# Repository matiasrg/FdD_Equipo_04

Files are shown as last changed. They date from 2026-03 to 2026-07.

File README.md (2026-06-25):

# FdD_Equipo_04

<strong> Carrera de Ingenieria Ambiental/ Informática / Industrial </strong>
<br>
Universidad Peruana Cayetano Heredia 

# Introducción
<br>
Actualmente, se observa una creciente preocupación en la población respecto a la desinformación o al escaso conocimiento sobre las condiciones climáticas, lo cual puede generar consecuencias en la salud, especialmente en la aparición o agravamiento de enfermedades. En ciudades como Lima, esta problemática se acentúa debido a los cambios climáticos repentinos e impredecibles, que dificultan que las personas sepan cómo prepararse adecuadamente antes de salir de casa.
<br>
<br>
Frente a esta situación, se propone el desarrollo de un dispositivo equipado con sensores de humedad, temperatura y radiación, capaz de recopilar datos ambientales en tiempo real. Esta información será transmitida mediante un módulo ESP32 a una aplicación móvil, la cual brindará recomendaciones personalizadas al usuario, como por ejemplo: “Recuerda aplicar bloqueador”, contribuyendo así a una mejor prevención y cuidado de la salud.

# Situación problemática
En la actualidad, se evidencia una creciente problemática relacionada con la falta de acceso a información ambiental confiable y en tiempo real. Muchas personas no cuentan con datos precisos sobre variables como la temperatura, la humedad o la radiación solar, lo que dificulta la toma de decisiones informadas para el cuidado de su salud.

Esta situación se agrava en ciudades como Lima, donde los cambios climáticos suelen ser repentinos e impredecibles, generando confusión en la población sobre cómo prepararse antes de salir de casa. Como consecuencia, se incrementa la exposición a riesgos como la radiación solar, cambios bruscos de temperatura o condiciones ambientales inadecuadas que pueden afectar el bienestar físico.

Además, la falta de información adecuada favorece la desinformación y limita la capacidad de las personas para tomar decisiones basadas en evidencia, ya que la información errónea o poco clara puede generar confusión, desconfianza y conductas inadecuadas frente al cuidado de la salud y el ambiente.[1]  ￼

En este contexto, se identifica una brecha importante entre la disponibilidad de datos ambientales y su acceso comprensible y útil para la población, lo cual impacta directamente en la salud (ODS 3), el consumo responsable (ODS 12) y la acción frente al cambio climático (ODS 13).
<br> 
# Problema integrador
<br>
A pesar de la disponibilidad de tecnologías capaces de medir variables ambientales como la temperatura, humedad y radiación solar, actualmente no existen soluciones accesibles e integradas que permitan recopilar, procesar y comunicar esta información en tiempo real de manera clara y útil para los usuarios.

Esta limitación impide que las personas tomen decisiones informadas sobre su cuidado diario, exponiéndolas a riesgos prevenibles y dificultando su adaptación a las condiciones climáticas cambiantes.

Por ello, surge la necesidad de desarrollar un sistema tecnológico que integre sensores ambientales con una plataforma digital capaz de transformar los datos obtenidos en recomendaciones prácticas, contribuyendo así a mejorar la calidad de vida y fomentar una mayor conciencia ambiental.

# Presentación de la solución 

La idea del proyecto es un aparato que tenga sensores de temperatura, humedad y radiación. Estos se comunican mediante el ESP32 a una aplicación móvil que da recomendaciones al usuario de tipo "recuerda aplicar bloqueador" o "no olvides tu abrigo".
<br>
<br>
<strong> Listas de exigencias que debemos cumplir: <strong>
<br>
1. Asumir el problema en forma crítica.
Estudiantes universitarios el Perú caminan mucho entre clases y paraderos bajo radiación UV extrema (índice 11+), humedad del 80% y temperaturas de 28-33°C, lo que causa quemaduras, deshidratación o golpes de calor; el problema es crítico porque no usan protección por falta de alertas inmediatas, agravado por el cambio climático que intensifica estos riesgos en la costa peruana.
2. Averiguar el estado de la tecnología.
El ESP32 ya integra WiFi/Bluetooth para apps móviles (como Blynk o MIT App Inventor), sensores como DHT22 (temperatura/humedad), SI1145 (UV/radiación); apps dan notificaciones push en tiempo real, con ejemplos como wearables UV (UVI Monitor) o estaciones meteorológicas portátiles, pero faltan soluciones integrales solares y locales para Perú.
3. Analizar la situación del problema.
En el Perú, la radiación alta por nubosidad engañosa (sensación térmica bochornosa), humedad costera y calor urbano afectan a 70% de jóvenes sin hábitos preventivos; ODS 13 aplica por adaptación climática, ODS 7 por recarga solar (reduce baterías desechables), ODS 12 por diseño modular.
4. Comprobar las posibilidades de realización.
Con respecto a los costos, esto es viable con ESP32 (costo $45), sensores ($20 c/u) y app gratuita; prototipo en 2 semanas con Arduino IDE; pruebas en Lima confirman precisión (DHT22 ±2%, SI1145 UVI ±10%); 
<br>

# 🌎 Descripción del grupo
Somos el equipo 04 del curso <strong> Fundamentos de diseño 2026-01 </strong>, ingenieria Informatica/Ambiental/Industrial. 
<br>
Nuestro objetivo es aplicar la metodología de diseño para generar soluciones innovadoras con impacto social, tecnológico y ambiental.
Nos interesa trabajar en los siguientes Objetivos de Desarrollo Sostenible (ODS):

ODS 3: Salud y bienestar
<br>
Al convertir datos ambientales en alertas personalizadas, ayudamos a los usuarios a protegerse antes de que el daño ocurra, contribuyendo así a la meta del ODS 3 de reducir enfermedades no transmisibles mediante la prevención y la promoción del bienestar.[2]

ODS 7: Energia asequible y no contaminante.
<br>
Para que nuestra propuesta sea coherente, promueve el uso eficiente de la energía. Al medir temperatura, humedad y radiación, permite que los usuarios tomen decisiones como reducir el uso de aire acondicionado, calefacción o iluminación artificial, disminuyendo así el consumo energético.[2]

<br>
ODS 12: Producción y consumo responsable.
<br>
<br>
Nuestra prioridad es prolongar la vida útil del equipo. En lugar de crear un producto desechable, nos inclinamos por un diseño reparable y reacondicionable. Esto significa que el aparato estará pensado para que sus piezas puedan ser revisadas o cambiadas fácilmente si se desgastan. Al evitar que el dispositivo se convierta en basura tecnológica prematura, fomentamos un consumo responsable donde la durabilidad es la característica principal, asegurando que la inversión de la comunidad rinda por mucho más tiempo.[2]

<br>
<br>
ODS 13: Acción por el clima
<br>
<br>
Queremos enfocarnos en combatir los efectos del cambio climático que afectan la salud física. Estamos expuestos constantemente a niveles de humedad y radiación que han dejado de ser normales. Nuestra intención es ofrecer una herramienta de protección que ayude a las personas a adaptarse a estos riesgos. Al transformar los datos del clima en alertas directas, permitimos que la gente tome acciones inmediatas para evitar daños por la exposición prolongada, enfrentando así las consecuencias reales del calentamiento global en nuestro entorno local.
<br>[2]

#  📸 Fotografia del equipo 
<p align="center">
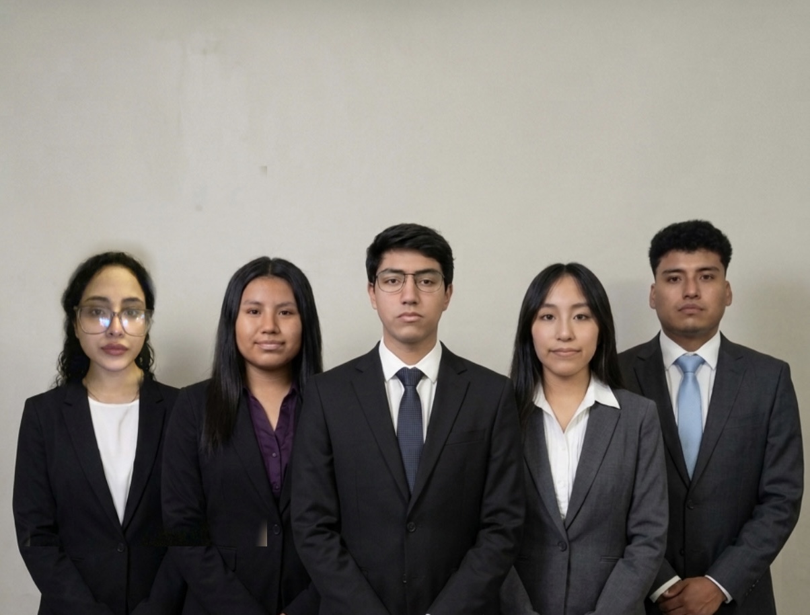
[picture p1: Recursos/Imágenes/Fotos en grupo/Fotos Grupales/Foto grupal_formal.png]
grupal

  <em>
  Figura 1. Fotografia del Equipo 4
</p>

#  👥  Integrantes del equipo 

| Foto | Nombre | Rol | Intereses | 
| ---- | --- | --- | --- |
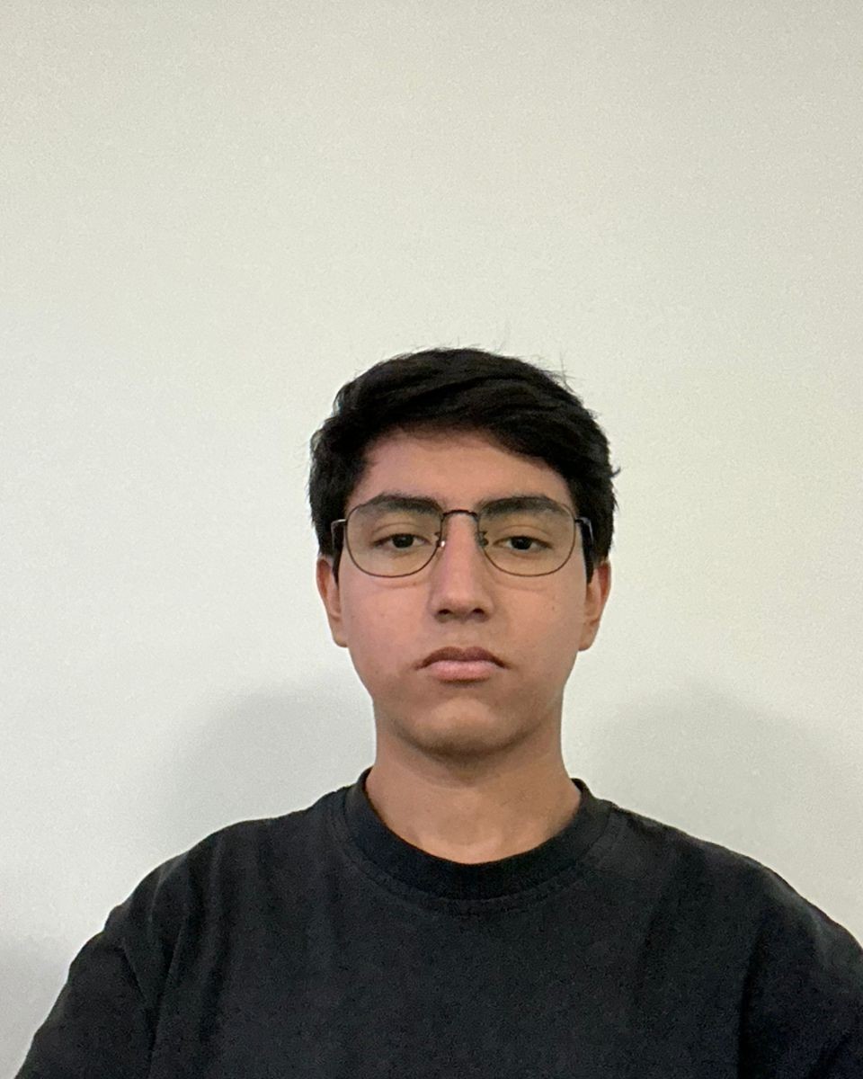
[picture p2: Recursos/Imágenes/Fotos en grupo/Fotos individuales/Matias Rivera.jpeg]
|  | Matías Rivera | Lider del grupo | Innovación social, sostenibilidad |
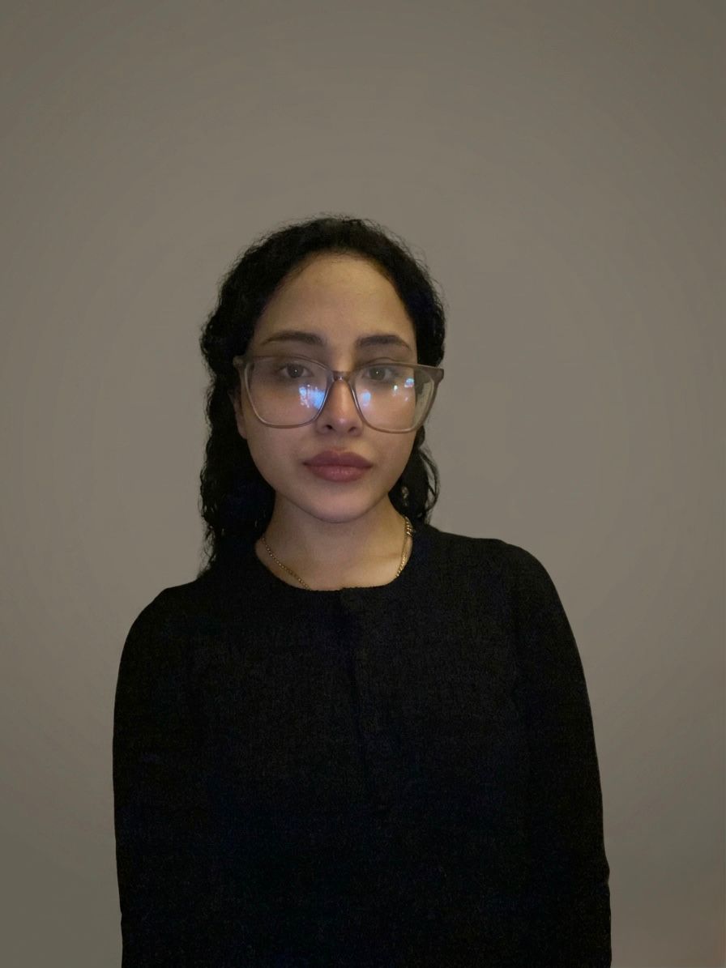
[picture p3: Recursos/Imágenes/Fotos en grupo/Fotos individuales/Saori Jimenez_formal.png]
|  | Saori Jiménez| Programador | Programación, análisis de datos, prototipado | 
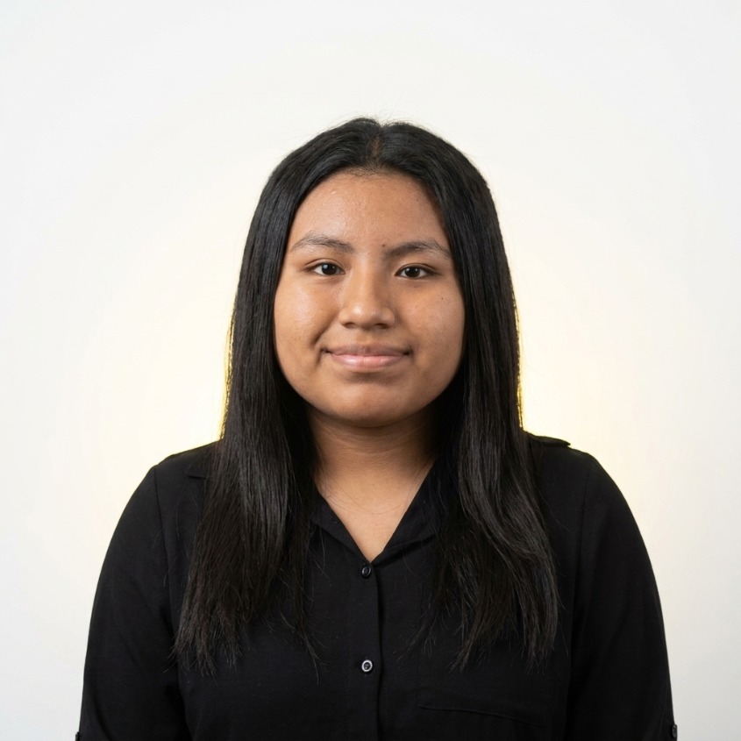
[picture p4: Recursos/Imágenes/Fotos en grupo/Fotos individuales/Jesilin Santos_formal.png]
| | Jesilin Santos| Responsable de investigación | Analisis de problemáticas, Enfoque de soluciones responsables | 
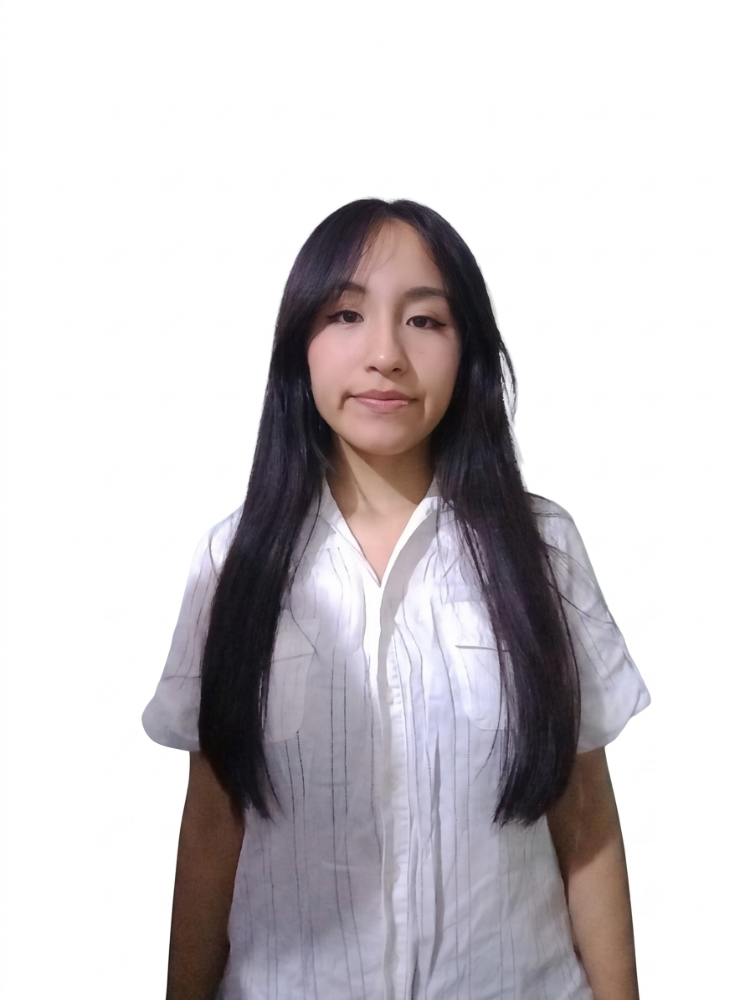
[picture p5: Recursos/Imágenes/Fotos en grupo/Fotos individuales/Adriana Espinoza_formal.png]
|  | Adriana Espinoza| Diseñadora | Prototipo y maquetas | Creatividad estetica |
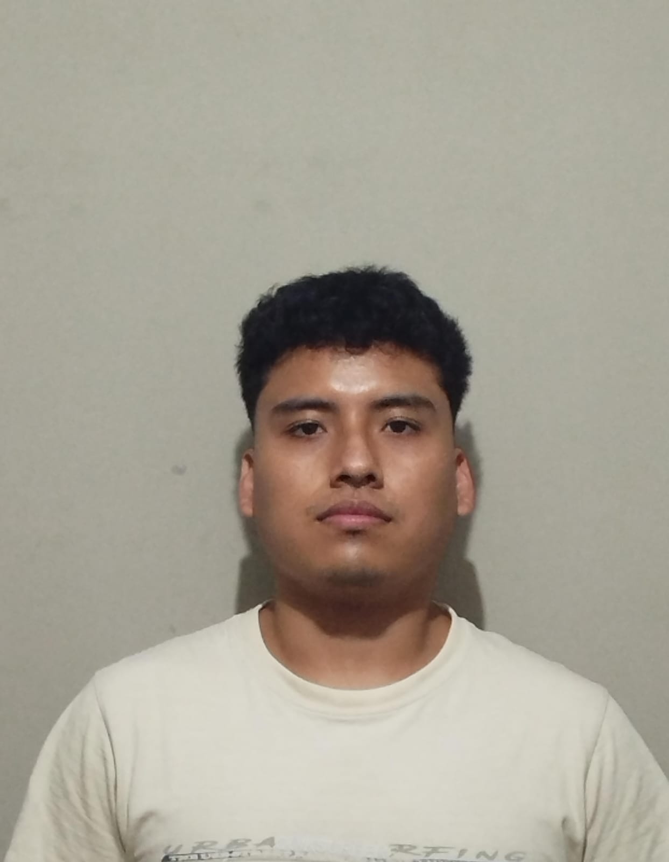
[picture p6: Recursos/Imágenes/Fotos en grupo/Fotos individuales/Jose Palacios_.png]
|  | Jose Palacios| Encargado/a de documentación | documentación científica, redacción técnica | 

# Referencias 
1. García-Delgado Giménez B, Revilla Guijarro A. Educación climática en la universidad: aplicación del Test CRAAP contra la desinformación. Rev Iberoam Educ. 2026;100(1):141-159.
https://rieoei.org/RIE/article/view/7135
2. Programa de las Naciones Unidas para el Desarrollo (PNUD). Objetivo 3: Salud y Bienestar. En: Objetivos de Desarrollo Sostenible [Internet]. Nueva York: PNUD; 2015 [citado 20 abr 2026]. Disponible en: https://www.undp.org/es/sustainable-development-goals

# 📌Resumen final 
Este README resume quiénes somos, qué nos motiva y en qué ODS queremos enfocar nuestro trabajo durante el curso

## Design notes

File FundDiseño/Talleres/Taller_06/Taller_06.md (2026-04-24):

# Matriz de desk research
| N° | Fuente | Autor/Institución | Año | Referencia | Estado de Tecnología encontrada | Exigencia o requisito identificado | Restricción o limitación | Función principal | Aplicación al proyecto |
|:--:|:---|:---|:--:|:---|:---|:---|:---|:---|:---|
| 1 | Guía internacional | OMS / OMM / PNUMA / ICNIRP | 2002/2003 | *Global Solar UV Index: A Practical Guide*:<br> https://www.who.int/publications/i/item/9241590076| Estándar internacional para medir y comunicar riesgo UV. Escala IUV 1–11+ con 5 categorías (bajo, moderado, alto, muy alto, extremo). Adoptado globalmente por servicios meteorológicos y autoridades sanitarias. | Usar la escala IUV como referencia oficial para alertas de salud pública; recomendar medidas de protección desde IUV ≥ 3; estandarizar colores y pictogramas de comunicación. | El sensor UV de bajo costo integrado al ESP32 puede no replicar con exactitud la escala IUV definida por la OMS; se requiere calibración y validación del sensor frente a mediciones de referencia. | Estandarización del índice UV para comunicación de riesgo al público y a autoridades sanitarias a escala mundial. | Define la escala que el sensor UV del dispositivo ESP32 debe usar para clasificar lecturas y generar recomendaciones personalizadas en la app. |
| 2 | Reglamento peruano | Estado Peruano – Diario Oficial El Peruano | 2024 | Decreto publicado en El Peruano (NL/2266130-1):<br> https://busquedas.elperuano.pe/dispositivo/NL/2266130-1 | Existen lineamientos para asegurar la calidad regulatoria, claridad y eficiencia en la implementación de soluciones tecnológicas en el ámbito público | - El sistema debe diseñarse de manera clara, eficiente y aplicable para su implementación en instituciones como universidades o municipalidades<br><br> - Identificar y alertar sobre el rango horario crítico (10:00–16:00 según la normativa) en el que se debe evitar la exposición. | Requiere validación institucional y adaptación a normativas locales. | Garantizar viabilidad y aplicación en el sector público | El proyecto se orienta a ser implementado como servicio en espacios públicos bajo regulación peruana |

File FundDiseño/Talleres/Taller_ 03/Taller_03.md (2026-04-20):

# Introducción

# Situación Problemática

En la actualidad, la exposición a condiciones ambientales adversas como la radiación ultravioleta, la alta humedad y las elevadas temperaturas representa un riesgo significativo para la salud, especialmente en zonas urbanas como Lima. La radiación UV, en particular, está asociada a efectos nocivos como quemaduras solares y un mayor riesgo de cáncer de piel, lo que hace fundamental la adopción de medidas preventivas oportunas [2,5]. Esta problemática se enmarca directamente en el ODS 3 (Salud y Bienestar), cuya meta 3.4 busca reducir la mortalidad prematura por enfermedades no transmisibles mediante la prevención y la promoción de la salud [9].

Sin embargo, muchas personas no cuentan con acceso a información ambiental clara, confiable y en tiempo real, lo que dificulta la toma de decisiones adecuadas para su protección. Esta situación se ve agravada por la desinformación y la falta de educación climática, limitando la capacidad de la población para actuar de manera preventiva frente a estos riesgos [1].

A pesar de que existen tecnologías capaces de medir variables como temperatura, humedad y radiación UV mediante sensores y sistemas IoT, estas soluciones no suelen estar integradas en herramientas accesibles y prácticas para el uso cotidiano [3,4,6]. Diversos estudios han demostrado que el monitoreo en tiempo real y el uso de alertas pueden mejorar significativamente la prevención, especialmente en jóvenes expuestos constantemente a estas condiciones [7,8].

Frente a esta problemática, el presente proyecto propone el desarrollo de un dispositivo portátil equipado con sensores ambientales y un módulo ESP32, capaz de recopilar datos en tiempo real y transmitirlos a una aplicación móvil. Esta aplicación procesará la información y brindará recomendaciones personalizadas al usuario, como el uso de bloqueador solar o abrigo, contribuyendo así a la prevención de riesgos, la mejora de la calidad de vida y la promoción de la conciencia ambiental. Con ello, el proyecto se alinea con el ODS 3, el ODS 12 (Producción y Consumo Responsable) y el ODS 13 (Acción por el Clima), siendo la prevención en salud su eje central. 

# Propuesta de solución
En respuesta a esta problemática, se plantea la necesidad de implementar un sistema tecnológico, cuyo enfoque está basado en la utilización de Internet de las Cosas (IoT), para realizar el monitoreo del ambiente en tiempo real y proporcionar recomendaciones personales acerca de cómo evitar riesgos a la salud. Para lograr este fin, se considerará la utilización de un pequeño dispositivo portátil, dotado con sensores de temperatura, humedad y radiación ultravioleta, conectado a un microcontrolador ESP32 capaz de transmitir los datos de estas mediciones.

Esta propuesta tecnológica se sustenta en los estudios existentes relacionados con soluciones IoT en el monitoreo ambiental que han resultado exitosos debido a su capacidad para recolectar información sobre variables climáticas en tiempo real y facilitar la toma de decisiones frente a situaciones adversas [4]. Por tanto, la implementación de un microcontrolador ESP32, por ejemplo, permitiría la transferencia inalámbrica de estos datos al usuario a través de una aplicación móvil.

En segundo lugar, la aplicación móvil que se asocia con el sistema deberá cumplir con la función primordial de analizar los datos recolectados e informar acerca de las recomendaciones personalizadas para el usuario, tales como aplicarse protector solar, hidratarse o protegerse frente a posibles variaciones de temperatura. Numerosos estudios han demostrado que la utilización de un sensor de radiación UV junto a una aplicación móvil puede aumentar de manera significativa las acciones de protección frente al sol, siendo particularmente efectiva para jóvenes gracias a sus alertas en tiempo real que evitan posibles quemaduras [8].

También teniendo en cuenta el entorno peruano, en el que la radiación solar es bastante alta durante todo el año, esta solución adquiere una relevancia especial. En Perú ha sido demostrada la importancia de la prevención y diagnóstico tempranos del melanoma cutáneo, con el uso de métodos preventivos basados en la educación para protegerse de los rayos solares [5]. Garantizar el acceso a herramientas de prevención accesibles para la población constituye, además, una contribución concreta al ODS 3, al reducir la exposición a riesgos ambientales que derivan en enfermedades prevenibles [9].

En general, esta propuesta intenta combinar la incorporación de tecnología fácil de usar, un sistema de monitoreo en tiempo real y medidas de prevención para la salud, no solo ayudando a minimizar los riesgos derivados de entornos adversos, sino que también promoviendo una mejor sensibilización ambiental y prácticas saludables.

# Objetivos
## Objetivo general
Diseñar e implementar un prototipo capaz de registrar y monitorear mediciones ambientales locales mediante sensores de temperatura, humedad y radiación UV integrados a un microcontrolador ESP32, y vinculado a una aplicación móvil que procese estos datos en tiempo real para brindar recomendaciones personalizadas de protección y prevención a los usuarios, promoviendo el cuidado de la salud en línea con el ODS 3, y la toma de decisiones informadas frente a condiciones ambientales adversas.
## Objetivos especificos
1. Averiguar el estado del arte en sistemas de monitoreo ambiental basados en IoT, sensores de temperatura, humedad y radiación; así como el uso del ESP32 en este ámbito.
2. Evaluar la viabilidad técnica y económica del desarrollo del prototipo que incluye ESP32, sensores, conectividad y plataforma de desarrollo.
3. Diseñar la arquitectura del sistema, definiendo la integración entre el hardware y la aplicación web/móvil.
4. Construir e implementar el prototipo físico.
5. Desarrollar la aplicación web/móvil que procese los datos recibidos y genere alertas y recomendaciones automáticas (ej. uso de bloqueador o abrigo)
6. Realizar pruebas experimentales en condiciones reales para verificar la transmisión de datos, estabilidad del sistema y respuesta de la aplicación.
7. Evaluar el desempeño del sistema analizando la precisión de los sensores, la eficiencia de la comunicación y la utilidad de las recomendaciones en la prevención de riesgos.

# Bibliografía

1. García-Delgado Giménez B, Revilla Guiijarro A. Educación climática en la universidad: aplicación del Test CRAAP contra la desinformación. RIEOEI [Internet]. 30 de enero de 2026 [citado 8 de abril de 2026];100(1):141-59. 
Disponible en: https://rieoei.org/RIE/article/view/7135

2. Organización Mundial de la Salud. Radiación ultravioleta: protección solar y prevención del cáncer de piel [Internet]. Ginebra: OMS; 2022 [citado 7 abr 2026]. Disponible en: https://www.who.int/news-room/fact-sheets/detail/ultraviolet-radiation

3. Alquinga Arequipa FC, Triviño D. Desarrollo e implementación de un dispositivo “Wearable” para el análisis de temperatura, humedad, incidencia de rayos ultravioletas (UV) y presión atmosférica para personas que realizan montañismo. Quito: Escuela Politécnica del Ejército (ESPE); 2017. Disponible en: https://redi.cedia.edu.ec/document/116763.

4. Desarrollo de una estación IoT para monitoreo de microclimas y condiciones del suelo. Rev Ing UPT. 2021. Disponible en: https://revistas.upt.edu.pe/ojs/index.php/ingenieria/article/download/1167/1058.

5. Sordo C, Gutiérrez C. Cáncer de piel y radiación solar: experiencia peruana en la prevención y detección temprana del cáncer de piel y melanoma. Rev Peru Med Exp Salud Publica [Internet]. 2013;30(1):106-12. Disponible en: http://www.scielo.org.pe/scielo.php?script=sci_arttext&pid=S1726-46342013000100021&lng=es.

6. Huallpa Huayhua JE, Ayerbe Huarcaya CI. Sistema basado en IOT para monitoreo de parámetros ambientales en crianza de pollos en el IESTP Jorge Basadre Grohman, 2024 [tesis en Internet]. Puerto Maldonado (Madre de Dios, Perú): Universidad Nacional Amazónica de Madre de Dios (UNAMAD); 2024. Disponible en: http://hdl.handle.net/20.500.14070/1460

7. Bhosale P, Kalgaonkar S, Jain D, Bhagwat A. IoT-Based Environmental Monitoring: Tracking Climate Change and Promoting Sustainable Development. En: Internet of Things for Smart Cities and Urban Development [Internet]. Chapman and Hall/CRC; 2025. Disponible en: https://www.taylorfrancis.com/books/9781003539629/chapters/10.1201/9781003539629-3

8. Robinson JK, et al. Real-time UV measurement with a sun protection system for warning young adults about sunburn: prospective cohort study. JMIR mHealth and uHealth. 2016;4(3). Disponible en: https://mhealth.jmir.org/2021/5/e25895

9. Programa de las Naciones Unidas para el Desarrollo (PNUD). Objetivo 3: Salud y Bienestar. En: Objetivos de Desarrollo Sostenible [Internet]. Nueva York: PNUD; 2015 [citado 20 abr 2026]. Disponible en: https://www.undp.org/es/sustainable-development-goals

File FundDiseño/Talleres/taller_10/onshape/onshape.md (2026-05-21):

https://cad.onshape.com/documents/f9a615fb81c0a29481f81119/w/910e831ae7aa793d391d0c5f/e/6db22efc34afd249ac153ec0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

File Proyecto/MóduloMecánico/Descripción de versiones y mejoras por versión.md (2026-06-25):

# Módulo Mecánico - EcoAlerta

## Evolución del Diseño Mecánico y Consolidación de Versiones

El desarrollo del chasis y los componentes de sujeción del dispositivo **EcoAlerta** se estructuró en dos etapas de diseño (v1 y v2), evolucionando desde una distribución analítica de componentes separados hasta un ensamblaje final integrado y acotado para manufactura.

### Versión 1 (v1): Configuración Base y Distribución Espacial
En esta primera etapa se validaron los volúmenes, la distribución interna y las aberturas necesarias para la interacción de los componentes con el entorno:
* **Estructura por Bloques Separados:** Configuración del contenedor principal dividiendo el espacio para alojar de forma independiente los sistemas de energía, control y sensado.
* **Circulación de Aire:** Inclusión de rejillas lineales directamente en el chasis exterior para permitir la ventilación pasiva y la renovación del aire interno.
* **Cavidades de Control e Interfaz:** Apertura de agujeros iniciales destinados a la instalación de un botón de encendido/apagado, fijaciones para tornillos de cierre y perforaciones para el paso de cables mediante prensaestopas.
* **Ventana de Monitoreo UV:** Maquetado de los primeros agujeros en la sección superior de la tapa de los sensores para permitir la exposición del sensor de radiación ultravioleta.

### Versión 2 (vfinal) - Versión Final: Ajustes de Chasis e Integración de Componentes
La v2 constituye el diseño final consolidado. En esta fase se aplicaron las correcciones de tolerancia milimétrica y se incorporaron físicamente todos los elementos comerciales y de hardware dentro del entorno 3D:
* **Estandarización de Perforaciones de Salida:** Ajuste y calibración exacta de los agujeros del contenedor para albergar de forma hermética prensaestopas comerciales de tipo PG7.
* **Ajuste para conector de chasis y switch:** Modificación de las aberturas del panel frontal para asegurar el calce perfecto de un conector de alimentación USB Tipo-C de empotrar y un interruptor general (switch) basculante.
* **Rediseño del Acoplamiento UV:** Modificaciones geométricas en la tapa de los sensores mediante un rebaje circular escalonado para lograr un acoplamiento estanco y seguro del sensor UV, garantizando que quede alineado y protegido frente al exterior.
* **Consolidación del Ensamblaje Electromecánico:** Inclusión real de la arquitectura interna completa dentro del modelo final. Esto abarca el posicionamiento exacto de los prensaestopas, el conector de chasis, el switch, la placa de soporte perforada, el sensor UV y el sensor de temperatura/humedad DHT11.
* **División Estructural de Tapas:** Configuración definitiva de la cubierta superior dividida en dos piezas independientes (Tapa del ESP32 y Tapa de los sensores), optimizando el acceso por separado a la electrónica de procesamiento o al módulo de sensores durante tareas de mantenimiento.

Enlace de Onshape: 
[https://cad.onshape.com/documents/be05ffe52afa9a955caa7767/w/59e88b758aaaabc94f50e5dc/e/23231b023377f0eafd262c30](https://cad.onshape.com/documents/be05ffe52afa9a955caa7767/w/59e88b758aaaabc94f50e5dc/e/23231b023377f0eafd262c30)

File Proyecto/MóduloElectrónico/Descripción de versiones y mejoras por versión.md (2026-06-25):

# Descripción de versiones y mejoras por versión

> Historial de evolución del esquemático electrónico del proyecto EcoAlerta, sistema portátil de monitoreo UV y ambiental basado en ESP32.

---

## Tabla comparativa

| Versión | Microcontrolador | Cambio principal | Bloques presentes |
|---|---|---|---|
| V1.0 | ESP32-DEVKITC-VE | Esquema inicial funcional, con conectores redundantes | Alimentación, Sensor UV, Sensor Temp/Hum, Microcontrolador, Conector Principal, Conector Temp/Hum |
| V2.0 | ESP32-DEVKITC-VE | Limpieza del esquema: se eliminan conectores duplicados | Alimentación, Sensor UV, Sensor Temp/Hum, Microcontrolador |
| V3.0 | ESP32-DEVKITC-VE | Se incorpora el indicador LED | Alimentación, Sensor UV, Sensor Temp/Hum, Microcontrolador, Led |
| V4.0 | ESP32S (U1) | Cambio de microcontrolador y se agrega el interruptor general | Alimentación, Sensor UV, Sensor Temp/Hum, Microcontrolador, Led, Bornera del interruptor, Interruptor |
| V_FINAL | ESP32S (U1) | Se retira el LED indicador, queda la versión definitiva | Alimentación, Sensor UV, Sensor Temp/Hum, Microcontrolador, Bornera del interruptor, Interruptor |

## Versión 1.0

### Descripción

Es la primera versión funcional completa del esquemático de EcoAlerta. Integra el ESP32-DEVKITC-VE (U15) como unidad de control, conectado al sensor de temperatura y humedad (U2) y al sensor UV (U3), además del bloque de alimentación (P1, "FUENTE"). A diferencia de las versiones posteriores, esta versión documenta las mismas señales dos veces: además del bloque "Microcontrolador" y "Sensor de Temperatura y Humedad", existen dos bloques adicionales — "Conector Principal" (U11/J2) y "Conector Temp/Hum" (U16/J1) — que repiten las líneas 3.3V, DATA-TEMP-HUM y GND ya presentes en otros bloques, sin aportar una función eléctrica nueva.

### Elementos característicos de esta versión

- Microcontrolador ESP32-DEVKITC-VE (U15) con su pinout completo de 38 pines.
- Bloques redundantes "Conector Principal" (U11) y "Conector Temp/Hum" (U16), que duplican señales ya presentes en el bloque del sensor de temperatura/humedad.
- No existe bloque de LED indicador.
- No existe interruptor general ni bornera dedicada para él.

---

## Versión 2.0

### Descripción

Se simplifica el esquemático eliminando la duplicación de conectores presente en V1.0. Se mantiene exactamente la misma arquitectura funcional (ESP32-DEVKITC-VE, sensor UV, sensor de temperatura y humedad, alimentación), pero ahora cada señal aparece documentada una sola vez, en su bloque correspondiente.

### Mejoras respecto a la Versión 1.0

- Se eliminan los bloques "Conector Principal" (U11) y "Conector Temp/Hum" (U16), que eran redundantes.
- El esquema queda reducido a cuatro bloques funcionales: Alimentación, Sensor UV, Sensor de Temperatura y Humedad, y Microcontrolador.
- No hay cambios en el microcontrolador ni en los sensores utilizados.

---

## Versión 3.0

### Descripción

Se mantiene la base de V2.0 y se incorpora por primera vez un indicador visual: el bloque "Led" (LED1) con su resistencia limitadora R1 de 10K, conectado directamente a +3.3V. En esta versión el LED todavía no recibe una señal de control independiente desde el ESP32; su encendido depende únicamente de la alimentación de 3.3V.

### Mejoras respecto a la Versión 2.0

- Se añade el bloque "Led" (LED1 + R1 de 10K) como indicador visual del sistema.
- El LED se alimenta desde +3.3V, sin una línea de control dedicada desde el microcontrolador todavía.
- Se mantiene sin cambios el resto de la arquitectura (ESP32-DEVKITC-VE, Sensor UV, Sensor de Temperatura y Humedad, Alimentación).

---

## Versión 4.0

### Descripción

Esta versión introduce dos cambios importantes. Primero, se reemplaza el microcontrolador ESP32-DEVKITC-VE por un módulo ESP32S (U1), con un pinout distinto (D-prefijo en lugar de IO-prefijo). Segundo, se agregan los elementos de interacción manual del sistema: un interruptor general con su propia bornera ("Bornera del interruptor" y "Interruptor"), que permite energizar o desenergizar el circuito entre la línea de +5V del ESP32 y la línea de +5V general. Además, el bloque LED ya no se alimenta de forma fija a 3.3V: ahora recibe una señal de control propia ("LED") directamente desde un pin del ESP32S, lo que permite encenderlo o apagarlo por software.

### Mejoras respecto a la Versión 3.0

- Se reemplaza el microcontrolador ESP32-DEVKITC-VE por el módulo ESP32S (U1).
- Se agregan los bloques "Bornera del interruptor" e "Interruptor", que permiten energizar/desenergizar el circuito manualmente.
- El LED indicador pasa de estar alimentado fijo a 3.3V (V3.0) a recibir una señal de control dedicada desde un pin del ESP32S.
- Se mantienen sin cambios los bloques de Alimentación, Sensor UV y Sensor de Temperatura y Humedad.

---

## Versión Final

### Descripción

Es la versión consolidada para la entrega del proyecto. Mantiene la arquitectura de V4.0 (ESP32S, interruptor general con bornera dedicada, sensores UV y de temperatura/humedad), pero retira por completo el bloque "Led": ya no están presentes ni LED1, ni la resistencia R1, ni la señal de control "LED" en el microcontrolador. El sistema queda definido sin indicador visual a nivel de hardware.

### Mejoras respecto a la Versión 4.0

- Se elimina el bloque "Led" (LED1 y R1 de 10K) y su señal de control dedicada en el ESP32S.
- Se mantienen sin cambios el microcontrolador ESP32S, el interruptor general con su bornera, y los bloques de Sensor UV, Sensor de Temperatura y Humedad, y Alimentación.
- El esquemático queda con seis bloques funcionales: Alimentación, Sensor UV, Sensor de Temperatura y Humedad, Microcontrolador, Bornera del interruptor e Interruptor.

---

## Conclusiones

La evolución del esquemático de EcoAlerta refleja un proceso de diseño iterativo que pasó primero por una etapa de depuración (eliminar conectores redundantes en V2.0), luego por una etapa de incorporación de funciones (LED indicador en V3.0, interruptor general y cambio de microcontrolador en V4.0), y finalmente por una etapa de simplificación del hardware final, donde se decidió retirar el LED indicador para quedarse con un diseño más acotado a las funciones esenciales del sistema: medición UV, medición de temperatura y humedad, alimentación y control manual de encendido mediante el interruptor general.

El cambio más relevante a nivel de plataforma es la migración del ESP32-DEVKITC-VE (V1.0–V3.0) al módulo ESP32S (V4.0–V_FINAL), que coincide con la incorporación del interruptor general como mecanismo de control manual del sistema.

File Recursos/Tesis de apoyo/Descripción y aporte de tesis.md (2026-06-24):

# Descripción y aporte de tesis

> Revisión de tesis de repositorios académicos peruanos relacionadas con monitoreo UV y sistemas IoT ambientales, como respaldo de la viabilidad técnica y contextual de EcoAlerta.

---

## Tabla comparativa

| Tesis | Autor / Año | Institución | Enfoque | Tecnología clave |
|---|---|---|---|---|
| Sistema de sensores inalámbricos para el monitoreo del índice de radiación solar ultravioleta de la ciudad de Huancavelica | Carlos Gonzáles Saenz, 2022 | Universidad Nacional del Centro del Perú | Red de sensores UV en zona altoandina | Nodos inalámbricos UV (ML8511 / LTR390) |
| Sistema basado en IoT para monitoreo de parámetros ambientales en crianza de pollos en el IESTP Jorge Basadre Grohmann | Huallpa Huayhua, 2024 | IESTP Jorge Basadre Grohmann | Monitoreo ambiental en crianza avícola | ESP32 + DHT22 + MQ-135 + MQTT |

## 1. Sistema de sensores inalámbricos para el monitoreo del índice de radiación solar ultravioleta de la ciudad de Huancavelica

**Autor:** Carlos Gonzáles Saenz | **Año:** 2022 | **Institución:** Universidad Nacional del Centro del Perú

### Descripción

Estudio de campo sobre el uso de sensores UV inalámbricos para medir el índice de radiación UV local en la ciudad de Huancavelica. Busca compensar la falta de datos puntuales en zonas altoandinas, donde la radiación alcanza niveles extremos. Se despliegan varios nodos de sensor UV en puntos representativos de la ciudad, cada uno registrando mediciones cada 5 minutos en tiempo real. La validación de los datos se hace mediante métodos estadísticos: correlación de Spearman para precisión y prueba de Kruskal-Wallis para repetitividad temporal.

### Aporte para EcoAlerta

Esta tesis es clave porque corrobora en contexto peruano que los sensores UV portátiles pueden ofrecer mediciones de alta precisión, lo cual es transferible a la calibración de los sensores ML8511/LTR390 que el equipo considera para el prototipo. Además, su enfoque local en una zona de microclima extremo demuestra que la variabilidad climática es un problema real y vigente en el Perú, dando relevancia geográfica a la propuesta de EcoAlerta. También aporta una metodología de validación estadística replicable (Spearman y Kruskal-Wallis) que el equipo puede usar como referencia al validar la precisión de su propio prototipo.

**Aportes concretos:**
- Validación de sensores ML8511/LTR390 en condiciones peruanas reales.
- Protocolo estadístico de validación de precisión y repetitividad.
- Evidencia de que la variabilidad de microclima en Perú es un problema medible y relevante.

## 2. Sistema basado en IoT para monitoreo de parámetros ambientales en crianza de pollos en el IESTP Jorge Basadre Grohmann

**Autor:** Huallpa Huayhua | **Año:** 2024 | **Institución:** Instituto de Educación Superior Tecnológico Público Jorge Basadre Grohmann

### Descripción

Propone el diseño e implementación de un sistema IoT para el monitoreo continuo de temperatura, humedad y calidad del aire en un ambiente de crianza avícola. El sistema integra sensores conectados a un microcontrolador ESP32, que transmite datos en tiempo real vía Wi-Fi a un servidor MQTT y los visualiza en un dashboard. Se realizaron pruebas de calibración comparando las lecturas de los sensores con instrumentos de referencia certificados.

### Aporte para EcoAlerta

Esta tesis valida directamente la arquitectura técnica que el equipo propone: ESP32, sensores de temperatura y humedad, transmisión MQTT y visualización en tiempo real. Demuestra que este tipo de sistemas son replicables con bajo costo y sin infraestructura compleja, lo que refuerza la viabilidad del prototipo en un contexto universitario peruano con recursos limitados. Su experiencia con el sensor DHT22 también es transferible a EcoAlerta, ya que el equipo considera sensores de la misma familia para su propio diseño.

**Aportes concretos:**
- Validación práctica de la arquitectura ESP32 + MQTT en un caso real peruano.
- Confirmación de bajo costo y baja complejidad de infraestructura para implementación.
- Experiencia transferible con el sensor DHT22, usado también en EcoAlerta.

## Síntesis general

| Aporte | Gonzáles Saenz (2022) | Huallpa Huayhua (2024) |
|---|---|---|
| Validación de sensores UV en contexto peruano | Sí | No aplica |
| Validación de arquitectura ESP32 + MQTT | No aplica | Sí |
| Metodología estadística de precisión replicable | Sí (Spearman / Kruskal-Wallis) | Sí (comparación con instrumentos certificados) |
| Transferencia directa de sensores al proyecto | ML8511 / LTR390 | DHT22 |
| Evidencia de bajo costo y viabilidad local | Sí | Sí |

Ambas tesis, aunque pertenecen a dominios de aplicación distintos (radiación solar urbana frente a crianza avícola), convergen en validar los mismos componentes técnicos que sustentan EcoAlerta: sensores de bajo costo, arquitectura ESP32/IoT y métodos de validación estadística rigurosos, todo dentro de un contexto peruano real y replicable.

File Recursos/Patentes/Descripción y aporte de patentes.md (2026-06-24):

# Descripción y aporte de patentes

> Revisión de patentes relacionadas con monitoreo de radiación UV, sistemas IoT ambientales y dispositivos portátiles de exposición lumínica. Esta sección documenta las patentes identificadas como antecedentes tecnológicos relevantes para el desarrollo de EcoAlerta, un sistema portátil basado en ESP32 orientado a estudiantes universitarios en entornos urbanos.

---

## Tabla resumen

| Patente | Código / Año | Enfoque principal | Relación con EcoAlerta |
|---|---|---|---|
| UV light monitoring system for a UV decontamination apparatus | US12409241B2 / 2025 | Medición de dosis UV en entornos de desinfección controlados | Baja, ya que es un contexto industrial y no urbano |
| Monitoring and Early Warning Device for Climate Comfort of Urban Green Space Water Bodies | CN223827091U / 2024 | Monitoreo climático multiparamétrico en espacios urbanos | Media, comparte sensores ambientales pero con distinto enfoque |
| Sistema, dispositivo y métodos para el seguimiento de la exposición a la luz | US11579015B2 / 2023 | Wearable de exposición lumínica con conectividad inalámbrica | Alta, el objetivo es casi idéntico pero sin recomendaciones en tiempo real |

## 1. UV light monitoring system for a UV decontamination apparatus

**Código:** US12409241B2 | **Año:** 2025

### Descripción

Sistema diseñado para monitorear luz ultravioleta en entornos de desinfección. Su objetivo es estimar con precisión la irradiancia UV que recibe una superficie, incluso en ángulos arbitrarios respecto a la fuente de emisión. Para lograrlo, combina un sensor UV con dos celdas solares ubicadas en distintas caras del monitor, lo que permite determinar la orientación del dispositivo y calcular la dosis real de radiación recibida por el objetivo.

### Aporte para EcoAlerta

Refuerza el principio de medir radiación UV de forma remota para evaluar exposición sobre una superficie o área de interés, y la necesidad de procesar esos datos para apoyar decisiones informadas. Estos son dos pilares centrales del proyecto. Sin embargo, es una solución muy especializada para entornos controlados donde la orientación del sensor es crítica para garantizar una dosis mínima de desinfección, mientras que EcoAlerta está pensado para un usuario en movimiento en espacios urbanos abiertos. Esta diferencia de contexto operativo confirma que no existe una solución directa equivalente en el mercado de patentes para el caso de uso propuesto.

| Aspecto | Detalle |
|---|---|
| Similitudes | Medición remota de radiación UV y procesamiento de datos para decisiones |
| Diferencias | Entorno controlado de desinfección frente a usuario móvil en entorno urbano |
| Brecha que confirma | Falta de soluciones orientadas a movilidad y vida cotidiana |

## 2. Monitoring and Early Warning Device for Climate Comfort of Urban Green Space Water Bodies

**Código:** CN223827091U | **Año:** 2024

### Descripción

Dispositivo de monitoreo y alerta temprana para evaluar condiciones de confort climático en espacios urbanos y cuerpos de agua. Integra sensores de intensidad lumínica, temperatura, humedad, velocidad del viento y precipitación, recopilando información ambiental en tiempo real a través de componentes electrónicos conectados a un sistema de adquisición de datos. Incluye además módulos de comunicación, mecanismos de protección eléctrica y estructuras adaptables para operar en exteriores.

### Aporte para EcoAlerta

Esta patente valida el uso de sensores ambientales combinados (luz, temperatura, humedad) y de sistemas electrónicos de adquisición y transmisión de datos orientados a la prevención de riesgos en espacios urbanos, que es exactamente el tipo de arquitectura que plantea EcoAlerta. La diferencia clave es el alcance: esta patente añade sensores de viento y precipitación y se enfoca en cuerpos de agua urbanos, mientras que EcoAlerta se concentra específicamente en radiación UV con recomendaciones preventivas para estudiantes universitarios, usando una arquitectura IoT compacta basada en ESP32 y aplicación móvil para alertas personalizadas, un nivel de personalización que esta patente no contempla.

| Aspecto | Detalle |
|---|---|
| Similitudes | Sensores ambientales múltiples, monitoreo urbano en tiempo real, prevención de riesgos |
| Diferencias | Incluye viento, precipitación y cuerpos de agua, sin enfoque en UV ni en usuario individual |
| Brecha que confirma | Ausencia de personalización por usuario y de enfoque específico en radiación UV |

## 3. Sistema, dispositivo y métodos para el seguimiento de la exposición a la luz

**Código:** US11579015B2 | **Año:** 2023

### Descripción

Dispositivo portátil equipado con múltiples sensores de exposición lumínica. Incorpora conectividad inalámbrica (Bluetooth/Wi-Fi) y un sistema controlador que permite almacenar y procesar datos de irradiancia UV recibida por el usuario, con el objetivo de generar un registro continuo de exposición acumulada.

### Aporte para EcoAlerta

Es la patente más cercana al objetivo del proyecto, ya que comparte el mismo propósito central (monitorear la exposición UV del usuario en tiempo real) y el mismo mecanismo de transmisión (conectividad inalámbrica), validando así la dirección técnica tomada por el equipo con el ESP32. Su limitación principal, y a la vez la oportunidad de innovación que aprovecha EcoAlerta, es que no genera recomendaciones personalizadas en tiempo real para el usuario final, pues está orientada al seguimiento clínico acumulado y no contempla contextos urbanos dinámicos ni la integración de variables adicionales como temperatura y humedad.

| Aspecto | Detalle |
|---|---|
| Similitudes | Objetivo idéntico de monitoreo UV y conectividad inalámbrica para transmisión |
| Diferencias | Sin recomendaciones personalizadas en tiempo real, enfoque clínico y no urbano dinámico |
| Brecha que confirma | Falta de inteligencia y recomendación en tiempo real, además de variables ambientales adicionales |

## Síntesis general

Las tres patentes revisadas confirman que existen antecedentes técnicos sólidos para medir radiación UV y transmitir datos ambientales de forma inalámbrica, pero ninguna combina estos tres elementos a la vez:

- Monitoreo específico de radiación UV.
- Integración con variables de temperatura y humedad.
- Generación de recomendaciones personalizadas en tiempo real para un usuario en movimiento en un entorno urbano.

Esta combinación inexistente en el panorama de patentes es precisamente la brecha que EcoAlerta busca cubrir.

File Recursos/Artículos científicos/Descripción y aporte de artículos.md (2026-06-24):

# Descripción y aporte de artículos

> Revisión de literatura científica sobre arquitecturas IoT ambientales y dispositivos wearables, como respaldo técnico y académico de la propuesta EcoAlerta
---

## Tabla comparativa

| Artículo | Autores / Año | Revista | Enfoque | Hallazgo clave |
|---|---|---|---|---|
| IoT-based indoor environmental monitoring system using multi-parameter sensing and ESP32-WROOM integration | Bakare & Abubaker, 2026 | Discover Electronics | Sistema IoT multiparamétrico con ESP32 | Error menor a 2%, correlación mayor a 0.98, latencia de 215 a 310 ms vía MQTT |
| Wearable Devices for Environmental Monitoring in the Built Environment: A Systematic Review | Salamone, Masullo & Sibilio, 2021 | Sensors (MDPI) | Revisión sistemática de wearables ambientales | Validación consolidada del uso de sensores junto con comunicación inalámbrica para salud preventiva |

## 1. IoT-based indoor environmental monitoring system using multi-parameter sensing and ESP32-WROOM integration

**Autores:** Mutiu Shola Bakare y Kazibwe Abubaker | **Año:** 2026 | **Revista:** Discover Electronics

### Descripción

Desarrolla un sistema IoT basado en ESP32 capaz de medir simultáneamente temperatura, humedad, iluminación y calidad del aire. El sistema utiliza el protocolo MQTT para transmitir datos en tiempo real a la nube, logrando baja latencia (aproximadamente 215 a 310 ms). Implementa una arquitectura escalable con procesamiento tanto en la nube como en el propio dispositivo (edge computing), y reporta errores de medición menores al 2% con coeficientes de correlación superiores a 0.98.

### Aporte para EcoAlerta

Este artículo es uno de los respaldos técnicos más sólidos del proyecto, ya que valida directamente el uso del ESP32 como núcleo de sistemas IoT ambientales, que es exactamente la arquitectura que el equipo propone. Demuestra además que es viable integrar múltiples sensores y transmitir datos en tiempo real hacia plataformas digitales con alta precisión y baja latencia, reforzando la idea de convertir datos ambientales en información útil y procesable para el usuario, que es el objetivo central de EcoAlerta al generar recomendaciones personalizadas. También evidencia que estos sistemas pueden ser económicos, energéticamente eficientes y escalables, lo cual respalda la factibilidad técnica y financiera del prototipo.

**Hallazgos aplicables al proyecto:**
- ESP32 validado como núcleo de sistemas IoT ambientales multiparamétricos.
- MQTT como protocolo eficiente para transmisión en tiempo real con baja latencia.
- Arquitectura edge y cloud computing aplicable al diseño del prototipo.
- Alta precisión de medición (error menor a 2%) alcanzable con sensores de bajo costo.

## 2. Wearable Devices for Environmental Monitoring in the Built Environment: A Systematic Review

**Autores:** Salamone, F., Masullo, M., & Sibilio, S. | **Año:** 2021 | **Revista:** Sensors (MDPI)

### Descripción

Revisión sistemática que analiza cómo los dispositivos IoT y wearables modernos integran sensores de intensidad lumínica, temperatura, humedad y calidad del aire para permitir monitoreo continuo en tiempo real. El estudio concluye que la combinación de microcontroladores, sensores y comunicación inalámbrica mejora significativamente la capacidad de supervisar condiciones ambientales y generar alertas preventivas, y que estos sistemas pueden operar con bajo consumo energético en dispositivos portátiles.

### Aporte para EcoAlerta

Brinda sustento científico consolidado, al tratarse de una revisión sistemática y no de un solo estudio, para la integración de sensores ambientales dentro de un sistema IoT portátil como EcoAlerta. Respalda específicamente el uso de sensores de temperatura, humedad e intensidad lumínica como herramientas efectivas para evaluar condiciones relacionadas con exposición solar y confort climático, y valida el uso de tecnologías inalámbricas para transmitir esa información hacia aplicaciones móviles. Su aporte más relevante para la justificación del proyecto es de salud preventiva, ya que confirma que transformar datos ambientales en alertas tempranas contribuye efectivamente a proteger a las personas en espacios urbanos y académicos, que es exactamente el objetivo declarado de EcoAlerta para estudiantes universitarios.

**Hallazgos aplicables al proyecto:**
- Evidencia consolidada (revisión sistemática) sobre eficacia de wearables ambientales.
- Validación del uso combinado de sensores y comunicación inalámbrica para alertas preventivas.
- Confirmación de bajo consumo energético en dispositivos portátiles IoT.
- Sustento directo para el enfoque de salud preventiva del proyecto.

## Síntesis general

| Aporte | Bakare & Abubaker (2026) | Salamone et al. (2021) |
|---|---|---|
| Validación técnica de ESP32 | Directa | General (microcontroladores) |
| Validación de protocolo de transmisión (MQTT) | Sí | No específico |
| Precisión cuantificada de sensores | Sí (error menor a 2%) | No cuantificado |
| Respaldo en salud preventiva | Implícito | Explícito |
| Tipo de evidencia | Estudio experimental individual | Revisión sistemática (mayor robustez) |

Juntos, ambos artículos cubren los dos pilares científicos de EcoAlerta. Por un lado está la viabilidad técnica concreta de una arquitectura ESP32 con sensores y transmisión en tiempo real con métricas de precisión cuantificadas, y por otro está el respaldo consolidado a nivel de literatura sobre la efectividad de wearables ambientales para salud preventiva. En conjunto, confirman que la base tecnológica de EcoAlerta está alineada con la evidencia científica disponible y que la brecha que el proyecto busca cubrir, un monitoreo UV personalizado con recomendaciones en tiempo real, es consistente con las tendencias de investigación actuales.

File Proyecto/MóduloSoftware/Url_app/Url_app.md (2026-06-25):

# Carpeta comprmida de proyecto de Flutter: https://drive.google.com/file/d/1fx_svgnmCogcxOKCSN9IGW5vEMioEafN/view?usp=sharing

# Link a dashboard de Pocketbase: https://usingpocketbasev1-production.up.railway.app/_

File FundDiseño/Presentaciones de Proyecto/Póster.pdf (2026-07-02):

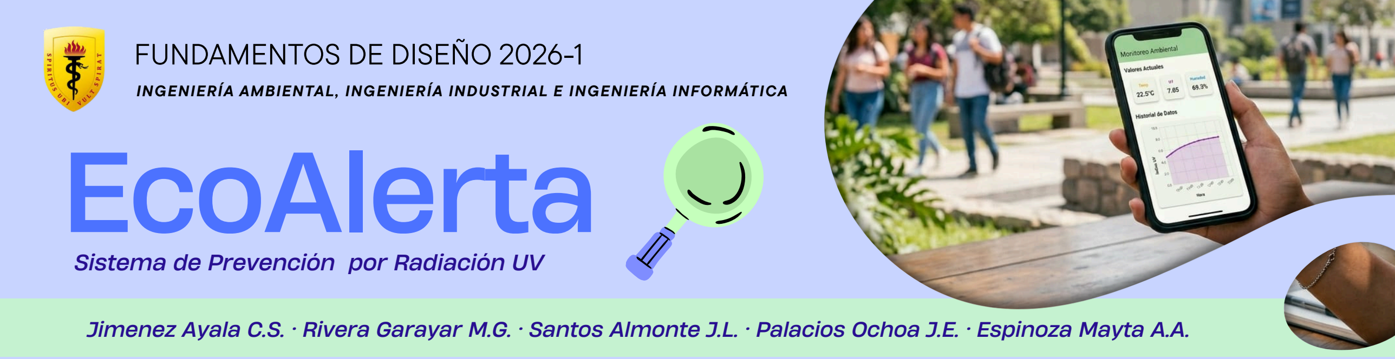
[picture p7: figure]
EcoAlerta; Sistema de Prevención por Radiación UV; FUNDAMENTOS DE DISEÑO 2026-1; Jimenez Ayala C.S.; · Rivera Garayar M.G.; · Santos Almonte J.L.; · Palacios Ochoa J.E.; · Espinoza Mayta A.A.

INGENIERÍA AMBIENTAL, INGENIERÍA INDUSTRIAL E INGENIERÍA INFORMÁTICA

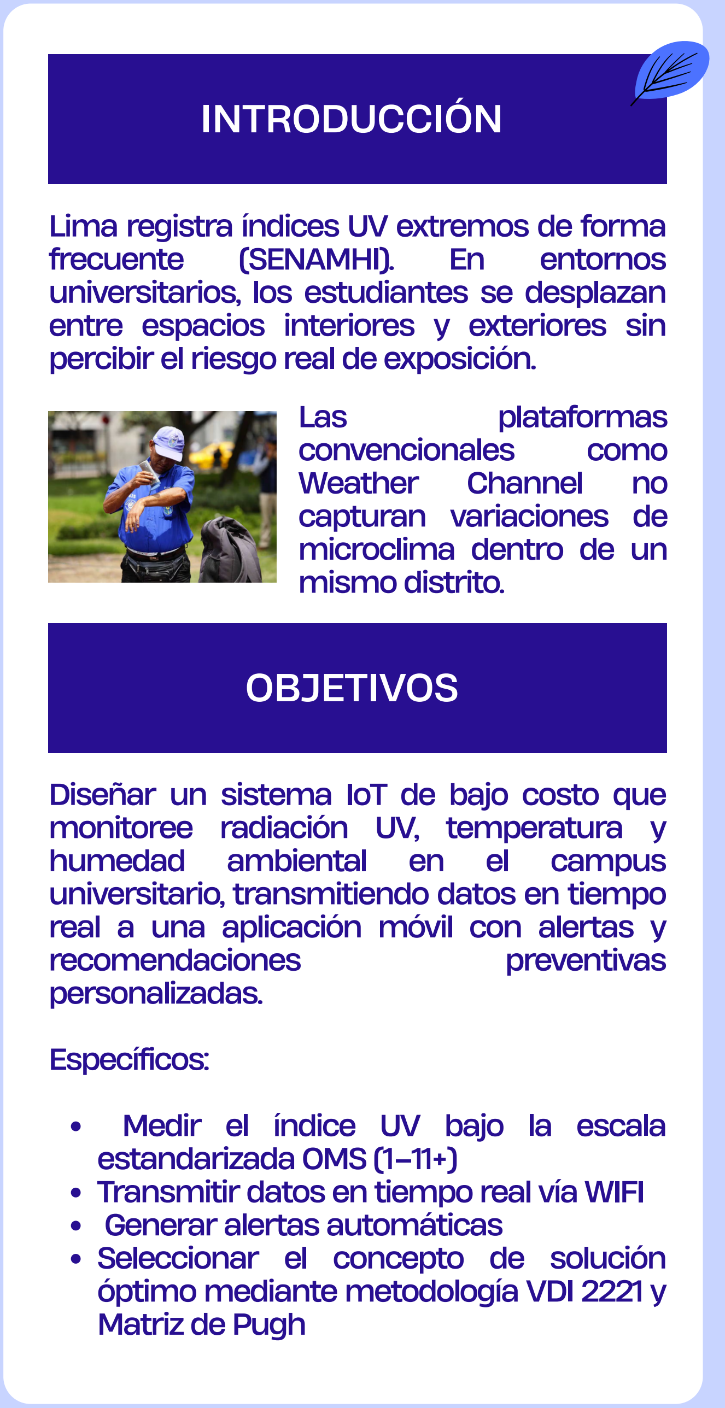
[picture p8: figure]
monitoree radiación UV, temperatura y humedad ambiental en el campus universitario, transmitiendo datos en tiempo; recomendaciones; preventivas; personalizadas.; Específicos:; Medir el índice UV bajo la escala estandarizada OMS (1–11+); Generar alertas automáticas Seleccionar el concepto de solución óptimo mediante metodología VDI 2221 y Matriz de Pugh; Las; plataformas; convencionales; como; Weather; Channel; capturan variaciones de microclima dentro de un mismo distrito.; INTRODUCCIÓN; frecuente; (SENAMHI).; entornos; universitarios, los estudiantes se desplazan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

Diseñar un sistema IoT de bajo costo que

real a una aplicación móvil con alertas y

Transmitir datos en tiempo real vía WIFI

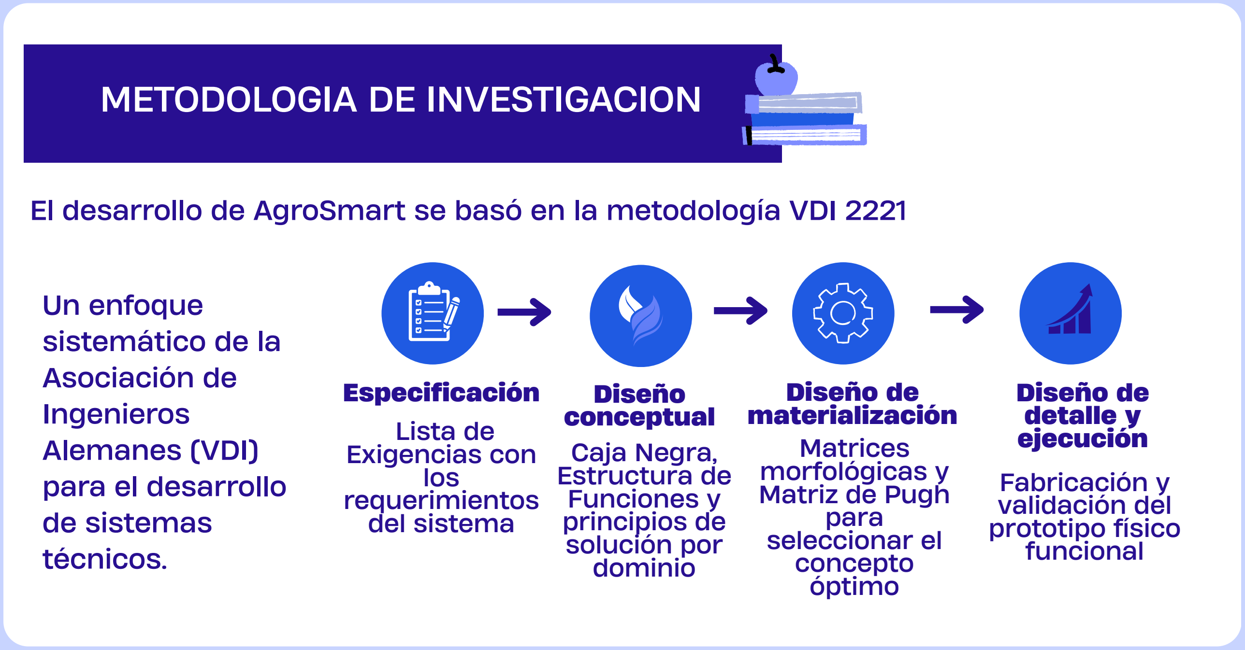
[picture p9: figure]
METODOLOGIA DE INVESTIGACION; Especificación; Diseño; conceptual; Diseño de materialización; Diseño de detalle y; Lista de; ejecución; Exigencias con los requerimientos del sistema; Caja Negra, Estructura de Funciones y principios de solución por dominio; Matrices morfológicas y Matriz de Pugh para seleccionar el concepto óptimo; Fabricación y validación del prototipo físico funcional; Un enfoque sistemático de la Asociación de Ingenieros Alemanes (VDI) para el desarrollo de sistemas técnicos.

Lima registra índices UV extremos de forma

entre espacios interiores y exteriores sin

1.SunFriend Corp. SunFriend Personal UV Monitor [dispositivo portátil en Internet]. Florida: SunFriend Corp.; 2014.
2.Habqi Inc. QSun - Wearable UV Tracker [Internet]. Toronto: Kickstarter; 2017
3.Si R, Guo Y, inventores; Henan Climate Center, Henan Climate Transfer Monitoring and Evaluation Center, solicitantes. Monitoring and Early Warning Device for Climate Comfort of Urban Green Space Water Bodies [Internet]. China: Oficina Nacional de Propiedad Intelectual de China; Patente CN223827091U. 2026 ene 23.
4.Matthys BM, inventor; Eclipse RX LLC, solicitante. Light exposure tracking system, device, and methods [Sistema, dispositivo y métodos para el seguimiento de la exposición a la luz] [Internet]. Estados Unidos: Oficina de Patentes y Marcas de EE. UU.; Patente US 11579015B2. 2023 feb 14 5.Bakare MS, Abubaker K. IoT-based indoor environmental monitoring system using multi-parameter sensing and ESP32-WROOM integration. Discov Electron [Internet]. 2026 ene 22
6.Salamone F, Masullo M, Sibilio S. Wearable Devices for Environmental Monitoring in the Built Environment: A Systematic Review. Sensors [Internet]. 2021 jul 10 7.Gonzales Saenz W. Sistema de sensores inalámbricos para el monitoreo del índice de radiación solar ultravioleta de la ciudad de Huancavelica [tesis en Internet]. Huancayo (Perú): Universidad Nacional del Centro del Perú; 2022. 8.Huallpa Huayhua JE, Ayerbe Huarcaya CI. Sistema basado en IOT para monitoreo de parámetros ambientales en crianza de pollos en el IESTP Jorge Basadre Grohman, 2024 [tesis en Internet]. Puerto Maldonado (Madre de Dios, Perú): Universidad Nacional Amazónica de Madre de Dios (UNAMAD); 2024

### REFERENCIAS

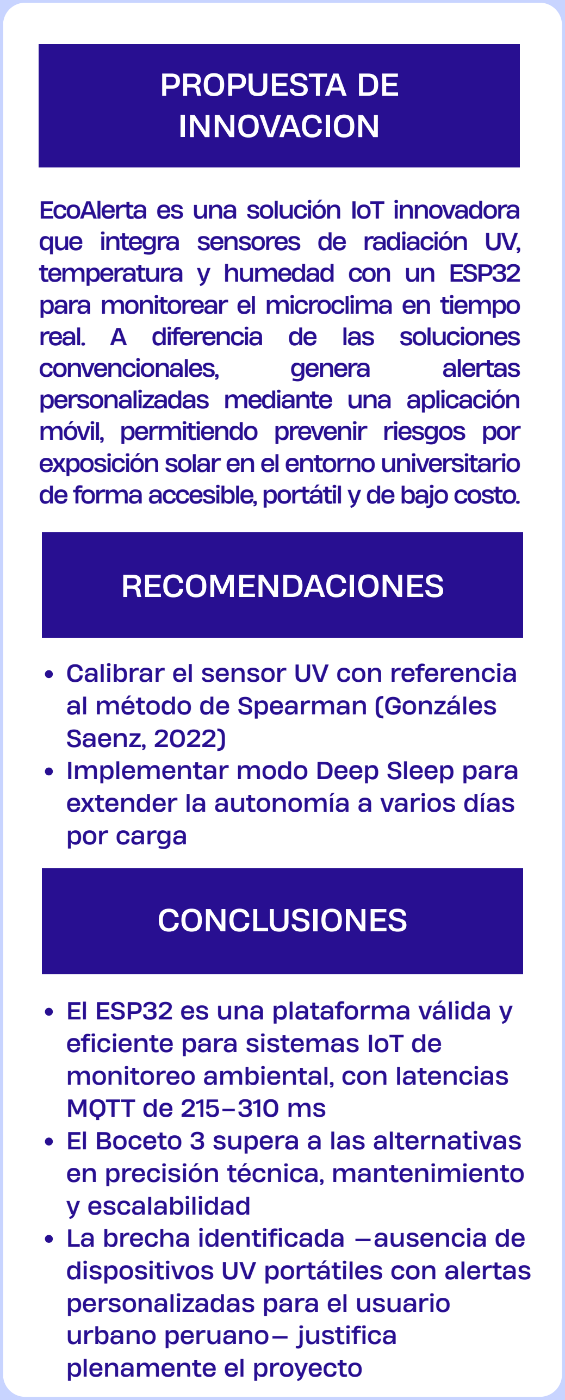
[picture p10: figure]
Calibrar el sensor UV con referencia al método de Spearman (Gonzáles Saenz, 2022) Implementar modo Deep Sleep para extender la autonomía a varios días por carga; RECOMENDACIONES; CONCLUSIONES; El ESP32 es una plataforma válida y eficiente para sistemas IoT de monitoreo ambiental, con latencias MQTT de 215–310 ms El Boceto 3 supera a las alternativas en precisión técnica, mantenimiento y escalabilidad La brecha identificada —ausencia de dispositivos UV portátiles con alertas personalizadas para el usuario urbano peruano— justifica plenamente el proyecto; PROPUESTA DE INNOVACION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

EcoAlerta es una solución IoT innovadora

exposición solar en el entorno universitario de forma accesible, portátil y de bajo costo.

El desarrollo de AgroSmart se basó en la metodología VDI 2221

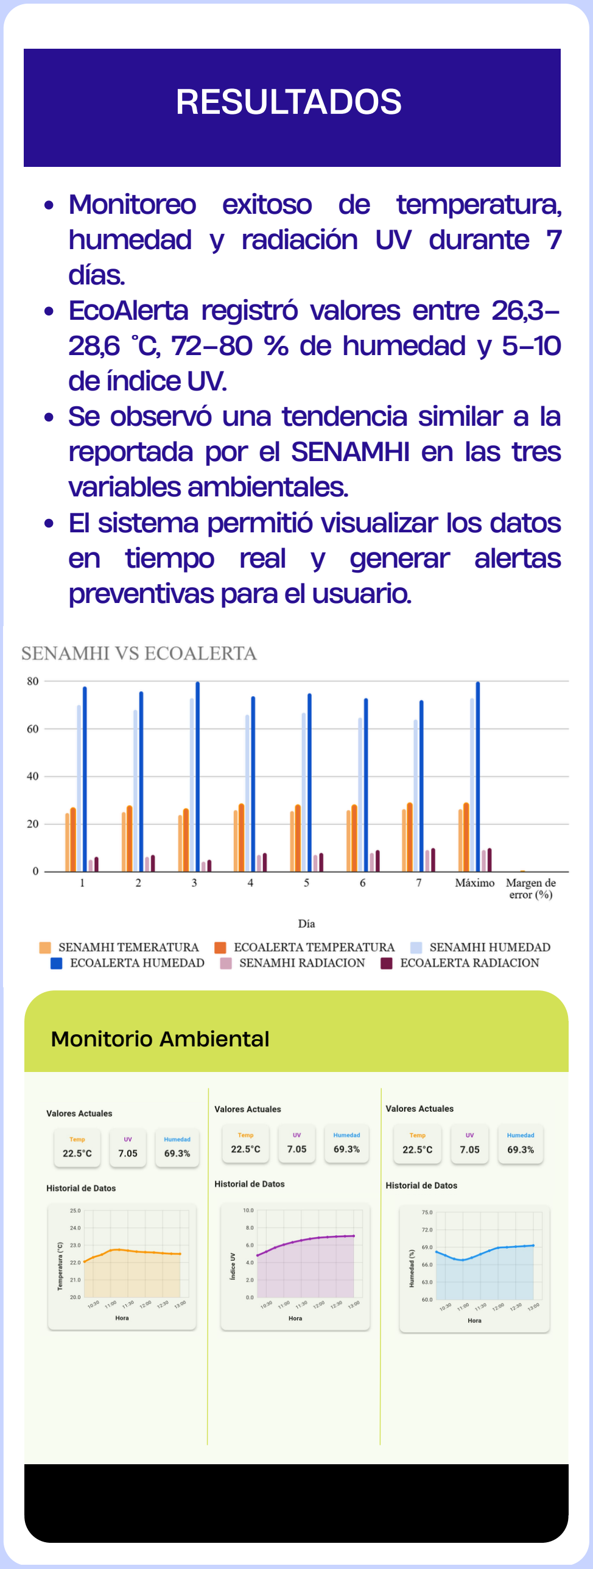
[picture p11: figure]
Mettez ici en valeur une donnée de votre étude.; Figure 2 — Cet espace peut être utilisé pour inclure un graphique ou tableau.; Figura 3. Datos de la temperatura; RESULTADOS; Monitoreo exitoso de temperatura, humedad y radiación UV durante 7 días. EcoAlerta registró valores entre 26,3– 28,6 °C, 72–80 % de humedad y 5–10 de índice UV. Se observó una tendencia similar a la reportada por el SENAMHI en las tres variables ambientales.; en tiempo real y generar alertas preventivas para el usuario.; Monitorio Ambiental

El sistema permitió visualizar los datos

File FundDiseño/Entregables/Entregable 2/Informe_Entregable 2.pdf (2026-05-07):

## UNIVERSIDAD PERUANA CAYETANO HEREDIA

### Facultad de Ciencias e Ingeniería

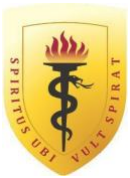
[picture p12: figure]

## INFORME TÉCNICO DEL PROYECTO

### ENTREGABLE 2°

## CURSO

## Fundamentos de Diseño

### Grupo: 4

### Integrantes:

### Jimenez Ayala, Cielo Saori

### Rivera Garayar, Matías Gabriel

### Santos Almonte, Jesilin Lisbet

### Palacios Ochoa, Jose Elias Espinoza Mayta, Adriana Anghely

### Profesores a cargo:

- Da Silva, Jose Luis
- Flores Robles, Domingo Vladimir
- Mugaburu Celi, Marco Antonio
- Venancio Huerta, Julissa Elvira

Lima - Perú
2026

Índice

1. Introducción
2. Problemática
3. Estado de la tecnología
3.1. Tecnología existente en el ámbito comercial
3.2. Tecnología existente en el ámbito de patentes
3.3. Factores comunes en el estado del arte 3.3.1.Artículos científicos
3.3.2.Tesis de repositorios
4. Lista de exigencias
5. Estructura de Funciones
5.1. Caja Negra (Black Box) 5.1.1.Entradas
5.1.2.Salidas
5.2. Secuencia de Operaciones 5.2.1.Nivel usuario
5.2.2.Nivel dispositivo
5.3. Estructura de Funciones 5.3.1.Dominio Electrónico
5.3.2.Dominio Mecánico
5.3.3.Dominio de Energía
5.3.4.Dominio de Software
5.4. Estructura de Funciones Integrada
6. Concepto de solución por Dominio
6.1. Matriz morfológica del dominio electrónico 6.1.1.Disposición básica de soluciones del dominio electrónico 6.1.2.Evaluación de conceptos y selección del concepto óptimo
6.2. Matriz morfológica del dominio mecánico 6.2.1.Disposición básica de soluciones del dominio mecánico 6.2.2.Evaluación de conceptos y selección del concepto óptimo
6.3. Matriz morfológica del dominio de energía 6.3.1.Disposición básica de soluciones del dominio de energía 6.3.2.Evaluación de conceptos y selección del concepto óptimo
6.4. Matriz morfológica del dominio de software 6.4.1.Disposición básica de soluciones del dominio de energía 6.4.2.Evaluación de conceptos y selección del concepto óptimo
7. Bocetos de los 3 conceptos de solución
7.1. Boceto del concepto de solución 1
7.2. Boceto del concepto de solución 2
7.3. Boceto del concepto de solución 3
8. Evaluación de Matriz de Pugh
8.1. Selección y explicación de los criterios técnico/económicos
8.2. Justificación de asignación de puntajes
8.2.1.Concepto de solución 1
8.2.2.Concepto de solución 2
8.2.3.Concepto de solución 3
8.3. Concepto de solución óptimo
9. Referencias bibliográficas

1. Introducción
La exposición a condiciones ambientales adversas, como la radiación ultravioleta (UV), la alta humedad y las elevadas temperaturas, representa un riesgo creciente para la salud pública, especialmente en zonas urbanas como Lima. Según el Servicio Nacional de Meteorología e Hidrología del Perú (SENAMHI), los índices de radiación UV en el país alcanzan niveles extremos con frecuencia. La Organización Mundial de la Salud advierte que la exposición excesiva a la radiación UV está directamente asociada a quemaduras solares y un mayor riesgo de cáncer de piel, cuya prevención temprana ha sido señalada como prioritaria en el contexto peruano [Sordo & Gutiérrez, 2013].

El impacto de este problema es tal que ha motivado respuestas normativas concretas, por ejemplo en 2024, el Ministerio de Educación aprobó la Norma Técnica para la adopción de medidas preventivas en instituciones educativas frente a los efectos nocivos por exposición prolongada a radiación solar y otros fenómenos climatológicos, mediante Resolución Ministerial N° 086-2024-MINEDU [2], reconociendo oficialmente que los entornos educativos representan espacios de riesgo que requieren atención activa.

En ese sentido, consideramos que el entorno universitario cobra especial relevancia. Los estudiantes pasan horas en tránsito entre ambientes interiores y exteriores, muchas veces sin dimensionar el riesgo real al que están expuestos, en parte porque culturalmente no estamos acostumbrados a incorporar estas variables en nuestras decisiones cotidianas. Frente a ello, el equipo propone el desarrollo de una herramienta que traduzca datos ambientales en alertas concretas de protección personal, accesible, en tiempo real, y pensada para el contexto universitario peruano.

2. Problemática
La percepción del riesgo ambiental en la vida cotidiana no siempre refleja la realidad. Dentro de entornos como una universidad, la presencia de árboles y espacios sombreados genera una sensación de protección que puede llevar a subestimar los niveles reales de radiación. Esta falsa seguridad desaparece al salir a las calles: en paraderos y trayectos en transporte público, la exposición directa al sol puede ser significativa sin que el usuario lo perciba ni tome medidas preventivas a tiempo.

Si bien existen plataformas de monitoreo climático como SENAMHI o Weather Channel, estas presentan una limitación estructural: sus datos provienen de estaciones fijas o estimaciones satelitales que promedian condiciones sobre áreas geográficas extensas. Dentro de un mismo distrito de Lima, la radiación UV en una avenida de asfalto puede ser muy distinta a la de un parque arbolado a pocas cuadras. Esta variación de microclima no es capturada por los sistemas convencionales, lo que limita su utilidad para la toma de decisiones individuales en tiempo real.

Frente a esta problemática el equipo 4 propone el desarrollo de un dispositivo portátil basado en tecnología IoT que, mediante sensores de radiación UV, temperatura y humedad conectados a un microcontrolador ESP32, registre las condiciones ambientales del entorno inmediato del usuario y las transmita en tiempo real a una aplicación móvil con recomendaciones personalizadas.

3. Estado de la tecnología
En relación con la propuesta, el Equipo 4, presenta a continuación el estado del arte, revisando productos comerciales existentes, patentes registradas e investigaciones académicas, con el fin de identificar avances tecnológicos disponibles, brechas persistentes y la pertinencia de la solución planteada para el contexto peruano.
3.1. Tecnología existente en el ámbito comercial
i. SunFriend Personal UV Monitor
Fabricante: SunFriend Corp.
Sensores (tecnología usada): Utiliza fotodiodos semiconductores de nitruro de galio (GaN). Esta tecnología permite medir específicamente la radiación UVA y UVB de forma directa, sin necesidad de filtros químicos que se degradan con el tiempo.
Conectividad: Ninguna. Es un dispositivo de lectura directa mediante indicadores LED en el propio aparato.
App: No requiere ni es compatible con aplicaciones móviles.
Precio: Originalmente $49.99 USD; actualmente entre $25.00 y $50.00 USD en plataformas de segunda mano como eBay, dado que ya no se fabrica masivamente.

Limitaciones:
- Su funcionalidad está limitada al movimiento y posición del dispositivo, lo cual puede provocar imprecisiones en la lectura.
- Requiere que el usuario ingrese correctamente su tipo de piel (Escala de Fitzpatrick) de forma manual; una configuración incorrecta compromete la seguridad de las alertas de exposición.
- Al carecer de conectividad, no almacena historial de exposición semanal o mensual; los datos se pierden al reiniciar el dispositivo.

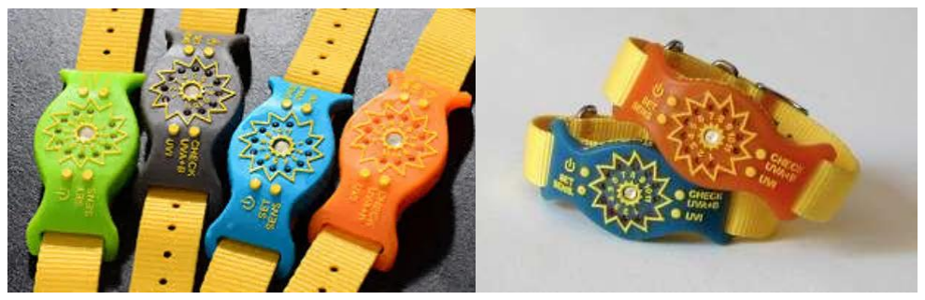
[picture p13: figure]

SunFriend Personal UV Monitor (https://www.amazon.com/-/es/Monitor-personal-Sunfriend-005-Negro/dp/B00K0JV46K)

ii. QSun - Wearable UV Tracker Fabricante: Habqi Inc Sensores (tecnología usada): Incorpora un sensor de precisión para radiación UVA/UVB basado en tecnología de silicio, junto con sensores MEMS de temperatura y humedad. También, incluye un acelerómetro para detectar si el usuario está en movimiento. Conectividad: Bluetooth Low Energy (BLE). Se sincroniza de manera inalámbrica para transmitir los datos recolectados al smartphone del usuario. App: (disponible para iOS y Android). La aplicación calcula el tiempo seguro de exposición al sol basándose en el tipo de piel, el índice UV local y la vestimenta del usuario. Precio: Aproximadamente $59.00 USD - $80.00 USD Limitaciones:

- Dependencia del Smartphone al usar Bluetooth en lugar de Wi-Fi directo
| (como podría hacer el ESP32), el dispositivo pierde gran parte de su utilidad si el teléfono no está a corta distancia del usuario.
- Autonomía de Batería debido al monitoreo constante y la conexión
| Bluetooth, requiere recargas frecuentes (cada 1-2 días), lo que puede ser una molestia para el usuario cotidiano.

- Precisión por Posicionamiento al igual que otros wearables, si el sensor queda cubierto por la ropa o en una posición sombreada respecto al cuerpo, la lectura del índice UV es errónea, enviando recomendaciones de salud falsas.
- Costo de Reposición al ser un dispositivo compacto y cerrado, no permite reparaciones por parte del usuario; si un sensor falla, el dispositivo queda inoperativo.

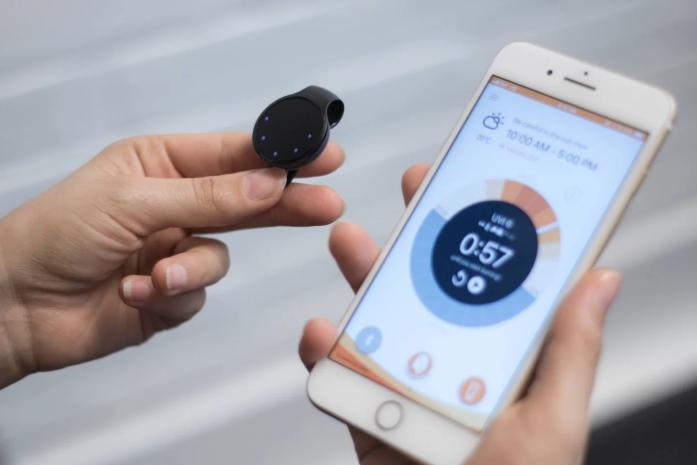
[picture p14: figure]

QSun - Wearable UV Tracker (https://www.kickstarter.com/projects/comfable/qsun)

Tabla 1. Comparación de tecnologías comerciales de monitoreo UV

Producto | Fabricante / Fuente | Tecnología de sensores | Conectividad / App | Limitaciones principales
SunFriend Personal UV Monitor | SunFriend Corp. | Fotodiodos GaN (UVA/UVB directo) | Sin conectividad. Solo LEDs en el dispositivo. Sin app. | Sin historial de datos; requiere configuración manual de tipo de piel (Fitzpatrick); imprecisión por posición.
QSun | -
Wearable UV
Tracker

Habqi Inc
sensores | de
precisión | para
UVA/UVB
(silicio) | y
sensores MEMS
para
temperatura y
humedad.
Incluye
acelerómetro.

Bluetooth Low
Energy (BLE).
Se sincroniza de
manera
inalámbrica para
transmitir los
datos
recolectados al
smartphone del
usuario.
Dependencia | total | del
smartphone; autonomía de
batería reducida (carga cada 1-2 días); posibles lecturas falsas si el sensor se obstruye con la ropa.
3.2. Tecnología existente en el ámbito de patentes
i. UV light monitoring system for a UV decontamination apparatus # PONER 3.2.1
Código: US12409241B2

Año: 2025
Descripción técnica: Describe un sistema diseñado para monitorear luz ultravioleta (UV) en entornos de desinfección. Su función principal es estimar con precisión la irradiancia UV que recibe una superficie específica, incluso cuando esta se encuentra en ángulos arbitrarios respecto a la fuente de emisión UV. Para lograrlo, el dispositivo utiliza un sensor UV junto con dos celdas solares colocadas en diferentes caras del monitor, lo que permite determinar la orientación del sensor y calcular la dosis de radiación real que llega al objetivo.

Similitudes con la propuesta:
- Ambos sistemas comparten el principio de medir radiación UV de manera remota para evaluar la exposición sobre una superficie o área de interés.
- Coinciden en la necesidad de procesar los datos capturados para apoyar la toma de decisiones informadas.

Diferencias:
- Esta patente es una solución técnica altamente especializada para entornos controlados de desinfección, donde la orientación del monitor es crítica para asegurar que se alcance la dosis UV mínima necesaria. El proyecto del equipo, en cambio, está orientado al usuario en movimiento en entornos urbanos abiertos. Espacenet – search results (https://worldwide.espacenet.com/patent/search/family/073196745/publication/US12409241B2?q=pn%3DUS12409241B2)

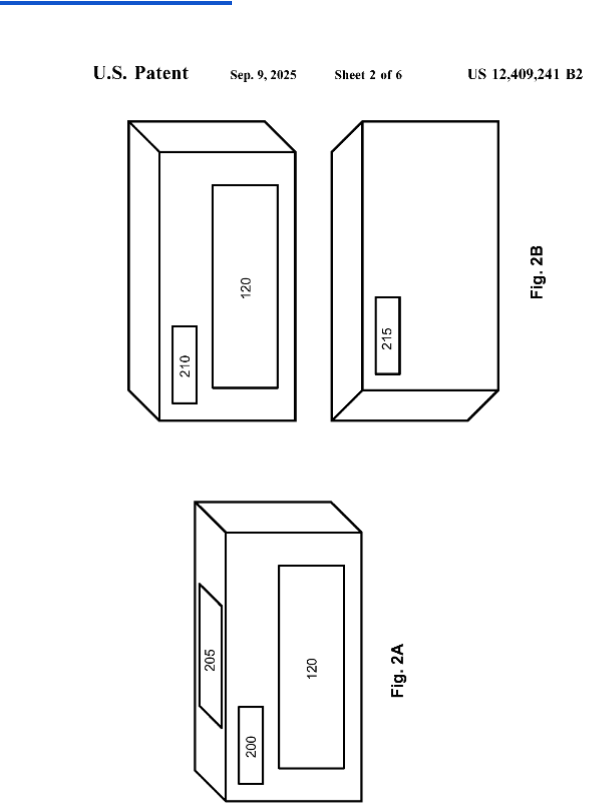
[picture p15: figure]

Monitoring and Early Warning Device for Climate Comfort of Urban Green Space Water Bodies
Código: CN223827091U
Año: 2024
Descripción técnica: La patente presenta un dispositivo de monitoreo y alerta temprana para evaluar condiciones de confort climático en espacios urbanos y cuerpos de agua. El sistema integra sensores de intensidad lumínica, temperatura, humedad, velocidad del viento y precipitación, permitiendo recopilar información ambiental en tiempo real mediante componentes electrónicos conectados a un sistema de adquisición de datos.

Asimismo, incorpora módulos de comunicación y monitoreo continuo orientados a la prevención y gestión ambiental en entornos urbanos. El sistema también incluye mecanismos de protección eléctrica y estructuras adaptables para facilitar el mantenimiento y la operación del dispositivo en exteriores.

Similitudes con la propuesta:

- Ambos sistemas emplean sensores ambientales para monitorear variables climáticas.
- Integran sensores de intensidad lumínica/radiación, temperatura y humedad.
- Utilizan sistemas electrónicos de adquisición y transmisión de datos.
- Están orientados al monitoreo ambiental en espacios urbanos.
- Buscan mejorar la prevención y gestión de riesgos ambientales mediante monitoreo en tiempo real.

Diferencias:
- La patente incorpora sensores adicionales como velocidad del viento, precipitación y monitoreo de cuerpos de agua.
- EcoAlerta se enfoca específicamente en radiación UV y recomendaciones preventivas para estudiantes universitarios.
- El proyecto EcoAlerta utiliza una arquitectura IoT compacta basada en ESP32 y aplicación móvil para alertas personalizadas.

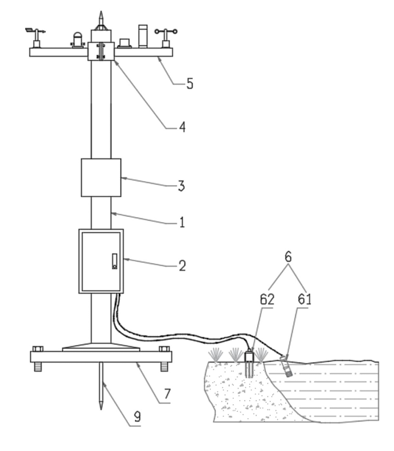
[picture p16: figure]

Espacenet – search results (https://worldwide.espacenet.com/patent/search/family/095158102/publication/DE202025101045U1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)

ii. | Sistema, dispositivo y métodos para el seguimiento de la exposición a la luz Código: DE202025101045U1 Año: 2025 Descripción técnica: Describe una infraestructura de hardware y software diseñada para el control automático de existencias en tiempo real. Utiliza una red de sensores inteligentes distribuidos en puntos estratégicos que recolectan datos mediante tecnología IoT. Esta información es enviada a una plataforma centralizada que integra una capa de inteligencia artificial para procesar los flujos de datos, identificar patrones de consumo y automatizar la toma de decisiones (como alertas de reposición). La arquitectura está optimizada para la baja latencia y la escalabilidad en entornos con múltiples puntos de monitoreo.
| Similitudes con la propuesta:
- Comparte la arquitectura de nodos IoT distribuidos con transmisión de
| datos en tiempo real a una plataforma centralizada.
- El uso de inteligencia artificial para interpretar datos y generar acciones
| es un enfoque transferible al sistema de recomendaciones personalizadas del proyecto.
| Diferencias:

- Su dominio es logístico (gestión de inventarios) y no ambiental. No incluye sensores de radiación UV, temperatura ni humedad, que son el núcleo del sistema propuesto.

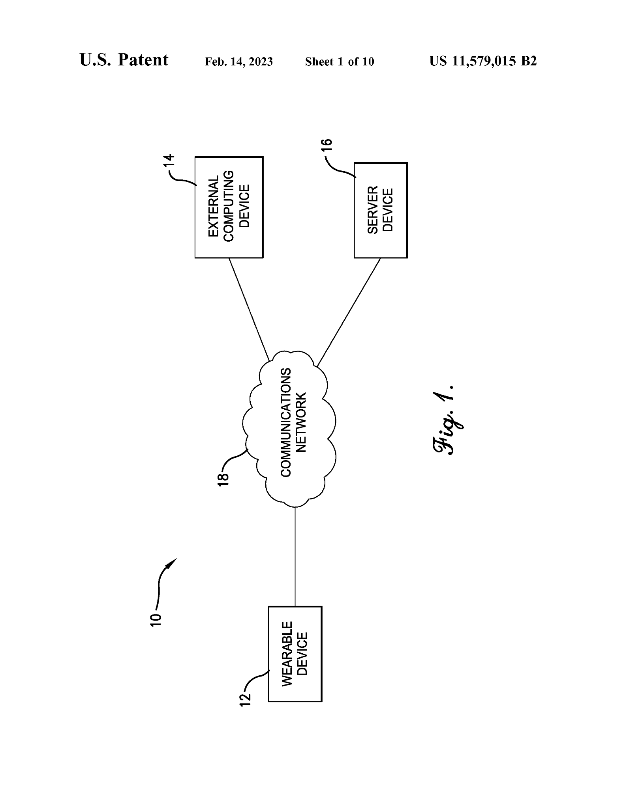
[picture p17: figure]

Espacenet – search results (https://worldwide.espacenet.com/patent/search/family/065362927/publication/US11579015B2?q=pn%3DUS11579015B2)

Tabla 2. Comparación de patentes relacionadas con monitoreo UV e IoT
Patente | Código / Año | Descripción técnica | Similitudes | Diferencias
UV light monitoring system for a UV decontaminatio n apparatus | US12409241 B2 / 2025
| | | Ambos sistemas emplean sensores ambientales para monitorear variables climáticas (radiación, temperatura, humedad). Están orientados al monitoreo ambiental en espacios urbanos y buscan mejorar | La patente incorpora sensores adicionales como velocidad del viento y precipitación. EcoAlerta se enfoca específicamente en radiación UV con recomendaciones preventivas para estudiantes universitarios mediante arquitectura IoT compacta basada en ESP32.

Monitorea
irradiancia UV en
entornos de
desinfección. Usa
sensor UV + dos
celdas solares en
distintas caras para
determinar
orientación y
calcular dosis real.

Ambos miden
radiación UV de
forma remota
para evaluar
exposición;
comparten la
necesidad de
procesar datos
para decisiones
informadas.

Solución altamente
especializada para
entornos controlados
de desinfección; la
orientación es crítica
para validar dosis
mínima letal.

Monitoring and
Early Warning
Device for
Climate Comfort
of Urban Green
Space Water
Bodies

CN223827091
U / 2024

Dispositivo de
monitoreo y alerta
temprana para
evaluar condiciones
de confort climático
en espacios
urbanos. Integra
sensores de
intensidad lumínica,
temperatura,
humedad, velocidad
del viento y
precipitación con

transmisión en
tiempo real.

la prevención de
riesgos
ambientales en
tiempo real.

Sistema,
dispositivo y
métodos para el
seguimiento de
la exposición a
la luz

US11579015
B2 / 2023

Dispositivo portátil
con múltiples
sensores de
exposición
lumínica,
conectividad
inalámbrica y
sistema
controlador para
almacenar y
procesar datos.

Objetivo directo
de monitorear
exposición UV
del usuario; uso
de conectividad
inalámbrica para
transmitir datos.

No genera
recomendaciones
personalizadas al
usuario final en
tiempo real; orientado
a seguimiento clínico
y no a entornos
urbanos dinámicos.
3.3. Factores comunes en el estado de arte 3.3.1.Artículos científicos
i. IoT-based indoor environmental monitoring system using multi-parameter sensing and ESP32-WROOM integration
Autores: Mutiu Shola Bakare y Kazibwe Abubaker
Año: 2026
Revista: Discover Electronics

Hallazgos principales:
- Se desarrolló un sistema IoT basado en ESP32 capaz de medir múltiples variables ambientales como temperatura, humedad, iluminación y calidad del aire de forma simultánea.
- El sistema emplea el protocolo MQTT para transmitir datos en tiempo real a la nube, logrando baja latencia (aprox. 215–310 ms).
- Se obtuvo alta precisión en las mediciones, con errores menores al 2% y coeficientes de correlación superiores a 0.98.
- Se implementó una arquitectura escalable con procesamiento tanto en la nube como en el propio dispositivo (edge computing).
- El sistema demostró ser económico, energéticamente eficiente y adecuado para monitoreo continuo en entornos interiores.

Relevancia para la propuesta:
Este artículo valida directamente el uso del ESP32 como núcleo de sistemas IoT ambientales, coincidiendo con la arquitectura propuesta por el equipo. Además, demuestra la viabilidad de integrar múltiples sensores y transmitir datos en tiempo real hacia plataformas digitales. Refuerza la importancia de convertir datos ambientales en información útil para el usuario, alineándose con el objetivo del proyecto de generar recomendaciones personalizadas. Evidencia asimismo que este tipo de sistemas pueden ser precisos, de bajo costo y escalables, respaldando la factibilidad técnica del prototipo.

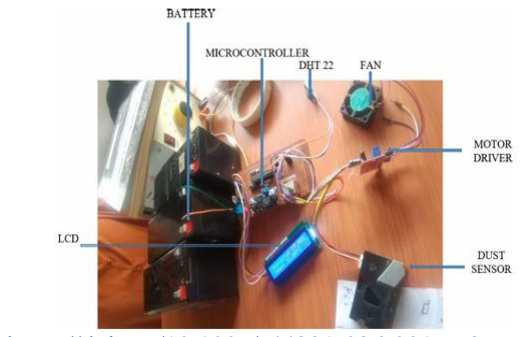
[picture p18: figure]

https://doi.org/10.1007/s44291-026-00157-3

Wearable Devices for Environmental Monitoring in the Built Environment: A Systematic Review

Autores: Salamone, F., Masullo, M., & Sibilio, S.

Año: 2025

Revista: Sensors (MDPI)

Hallazgo principales:

- Integración de Sensores Ambientales: La revisión sistemática identificó que los dispositivos IoT y wearables modernos integran sensores capaces de medir variables ambientales como intensidad lumínica, temperatura, humedad y calidad del aire, permitiendo monitoreo continuo y adquisición de datos en tiempo real.
- Monitoreo Inteligente en Tiempo Real:Los estudios analizados demostraron que la combinación de microcontroladores, sensores y comunicación inalámbrica mejora significativamente la capacidad de supervisar condiciones ambientales y generar alertas preventivas para el usuario.
- Optimización de Dispositivos Portátiles:El artículo evidenció que los sistemas compactos basados en tecnologías IoT pueden operar con bajo consumo energético, facilitando su implementación en dispositivos portátiles y aplicaciones urbanas de monitoreo ambiental.
- Aplicación en Salud y Confort Ambiental:La investigación concluyó que el monitoreo ambiental mediante sensores inteligentes contribuye a prevenir riesgos asociados a la exposición ambiental, mejorando el confort y bienestar de las personas en espacios urbanos y académicos.

Relevancia para la propuesta:

Validación del Enfoque IoT:El artículo proporciona sustento científico para la integración de sensores ambientales y sistemas IoT dentro de EcoAlerta, demostrando la viabilidad del monitoreo en tiempo real mediante dispositivos inteligentes.

Fundamento para Sensores Climáticos: La revisión respalda el uso de sensores de temperatura, humedad e intensidad lumínica como herramientas efectivas para evaluar condiciones ambientales relacionadas con exposición solar y confort climático.

Sustento de Comunicación Inalámbrica:Los estudios revisados validan el uso de tecnologías inalámbricas para transmitir información ambiental hacia aplicaciones móviles y plataformas digitales, fortaleciendo la arquitectura de comunicación propuesta en EcoAlerta.

Relación con Salud Preventiva: El artículo justifica el desarrollo de sistemas que transformen datos ambientales en alertas preventivas, reforzando el objetivo de EcoAlerta de proteger a los estudiantes frente a niveles elevados de radiación UV y condiciones climáticas adversas.

Wearable Devices for Environmental Monitoring in the Built Environment: A Systematic Review (https://www.mdpi.com/1424-8220/21/14/4727)

3.3.2.Tesis de repositorios
i. Sistema de sensores inalámbricos para el monitoreo del índice de radiación solar ultravioleta de la ciudad de Huancavelica
Autor: Carlos Gonzáles Saenz
Año: 2022
Institución: Universidad Nacional del Centro del Perú

Resumen:
Presenta un estudio de campo sobre el uso de sensores UV inalámbricos para medir el índice de radiación UV local en la ciudad de Huancavelica. El trabajo busca compensar la carencia de datos puntuales en zonas altoandinas donde la radiación UV alcanza niveles extremos. Se describe un sistema de sensores inalámbricos que toma mediciones repetitivas del índice UV en intervalos de 5 minutos, registrándolas en tiempo real.

Metodología:
Se despliegan múltiples nodos de sensor UV inalámbricos en puntos representativos de la ciudad. Cada nodo graba continuamente el índice UV. El autor evalúa cuantitativamente la exactitud y consistencia de los datos recogidos usando métodos estadísticos: correlación de Spearman para precisión y prueba de Kruskal-Wallis para la repetitividad temporal. Se analizaron los valores promedio y los picos del índice UV diario.

Aporte:
Corrobora que sensores UV portátiles pueden medir con alta precisión el índice solar en el contexto peruano. Aporta evidencia de protocolos de validación para la precisión de sensores UV, útil para la calibración de los sensores ML8511/LTR390 considerados en el prototipo. El enfoque local —nivelación de radiación UV en Huancavelica— dota de relevancia directa al proyecto, demostrando que la variabilidad de microclima es un problema real en el Perú.

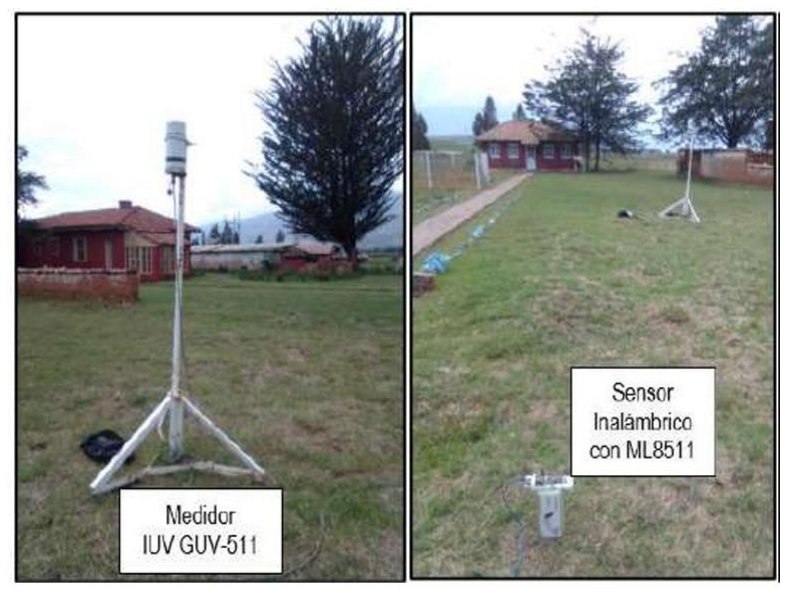
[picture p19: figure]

ii. | Sistema basado en IoT para monitoreo de parámetros ambientales en crianza de pollos en el IESTP Jorge Basadre Grohmann Autor: Huallpa Huayhua Año: 2024 Institución: Instituto de Educación Superior Tecnológico Público Jorge Basadre Grohmann
| Resumen: Propone el diseño e implementación de un sistema IoT para el monitoreo continuo de parámetros ambientales —temperatura, humedad y calidad del aire— en un ambiente de crianza avícola. El sistema integra sensores conectados a un microcontrolador ESP32, transmitiendo datos en tiempo real a una plataforma de visualización, con el objetivo de mantener condiciones óptimas para el bienestar animal y reducir la mortalidad por factores ambientales adversos.
| Metodología: Se implementaron nodos de sensores (DHT22 para temperatura y humedad; MQ-135 para gases) conectados a un ESP32. Los datos son transmitidos vía Wi-Fi a un servidor MQTT y visualizados en un dashboard. Se realizaron pruebas de calibración comparando las lecturas de los sensores con instrumentos de referencia certificados, evaluando la precisión y estabilidad del sistema bajo condiciones reales de operación.
| Aporte: Valida la arquitectura técnica propuesta por el equipo: ESP32 + sensores de temperatura/humedad + transmisión MQTT + visualización en tiempo real. Demuestra que este tipo de sistemas son replicables con bajo costo y sin infraestructura compleja, lo que refuerza la viabilidad del prototipo en un contexto universitario peruano. Asimismo, la experiencia con el sensor

DHT (temperatura y humedad) es directamente transferible al presente proyecto, dado que el equipo considera sensores de la misma familia.

Sistema basado en IOT para monitoreo de parámetros ambientales en crianza de pollos en el IESTP Jorge Basadre Grohman, 2024 (https://repositorio.unamad.edu.pe/handle/20.500.14070/1460)

Tabla 3. Factores comunes identificados en el estado del arte

Factor
común

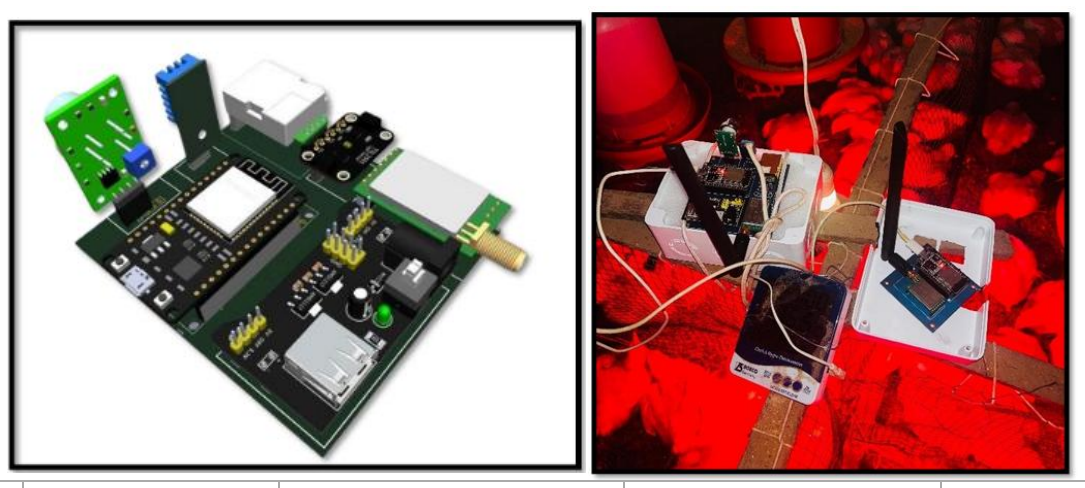
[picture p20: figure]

Artículo
científico
(Bakare &
Abubaker,
2026)

Artículo científico
(Salamone, F.,
Masullo, M., & Sibilio,
S, 2025)

Tesis de
repositorio
(Gonzáles Saenz,
2022)

Tesis de
repositorio
(Huallpa
Huayhua, 2024)

Microcontrol
ador ESP32 /
IoT

ESP32 validado
como núcleo de
sistemas IoT
multiparamétric
os ambientales

Uso de
microcontroladores
con sensores y
comunicación
inalámbrica para
monitoreo ambiental
continuo

Módulos IoT
inalámbricos
(XBee/LoRa) para
red de sensores UV
distribuidos

ESP32 como
unidad central de
adquisición y
transmisión de
datos
ambientales

Transmisión
de datos en
tiempo real

Protocolo
MQTT con
latencia de
215–310 ms
hacia
plataforma en la
nube

Tecnologías
inalámbricas validadas
para transmitir datos
ambientales hacia
apps móviles y
plataformas digitales

Registro continuo
del índice UV cada 5
minutos en nodos
distribuidos

Monitoreo en
tiempo real de
temperatura,
humedad y gases
con alertas
automáticas

Alta
precisión de
sensores

Error < 2% y
coeficiente de
correlación >
0.98 en
múltiples
variables

Sensores de
intensidad lumínica,
temperatura y
humedad con
adquisición continua y
confiable de datos

Validación
estadística con
correlación de
Spearman y prueba
de Kruskal-Wallis

Calibración de
sensores DHT22
y MQ-135 con
referencia a
instrumentos
certificados

Relevancia
para el
proyecto

Valida el uso
del ESP32 y la
arquitectura IoT
propuesta por el
equipo

Respalda el uso de
sensores climáticos y
sistemas IoT portátiles
para prevención de
riesgos en salud
ambiental

Demuestra
viabilidad de
sensores UV
portátiles
ML8511/LTR390 en
contexto peruano

Evidencia que el
sistema de
monitoreo
ambiental IoT en
entornos
cerrados es
replicable con
bajo costo

En síntesis, el estado del arte evidencia que la arquitectura IoT basada en ESP32, la transmisión MQTT y el uso de sensores de bajo costo son tecnologías maduras y validadas tanto en el ámbito internacional como en el contexto peruano. La brecha identificada —ausencia de un dispositivo portátil que integre monitoreo UV, temperatura y humedad con recomendaciones personalizadas para el usuario urbano en tiempo real— justifica y fortalece la propuesta del Equipo 4.

### 4. Lista de exigencias

LISTA DE EXIGENCIAS

PROYECTO: | Aparato con sensor de temperatura, radiación UV y humedad comunicados mediante ESP32 a una app móvil | Fecha: 27/04/26

Revisado:

CLIENTE: | Da Silva, Jose Luis Flores Robles, Domingo Vladimir Mugaburu Celi, Marco Antonio Venancio Huerta, Julissa Elvira | Elaborado : Grupo 4
Fech a (cambi os) | Deseo o Exigenci a | Descripción | Respons able
27/04/ 26 | E | Función Principal: Medir y comunicar niveles de radiación UV, temperatura y humedad en tiempo real para alertar sobre riesgos a la salud | Matías R. y Saori J.

27/04/ 26 | E | Energía: Energía de entrada: - El sistema recibe energía radiante (espectro UV) y energía térmica del ambiente para ser procesadas por los sensores. - Alimentación eléctrica mediante batería para garantizar autonomía en exteriores. Gestión y salida: - La operación del dispositivo debe tener un bajo consumo energético para maximizar la autonomía de la batería. | Jesilin S.
27/04/ 26 | E | Materia: El sistema interactúa con el aire circundante y la humedad (vapor de agua) presente en el ambiente para su medición. | Adriana E. y Jose P.
27/04/ 26 | E | Señales (dispositivo físico): Deberá contar con las siguientes señales de entrada y salida: Señales de entrada: - Encendido/apagado - Señal del sensor de radiación UV, temperatura y humedad Señales de salida: - Valor numérico del índice UV bajo la escala estandarizada de la OMS | Matías R. y Saori J.
27/04/ 26 | E | Señales (aplicación móvil): Deberá contar con las siguientes señales de entrada y salida: Señales de entrada: - Valor numérico del índice UV bajo la escala estandarizada de la OMS - Medida de temperatura en °C - Medida de humedad en el aire en valor porcentual (%) Señales de salida: - Visualización del Índice UV en tiempo real bajo la escala 1–11+. - Notificaciones de alerta ante niveles de riesgo IUV ≥ 3. - Recomendaciones de salud personalizadas y advertencias sobre daños por exposición prolongada. - Alerta visual/auditiva específica durante el rango horario crítico (10:00–16:00). | Matías R. y Saori J.
27/04/ 26 | E | Hardware: Se usará el hardware necesario para obtener la información correspondiente a las condiciones climáticas. Se utilizará un controlador compatible con el resto de dispositivos que permita hacer uso conjunto de los mismos. | Adriana E., Jesilin S. y Jose P.

### 5. Estructura de Funciones 5.1. Caja Negra (Black Box)

La caja negra del sistema EcoAlerta representa una abstracción funcional en la que se identifican las magnitudes de entrada y salida sin detallar el funcionamiento interno. Estas magnitudes se clasifican en materia, energía e información (señales), de acuerdo con la metodología VDI 2221.

27/04/ 26 | E | Software (dispositivo electrónico): Se utilizará un software embebido en el microcontrolador que permita la lectura, procesamiento básico y envío de los datos de temperatura, humedad y radiación. Este deberá garantizar una comunicación estable y eficiente con la plataforma digital. | Matías R. y Saori J.
27/04/ 26 | E | Software (aplicación móvil): Se desarrollará una aplicación encargada de recibir, procesar y visualizar los datos en tiempo real, generando alertas y recomendaciones claras para el usuario. Asimismo, deberá contar con una interfaz intuitiva y un uso eficiente de recursos | Matías R. y Saori J.

27/04/
26
E | Seguridad: Para la operación del sistema, el dispositivo deberá garantizar un funcionamiento seguro tanto a nivel físico como digital. Sus componentes estarán protegidos frente a condiciones ambientales (humedad, calor y exposición solar), evitando fallos o riesgos. Asimismo, la instalación será estable y no representará peligro para los usuarios.
| En cuanto al manejo de la información, el sistema deberá asegurar la transmisión confiable de datos entre el dispositivo y la aplicación móvil, evitando pérdidas o alteraciones.
| El diseño del sistema se basará en la guía de la World Health Organization Global Solar UV Index: A Practical Guide, que establece criterios para comunicar de manera segura y comprensible los niveles de radiación UV. Asimismo, se considerará el Decreto publicado en El Peruano (NL/2266130-1), el cual promueve medidas de prevención frente a la exposición a radiación solar, asegurando que la información brindada contribuya a la protección de la salud.

Adriana
E.,
Jesilin S.
y Jose P.

27/04/
26
E | Ergonomía: El dispositivo estará ubicado en una superficie plana dentro de la universidad, garantizando estabilidad y seguridad. Tendrá un diseño compacto, sin bordes peligrosos y ubicado en un espacio visible pero no obstructivo. La información se visualizará en una aplicación móvil con indicadores claros y fáciles de interpretar.
| El diseño se basará en la guía de la World Health Organization sobre índice UV y en el Decreto publicado en El Peruano (NL/2266130-1), promoviendo la comunicación clara del riesgo y la prevención en salud.

Adriana
E.,
Jesilin S.
y Jose P.

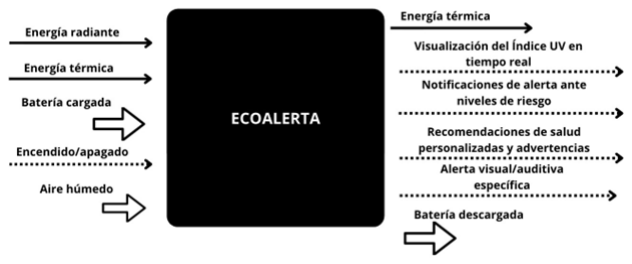
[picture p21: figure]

5.1.1.Entradas
- Energía radiante: Radiación ultravioleta proveniente del sol, captada directamente por el sensor UV como magnitud de entrada principal del sistema.
- Energía térmica: Calor ambiental captado por el sensor de temperatura para su medición y procesamiento.
- Batería cargada: Energía eléctrica almacenada que alimenta el funcionamiento del microcontrolador ESP32 y todos los sensores del dispositivo.
- Señal de encendido/apagado: Señal discreta generada por el usuario mediante el interruptor físico del dispositivo, que activa o detiene el sistema.
- Aire húmedo: Materia ambiental (vapor de agua en el aire) que interactúa con el sensor de humedad para su cuantificación.

5.1.2.Salidas
- Visualización del índice UV en tiempo real: Representación gráfica y numérica del índice UV actual bajo la escala 1–11+ de la OMS, actualizada de forma continua en la interfaz de la aplicación.
- Notificaciones de alerta ante niveles de riesgo: Alertas generadas automáticamente cuando el índice UV es igual o superior a 3, clasificadas según el nivel de riesgo (moderado, alto, muy alto o extremo).
- Recomendaciones de salud personalizadas y advertencias: Mensajes informativos generados en función del índice UV, la temperatura y la humedad registradas, orientados a proteger la salud del usuario frente a la exposición solar prolongada.
- Alerta visual/auditiva específica: Notificación diferenciada activada durante el rango horario crítico de mayor radiación (10:00–16:00 horas), con el fin de reforzar la advertencia al usuario en los momentos de mayor riesgo.

### 5.2. Secuencia de Operaciones

La secuencia de operaciones describe el funcionamiento del sistema Ecoalerta de manera organizada y abarca el nivel de usuario y el nivel dispositivo.

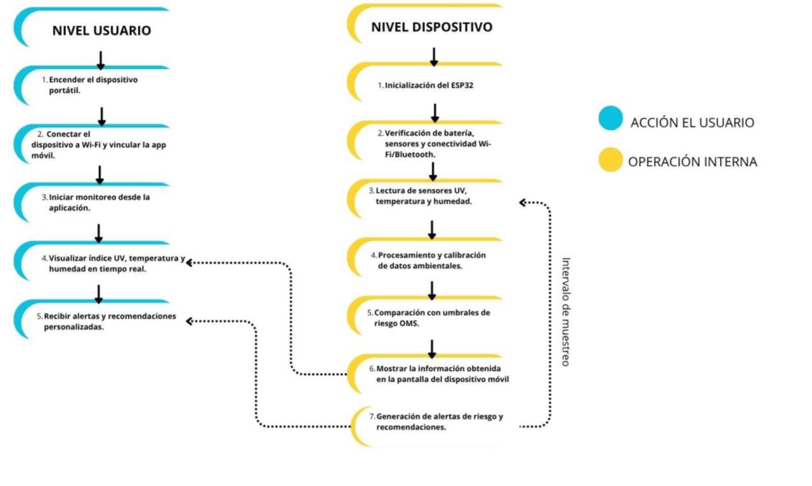
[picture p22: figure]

5.2.1.Nivel usuario
i. El usuario enciende el dispositivo portátil.
ii. | El usuario conecta el dispositivo a la red Wi-Fi y lo vincula con la app
| móvil.
iii. | El usuario inicia el monitoreo desde la aplicación.
iv. | El usuario visualiza el índice UV, la temperatura y la humedad en tiempo
| real a través de la pantalla.
v. El usuario recibe alertas y recomendaciones personalizadas en su
| aplicación.

5.2.2.Nivel dispositivo
i. El dispositivo realiza la inicialización del microcontrolador ESP32.
ii. | El dispositivo ejecuta la verificación del estado de la batería, los sensores y
| la conectividad Wi-Fi/Bluetooth.
iii. | El dispositivo lleva a cabo la lectura de los sensores de UV, temperatura y
| humedad.
iv. | El dispositivo ejecuta el procesamiento y la calibración de los datos
| ambientales recogidos.
v. El dispositivo realiza la comparación de las lecturas con los umbrales de
| riesgo establecidos por la OMS.
vi. | El dispositivo envía y muestra la información procesada en la pantalla del
| dispositivo móvil.
vii. | El dispositivo genera las alertas de riesgo y recomendaciones, y
| posteriormente reinicia el ciclo desde la lectura de sensores (paso iii) según
| el intervalo de muestreo configurado.

### 5.3. Estructura de Funciones

5.3.1.Dominio Electrónico

El dominio electrónico comprende las operaciones de hardware encargadas de captar magnitudes físicas del entorno y transformarlas en señales de datos procesables para el sistema. Sus subfunciones identificadas son:

- Traducir energía radiante a señales eléctricas
- Traducir energía térmica a señales eléctricas
- Traducir humedad en el aire a señales eléctricas
- Direccionar información de lecturas

5.3.2.Dominio de Energía
El dominio eléctrico abarca la gestión, distribución y control del suministro de energía continua o interrumpida necesaria para el funcionamiento de los componentes. Sus subfunciones identificadas son:
- Interrumpir o dejar pasar energía
- Alimentar microcontrolador
- Alimentar sensor UV
- Alimentar sensor de temperatura y humedad

5.3.3.Dominio Mecánico
El dominio mecánico se refiere a la estructura física y espacial diseñada para contener, soportar y proteger los elementos tangibles del dispositivo. Su subfunción identificada es:
- Alojar almacenamiento de energía

5.3.4.Dominio de Software
El dominio de software agrupa los procesos lógicos y algorítmicos responsables de controlar el hardware, interpretar y almacenar la información, y gestionar la comunicación de red. Sus subfunciones identificadas son:
- Controlar intervalo de muestreo
- Calcular UVI a partir de la irradiación medida
- Almacenar UVI
- Almacenar medida de temperatura C°
- Almacenar medida de humedad %
- Definir riesgos, colores, notificaciones, alertas y recomendaciones
- Transmitir datos desde el microcontrolador hacia el dispositivo móvil
- Recibir datos en el dispositivo móvil
- Mostrar los datos en pantalla

- Mostrar notificaciones

### 5.4. Estructura de Funciones Integrada

La estructura de funciones integrada involucra a todos los dominios ya detallados en un esquema que ilustra el flujo de la energía, materia y señales con los que interactúa el sistema desde que el dispositivo recibe la alimentación eléctrica hasta que el usuario visualiza los datos climáticos en su dispositivo móvil.

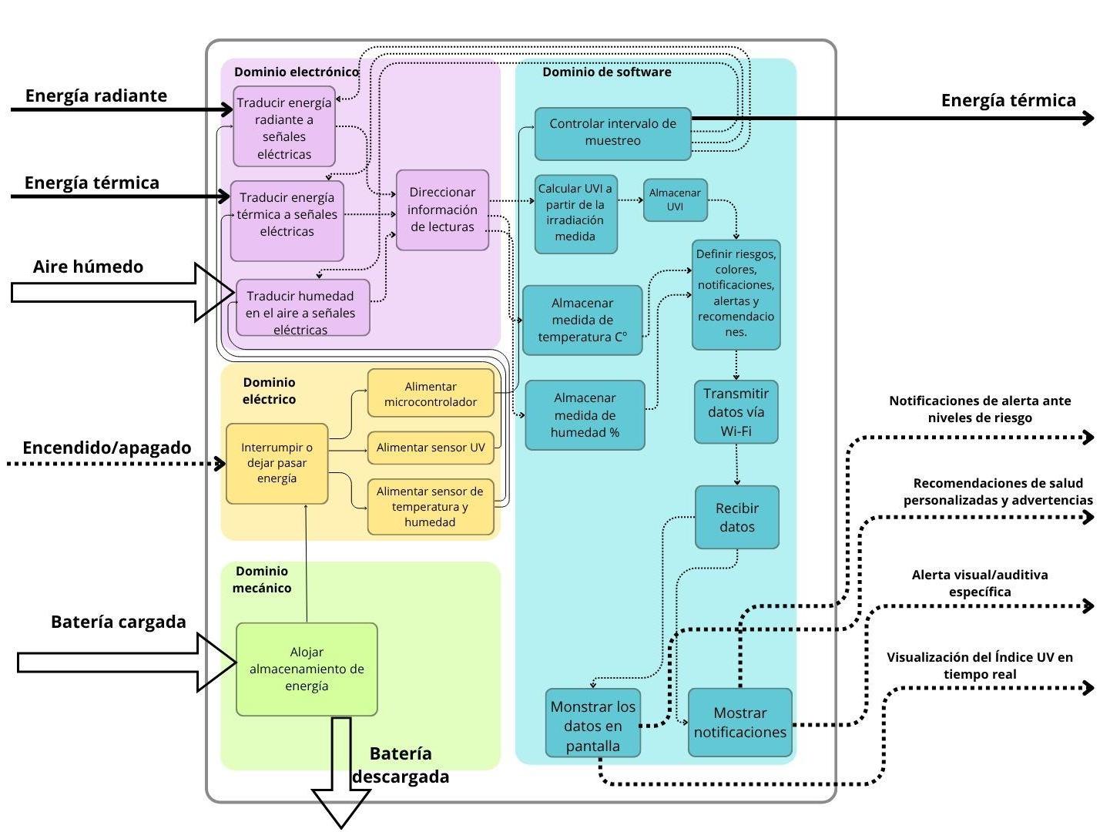
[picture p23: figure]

6. Concepto de solución por dominio
7. Bocetos de los 3 conceptos de solución
8. Evaluación de Matriz de Pugh
9. Bibliografía

## 1. Concepto de solución por Dominio:

6.1 Matriz morfológica del dominio electrónico

a. Disposición básica de soluciones del dominio electrónico
b. Evaluación de conceptos y selección del concepto óptimo

6.1.1 Disposición básica de soluciones del dominio electrónico

SUBTEMA | FUNCION | ALTERNATIV A 1 | ALTERNATIV A 2 | ALTERNATIV A 3
DOMINIO ELECTRÓNIC O | CONTROLAD OR | ESP32 | Arduino + WIFI | Raspberry Pi
DOMINIO ELECTRÓNIC O | Sensar temperatura/hu medad | Sensor resistivo | Sensor capacitivo | Sensor digital integrado
DOMINIO ELECTRÓNIC O | SENSOR RADIACIÓN UV | Fotodiodo UV | Sensor espectral | Sensor analógico UV

a) Función: Controlar y procesar datos

Alternativa 1: ESP32. Microcontrolador con Wi-Fi y Bluetooth integrados, diseñado para aplicaciones IoT. Permite procesar datos de sensores y transmitir información en tiempo real con bajo consumo energético.

Alternativa 2: Arduino + módulo Wi-Fi. Sistema basado en Arduino complementado con un módulo externo de conectividad inalámbrica. Requiere componentes adicionales para comunicación y mayor espacio físico.

Alternativa 3: Raspberry Pi. Computadora de placa reducida con alta capacidad de procesamiento y soporte para sistemas operativos completos. Adecuada para tareas complejas, aunque con mayor consumo energético.

b) Función: Medir temperatura y humedad

Alternativa 1: Sensor resistivo. Sensor que mide humedad mediante variaciones de resistencia eléctrica. Es económico, pero susceptible a corrosión y pérdida de precisión.

Alternativa 2: Sensor capacitivo. Sensor que detecta cambios de humedad mediante variaciones de capacitancia. Ofrece mayor estabilidad y vida útil que los sensores resistivos.

Alternativa 3: Sensor digital integrado. Sensor que integra medición de temperatura y humedad con salida digital calibrada. Facilita la conexión al microcontrolador y reduce errores de medición.

c) Función: Medir radiación UV

Alternativa 1: Fotodiodo UV Dispositivo semiconductor sensible a la radiación ultravioleta. Requiere circuitos adicionales para acondicionamiento y procesamiento de señal.

Alternativa 2: Sensor espectral Sensor avanzado capaz de identificar diferentes rangos del espectro lumínico y UV. Proporciona alta precisión, aunque con mayor costo y complejidad.

Alternativa 3: Sensor analógico UV Sensor compacto que entrega una señal analógica proporcional a la intensidad de radiación UV. Permite integración sencilla y monitoreo continuo.

6.1.2 Evaluación de conceptos y selección del concepto óptimo

a) Selección de Controlador: Se selecciona la Alternativa 1 (ESP32) debido a que integra procesamiento y conectividad inalámbrica en un solo dispositivo, reduciendo tamaño, consumo energético y complejidad del sistema. Se descartan Arduino + Wi-Fi y Raspberry Pi por requerir módulos adicionales o presentar mayor consumo energético para una aplicación portátil IoT.

b) Selección de Medición de Temperatura y Humedad: Se elige la Alternativa 3 (Sensor digital integrado) por su fácil integración, estabilidad y menor necesidad de calibración. Los sensores resistivos y capacitivos se descartan debido a su mayor susceptibilidad a errores y necesidad de acondicionamiento adicional.
c) Selección de Medición de Radiación UV: Se selecciona la Alternativa 3 (Sensor analógico UV) debido a su integración sencilla, bajo costo y capacidad de lectura continua de radiación UV. Los sensores espectrales se descartan por su mayor complejidad y costo de implementación.

6.2 Matriz morfológica del dominio mecánico

6.2.1. Disposición básica de soluciones del dominio mecánico

### 6.2 Matriz morfológica del dominio mecánico

SUBTE MA | SUBTEM A | FUNCION | ALTERNATIV A 1 | ALTERNATIVA 2 | ALTERNATIVA 3
DOMINI O MECÁNI CO | Estructur a | Proteger componen tes | Carcasa cerrada | Carcasa ventilada | Protección parcial
DOMINI O MECÁNI CO | Interacci ón | Exposición al ambiente | Directa | Controlada | Aislada parcialmente
DOMINI O MECÁNI CO | Forma | Configurac ión geométric a | Compacta | Vertical | Modular

DOMINI O MECÁNI CO | Ubicació n | Instalación | Techo | poste | pared
DOMINI O MECÁNI CO | Ventilaci ón | Flujo de aire | Rejillas laterales | Ventilación | Aberturas superiores
a) Función: Proteger componentes

Alternativa 1: Carcasa cerrada : Estructura sellada que protege los componentes electrónicos frente a polvo, humedad y radiación solar. Permite aumentar la durabilidad y seguridad del sistema en exteriores.

Alternativa 2: Carcasa ventilada: Estructura con aberturas de ventilación que favorecen el flujo de aire interno, reduciendo acumulación de calor en los componentes.

Alternativa 3: Protección parcial. Sistema con cobertura limitada que protege únicamente ciertas partes del dispositivo, dejando algunos componentes expuestos al ambiente.

b) Función: Exposición al ambiente

Alternativa 1: Exposición directa. Los sensores permanecen directamente expuestos al entorno para captar condiciones ambientales reales de manera inmediata.

Alternativa 2: Exposición controlada. Los sensores se ubican en compartimientos o cámaras que regulan parcialmente la interacción con el ambiente.

Alternativa 3: Exposición parcialmente aislada. Configuración donde los sensores cuentan con barreras físicas que limitan la exposición directa a factores ambientales.

c) Función: Configuración geométrica

Alternativa 1: Forma compacta. Diseño reducido y compacto que facilita la integración de componentes y mejora la estabilidad estructural.

Alternativa 2: Forma vertical. Configuración alargada en sentido vertical que optimiza el uso del espacio y favorece la disipación térmica.

Alternativa 3: Forma modular. Diseño basado en módulos independientes que permite reemplazo o expansión de componentes de manera sencilla.

d) Función: Instalación del dispositivo

Alternativa 1: Instalación en techo. Ubicación elevada que permite mayor exposición a radiación solar y flujo de aire, reduciendo interferencias del entorno.

Alternativa 2: Instalación en poste. Montaje sobre estructuras verticales que facilitan cobertura ambiental en espacios abiertos.

Alternativa 3: Instalación en pared. Sistema fijado sobre superficies verticales, simplificando el acceso para mantenimiento y operación.

e) Función: Flujo de aire

Alternativa 1: Rejillas laterales. Aberturas laterales que permiten circulación de aire constante para mejorar la medición de temperatura y humedad.

Alternativa 2: Ventilación activa. Sistema con ventiladores o mecanismos forzados que incrementan el flujo de aire dentro de la estructura.

Alternativa 3: Aberturas superiores. Orificios ubicados en la parte superior que facilitan la salida natural del aire caliente.

6.2.2. Evaluación de conceptos y selección del concepto óptimo
a) Selección de Estructura: Se selecciona la Alternativa 1 (Carcasa cerrada) debido a que brinda mayor protección a los componentes electrónicos frente a polvo, humedad y radiación solar. Se descartan estructuras abiertas o parcialmente cerradas por incrementar el riesgo de daño y deterioro.
b) Selección de Interacción con el Entorno: Se elige la Alternativa 1 (Exposición directa) para obtener mediciones más representativas de las condiciones ambientales reales. Las configuraciones controladas o aisladas se descartan porque pueden alterar la precisión de los datos.
c) Selección de Forma Estructural: Se selecciona la Alternativa 1 (Forma compacta) debido a que facilita la integración de componentes, reduce el espacio ocupado y mejora la estabilidad del dispositivo. Las formas más complejas o voluminosas se descartan por su mayor dificultad de diseño e instalación.
d) Selección de Ubicación del Dispositivo: Se elige la Alternativa 1 (Instalación en techo) ya que proporciona mejor exposición a la radiación solar y flujo de aire, evitando interferencias causadas por obstáculos cercanos. Se descartan ubicaciones bajas o interiores por su menor representatividad ambiental.
e) Selección de Ventilación: Se incorpora la Alternativa 1 (Rejillas laterales) porque permite un flujo de aire constante necesario para medir correctamente temperatura y humedad. Los sistemas cerrados o con ventilación limitada se descartan debido a la acumulación de calor y posible afectación en la precisión de las mediciones.

6.3 Matriz morfológica del dominio de energía

6.3.1. Disposición básica de soluciones del dominio mecánico

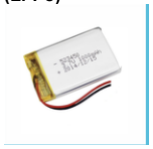
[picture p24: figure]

#QUE SEA LA MISMA VERSIÓN

a) Función: Suministrar energía
Alternativa 1: Batería de Li-ion recargable
Es una tecnología de almacenamiento electroquímico con alta densidad energética. El sistema utilizado sería una celda 18650, estándar en dispositivos portátiles.

Alternativa 2: Batería de Polímero de Litio (Li-Po)

DOMIN IO | SUBTEM A | FUNCION | ALTERNATIVA 1 | ALTERNATIVA 2 | ALTERNATIVA 3
DOMIN IO ENERG ÍA | Alimenta ción | Suministr ar energía | Batería de Li-ion recargable | Batería de Polímero de Litio (Li-Po) | Batería Li-io + Panel Solar Pequeño
DOMIN IO ENERG ÍA | Regulaci ón | Regular potencia | Regulador de Voltaje Lineal (LDO) a 3.3V/5V | Módulo Step-Down (Buck Converter) | Regulador integrado nativo de la placa base
DOMIN IO ENERG ÍA | Gestión | Administr ar consumo | Modo "Deep Sleep" en el ESP32 entre intervalos de lectura | Muestreo continuo sin reposo | Modulo “Light Sleep”

Utiliza un electrolito de polímero sólido, permitiendo diseños más delgados. Se aplicaría mediante una batería plana de 3.7V, similar a las de los smartphones.

Alternativa 3: Batería Li-io + Panel Solar Pequeño
Sistema | híbrido | que | combina | almacenamiento | con
generación fotovoltaica. El componente sería un panel monocristalino de 5V acoplado a la batería.
b) Función: Regular potencia
Alternativa 1: Regulador de Voltaje Lineal (LDO). Mantiene un voltaje de salida estable disipando el exceso de energía en forma de calor. Se usaría un chip AMS1117 de 3.3V.
Alternativa | 2: | Módulo | Step-Down | (Buck | Converter).
Regulador conmutado de alta eficiencia que reduce el voltaje mediante inductores. El sistema sería un módulo HW-613 o MP2307.

Alternativa 3: Regulador integrado nativo. Utiliza los
componentes | ya | soldados | en | la | placa | base | del
microcontrolador para la gestión de voltaje.
c) Función: Administrar consumo
Alternativa 1: Modo "Deep Sleep". Técnica de ahorro extremo donde se apaga el CPU y la mayoría de periféricos del SoC, dejando solo un temporizador activo. Se implementa mediante la función nativa del ESP32.

Alternativa 2: Muestreo continuo sin reposo. El sistema se mantiene en modo activo (Run Mode) constantemente para lecturas en tiempo real sin latencia.

Alternativa 3: Modulo “Light Sleep”. Suspensión parcial donde se mantiene la memoria RAM energizada, permitiendo un despertar más rápido que el Deep Sleep.

6.3.2. Evaluación de conceptos y selección del concepto óptimo
a) Selección de Suministro: Se elige la Alternativa 2 (Batería Li-Po). Debido a que el proyecto busca ser un dispositivo portable para la prevención de salud frente a la radiación UV, el factor de forma delgado y el peso reducido de la Li-Po superan a la celda 18650, permitiendo un diseño más ergonómico.
b) Selección de Regulación: Se selecciona la Alternativa 2 (Módulo Step-Down). Dado que las baterías de litio cargadas superan los 4V, un regulador lineal (LDO) desperdiciaría energía valiosa en calor. El convertidor Buck maximiza la vida útil de la batería al ser mucho más eficiente en la conversión.
c) Selección de Administración: Se elige la Alternativa 1 (Deep Sleep). Al ser un monitoreo ambiental, no es necesario procesar datos cada milisegundo. Programar intervalos de lectura (ej. cada 5 minutos) y entrar en Deep Sleep reduce el consumo de ~70mA a menos de 10µA, garantizando que el dispositivo funcione por días sin recarga.
6.4. Matriz morfológica del dominio de software
6.4.1. Disposición básica de soluciones del dominio de software

DOMIN IO | SUBTEM A | FUNCION | ALTERNATIVA 1 | ALTERNATIVA 2 | ALTERNATIVA 3
DOMIN IO SOTFT WARE | Comunic ación | Transmitir flujo de datos | Protocolo MQTT | Protocolo HTTP POST | Bluetooth Low Energy (BLE)
DOMIN IO SOFT WARE | Lógica | Procesar variables | Cloud Computing | Procesamiento embebido | Mobile Computing
DOMIN IO SOFT WARE | Visualiza ción | Visualizar datos e Interfaz | Interfaz LCD / OLED | Interfaz de App Móvil | Interfaz de Dashboard Web
DOMIN IO SOFT WARE | Notificaci ón | Notificar riesgos al usuario | Servicio SMS | Alarmas In-App | Notificaciones Push

a) Función: Transmitir flujo de datos

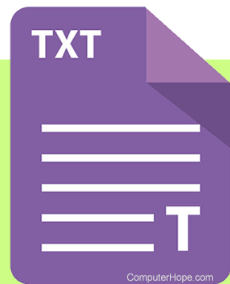
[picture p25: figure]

Alternativa 1: Red Wi-Fi vía protocolo MQTT. Protocolo de mensajería ligero basado en publicación/suscripción, ideal para dispositivos de bajos recursos en redes inestables. El sistema utilizaría un Broker MQTT (como Mosquitto) para recibir las lecturas.

Alternativa 2: Red Wi-Fi vía peticiones HTTP POST. Método estándar de transferencia de datos sobre la web donde el cliente envía información al servidor. Se implementaría mediante una API REST.

Alternativa 3: Bluetooth Low Energy (BLE). Tecnología de comunicación inalámbrica de corto alcance diseñada para reducir drásticamente el consumo energético. El sistema sería una conexión punto a punto con el smartphone.

b) Función: Procesar variables
Alternativa 1: Procesamiento centralizado en la nube. Los datos crudos se envían a un servidor remoto que realiza los cálculos complejos. Se usaría un servicio como Google Cloud o AWS.

Alternativa 2: Procesamiento interno en el microcontrolador. Los algoritmos de conversión (ej. pasar de voltaje a índice UV) se ejecutan localmente. Se implementa directamente en el firmware del ESP32.

Alternativa 3: Procesamiento en la aplicación móvil. El dispositivo solo transmite datos binarios y el teléfono del usuario interpreta la información.

c) Función: Visualizar datos e Interfaz

DOMIN
IO
SOFT
WARE

Comunic
ación

Estructura
r el envío
de datos
Formato CSV | Formato JSON | Formato | Texto
| | Plano (Raw)

Alternativa 1: Pantalla LCD física en el dispositivo. Módulo de hardware acoplado para lectura directa sin necesidad de otros equipos. El componente sería un display OLED I2C.

Alternativa 2: Aplicación móvil. Interfaz gráfica desarrollada para smartphones que permite ver gráficas e históricos. Se usaría un entorno como Blynk o una App nativa.

Alternativa 3: Dashboard Web. Panel de control accesible desde cualquier navegador mediante una dirección IP o dominio.

d) Función: Notificar riesgos al usuario
Alternativa 1: Envío de mensajes de texto (SMS) automatizados. Alertas enviadas a través de la red de telefonía móvil. Requiere un módulo GSM o servicio como Twilio.

Alternativa 2: Alarmas únicamente dentro de la aplicación abierta. Notificaciones visuales que solo aparecen si el usuario tiene la app en primer plano.

6.4.2. Evaluación de conceptos y selección del concepto óptimo

La selección de las tecnologías de software se basa en la escalabilidad, la experiencia de usuario y el consumo de recursos del ESP32.

a) Selección para Transmitir flujo de datos: Se elige la Alternativa 1 (Red Wi-Fi vía protocolo MQTT). A diferencia de HTTP, MQTT mantiene una conexión abierta con un gasto mínimo de datos y energía, lo que permite que el dispositivo envíe actualizaciones de temperatura y UV de manera constante sin agotar la batería rápidamente.
b) Selección para Procesar variables: Se elige la Alternativa 2 (Procesamiento interno en el microcontrolador). Realizar el cálculo del índice UV y la conversión de señales analógicas a digitales directamente en el ESP32 permite que el dispositivo funcione de manera autónoma. Esto evita la dependencia total de una conexión a la nube para obtener resultados inmediatos.
c) Selección para Visualizar datos e Interfaz: Se elige la Alternativa 2 (Aplicación móvil). Dado que el usuario suele estar en movimiento (en la calle o el trabajo), una App permite consultar los niveles de radiación de forma cómoda y remota, además de permitir un almacenamiento histórico de datos que una pantalla física pequeña no podría mostrar con claridad.
d) Selección para Notificar riesgos al usuario: Se elige la Alternativa 3 (Notificaciones Push). Es la opción más efectiva para la prevención de la salud. Al detectar un pico de radiación UV peligroso, el sistema envía una alerta vibratoria y visual al smartphone del usuario, garantizando que este tome medidas (como aplicarse bloqueador o buscar sombra) incluso si no está mirando la aplicación.
e) Selección para Estructurar el envío de datos: Se elige la Alternativa 2 (Mensajes JSON compactos). JSON es el estándar actual por su flexibilidad; permite agrupar temperatura, humedad y UV en un solo mensaje organizado. Esto facilita que, en el futuro, se puedan añadir más sensores al dispositivo sin tener que cambiar toda la estructura del código.

Alternativa 3: Notificaciones Push. Alertas del sistema operativo que informan al usuario incluso con el teléfono bloqueado, utilizando vibración y sonido.

e) Función: Estructurar el envío de datos
Alternativa 1: Envío de datos en formato .csv. Organización simple por comas, útil para bases de datos básicas.

Alternativa 2: Mensajes JSON compactos. Formato de texto ligero que facilita el intercambio de datos estructurados entre el ESP32 y el servidor/app.

Alternativa 3: Envío en texto plano continuo. Flujo de
caracteres | sin | etiquetas | ni | estructuras | complejas,
minimizando el tamaño del paquete.
6.5. Matriz morfológica integrada
SUBTEMA | FUNCION | ALTERNATIVA 1 | ALTERNATIVA 2 | ALTERNATIVA 3
DOMINIO ELECTRÓNICO | CONTROLADO R | ESP32 | Arduino + WIFI | Raspberry Pi

DOMINIO ELECTRÓNICO | Sensar temperatura/hume dad | Sensor resistivo | Sensor capacitivo | Sensor digital integrado
DOMINIO ELECTRÓNICO | SENSOR RADIACIÓN UV | Fotodiodo UV | Sensor espectral | Sensor analógico UV
DOMINIO MECÁNICO | Proteger componentes | Carcasa cerrada | Carcasa ventilada | Protección parcial
DOMINIO MECÁNICO | Exposición al ambiente | Directa | Controlada | Aislada parcialmente
DOMINIO MECÁNICO | Configuración geométrica | Compacta | Vertical | Modular
DOMINIO MECÁNICO | Instalación | Techo | poste | pared

DOMINIO MECÁNICO | Flujo de aire | Rejillas laterales | Ventilación | Aberturas superiores
DOMINIO ENERGÍA | Suministrar energía | Batería de Li-ion recargable | Batería de Polímero de Litio (Li-Po) | Batería Li-io + Panel Solar Pequeño
DOMINIO ENERGÍA | Regular potencia | Regulador de Voltaje Lineal (LDO) a 3.3V/5V | Módulo Step-Down (Buck Converter) | Regulador integrado nativo de la placa base
DOMINIO ENERGÍA | Administrar consumo | Modo "Deep Sleep" en el ESP32 entre intervalos de lectura | Muestreo continuo sin reposo | Modulo “Light Sleep”
DOMINIO SOTFTWARE | Comunicación | Transmitir flujo de datos | Protocolo MQTT | Protocolo HTTP POST
DOMINIO | Lógica | Procesar variables | Cloud Computing | Procesamiento

SOFTWARE | | | | embebido
DOMINIO SOFTWARE | Visualización | Visualizar datos e Interfaz | Interfaz LCD / OLED | Interfaz de App Móvil
DOMINIO SOFTWARE | Notificación | Notificar riesgos al usuario | Servicio SMS | Alarmas In-App
DOMINIO SOFTWARE | Comunicación | Estructurar el envío de datos | Formato CSV | Formato JSON
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

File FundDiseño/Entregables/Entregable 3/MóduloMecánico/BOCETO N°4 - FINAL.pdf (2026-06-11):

BOCETO N°3 | DIBUJADO POR: Jimenez Ayalo Cielo Saori

BOCETO EN CONJUNTO:

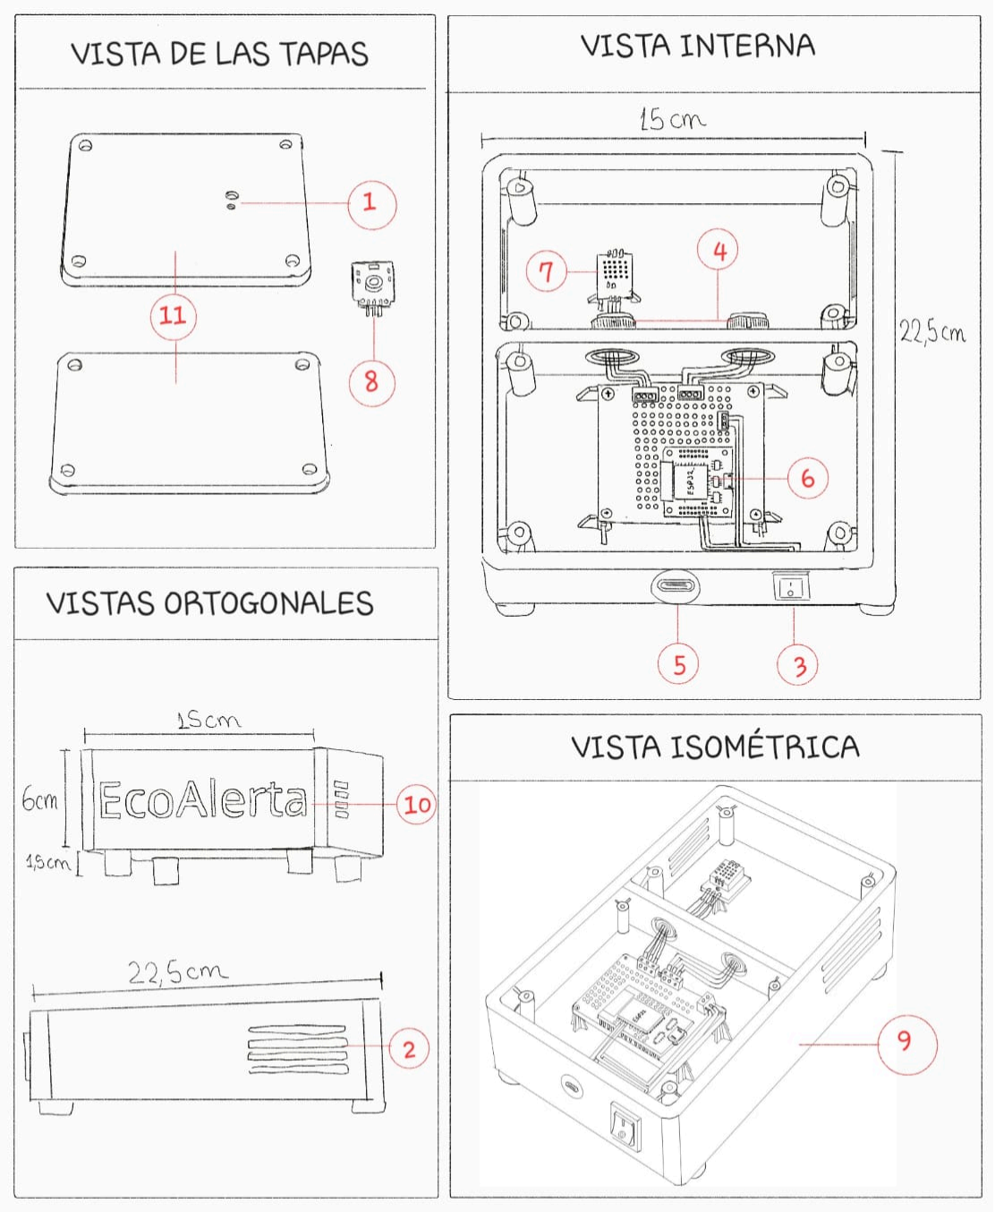
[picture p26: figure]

Descripción del funcionamiento: | LISTA DE DESPIECE:
El dispositivo consiste en una
carcasa rectangular de 15 cm × 22,5 | PIEZA | NOMBRE | MATERIAL

cm fabricada en PLA, pensada para monitoreo ambiental en exteriores. En la parte superior se ubican el sensor UV (UV SENS), expuesto a través de una apertura circular con soporte integrado, y el sensor de temperatura y humedad (DHT22), acompañado de rejillas de
ventilación lineales que permiten el libre flujo de aire. En el compartimiento interior se aloja el microcontrolador ESP32 junto con las conexiones electrónicas. En el panel frontal se encuentran el puerto USB Tipo-C para la
alimentación eléctrica y el interruptor de encendido/apagado (Switch ON/OFF), facilitando tanto la operación diaria como el acceso para mantenimiento. Finalmente, el panel frontal incorpora el logotipo EcoAlerta.
① | Apertura circular y soporte de sensor UV (Tapa superior) | PLA
② | Rejillas de ventilación lineales | PLA
③ | Interruptor de encendido (Switch ON/OFF) | Componente electrónico
④ | Prensaestopa PG7 | Nylon (PA66)
⑤ | Conector USB Tipo-C hembra para montaje en panel | Componente electrónico
⑥ | Microcontrolador ESP32 y placa perforada | Componentes electrónicos
⑦ | Sensor temp./humedad (DHT22) | Componente electrónico
⑧ | Sensor UV (UV SENS) | Componente electrónico
⑨ | Carcasa exterior rectangular (base) | PLA
⑩ | Panel frontal con logo | PLA
⑪ | Tapa protectora | PLA

MODIFICADO POR:
- Espinoza Mayta Adriana
- Palacios Ochoa Jose Elias
- Santos Almonte Jesilin

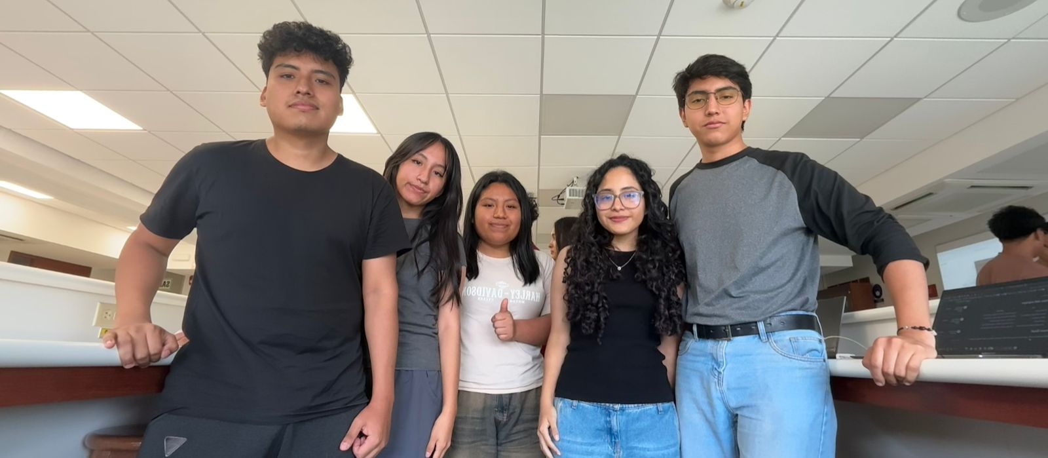
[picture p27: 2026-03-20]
Recursos/Imágenes/Fotos en grupo/Fotos Grupales/Foto grupal.jpg

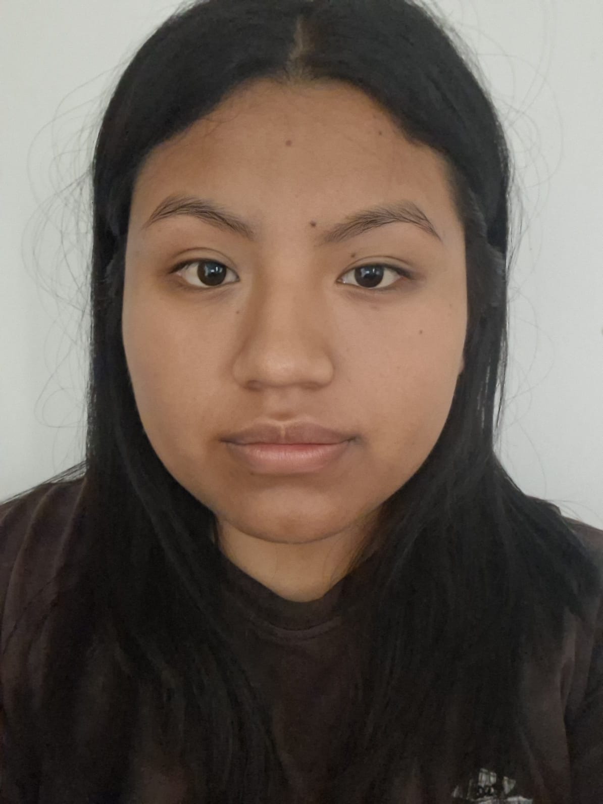
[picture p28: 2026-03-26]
Recursos/Imágenes/Fotos en grupo/Fotos individuales/Jesilin Santos.jpeg

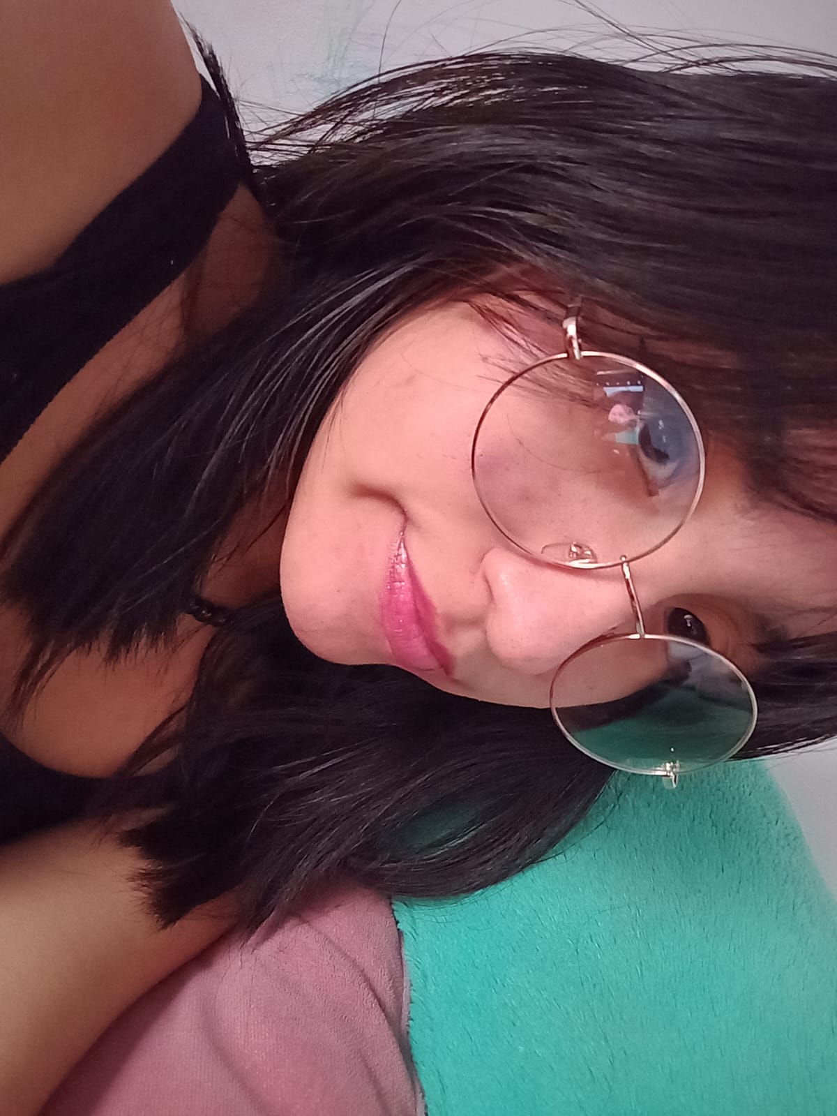
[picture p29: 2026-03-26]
Recursos/Imágenes/Fotos en grupo/Fotos individuales/Adriana Espinoza.jpeg

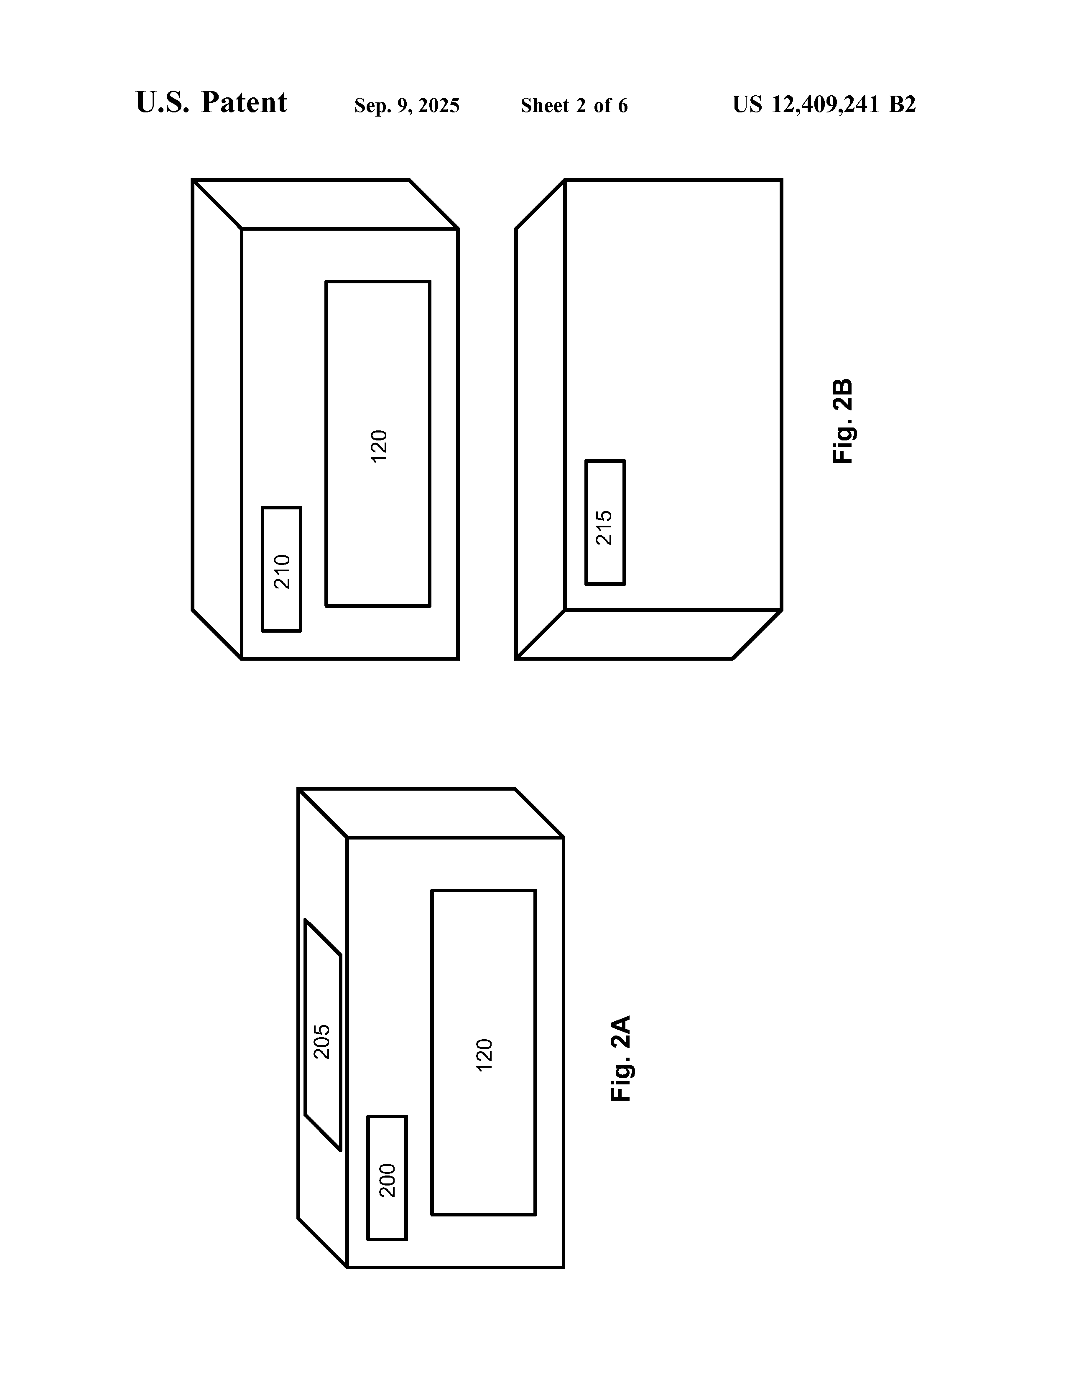
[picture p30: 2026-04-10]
Recursos/Imágenes/Fotos de patentes/patente1.png

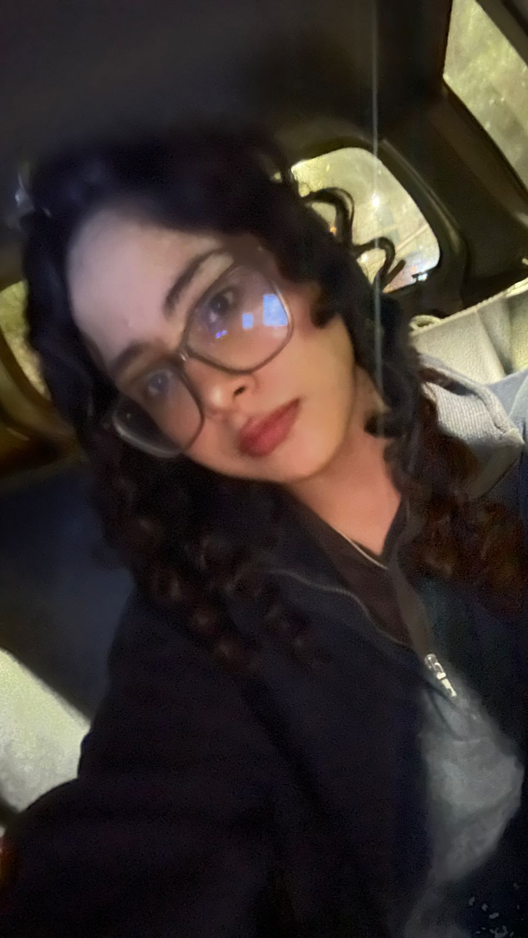
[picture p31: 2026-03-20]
Recursos/Imágenes/Fotos en grupo/Fotos individuales/Saori Jimenez.jpg

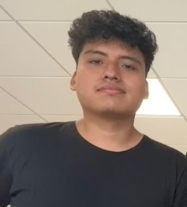
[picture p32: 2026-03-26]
Recursos/Imágenes/Fotos en grupo/Fotos individuales/Jose Palacios.png

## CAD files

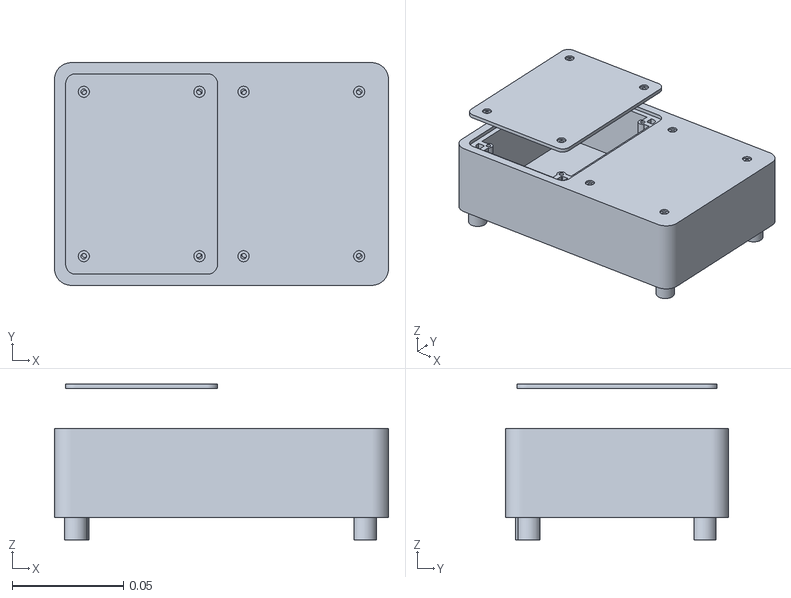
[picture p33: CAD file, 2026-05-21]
FundDiseño/Talleres/taller_10/onshape/Ecoalerta - Modelado 3D - V1.stl
0.15 x 0.1 x 0.07

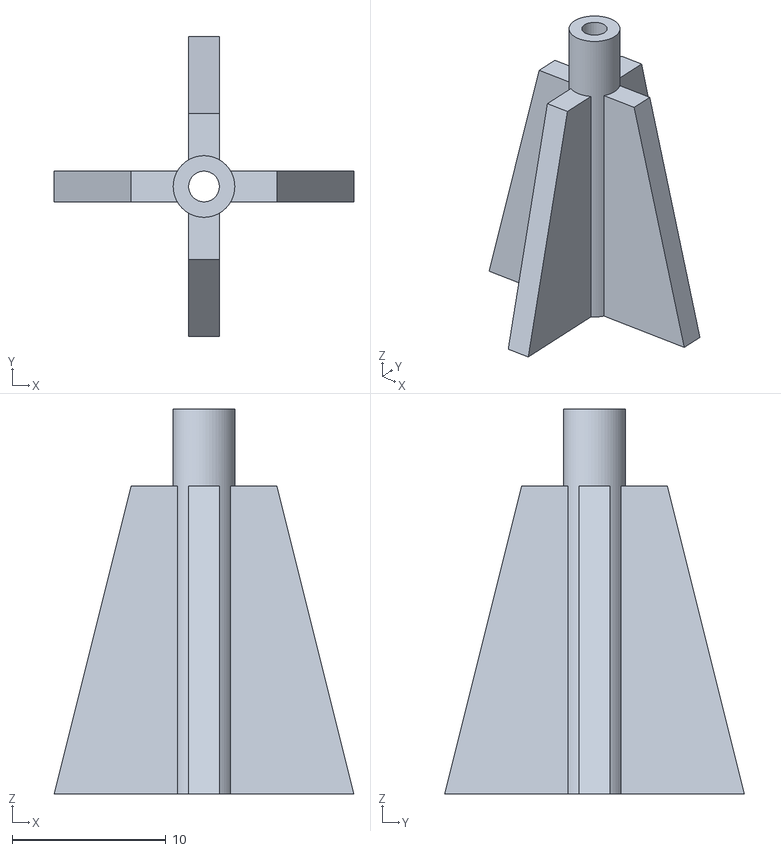
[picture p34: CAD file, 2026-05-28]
Proyecto/MóduloMecánico/v1/Onshape/Partes/Part Studio 3 - Part 18.stl
19.5 x 19.5 x 25.0

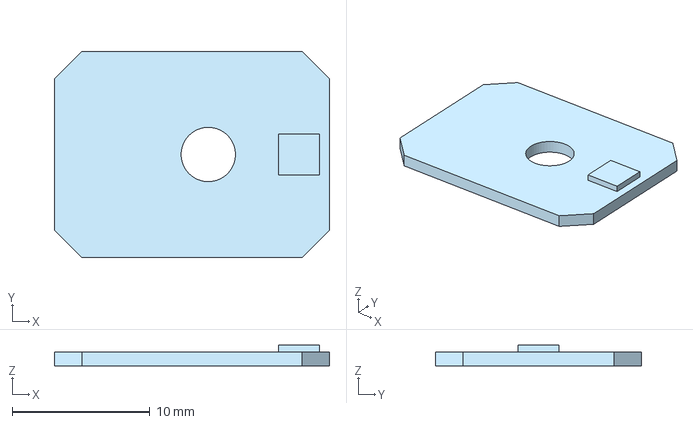
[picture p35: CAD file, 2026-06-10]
Proyecto/MóduloMecánico/vfinal/Oneshape/Ensamble/Importaciones/UV SENS.step
20.0 x 15.0 x 1.50 mm

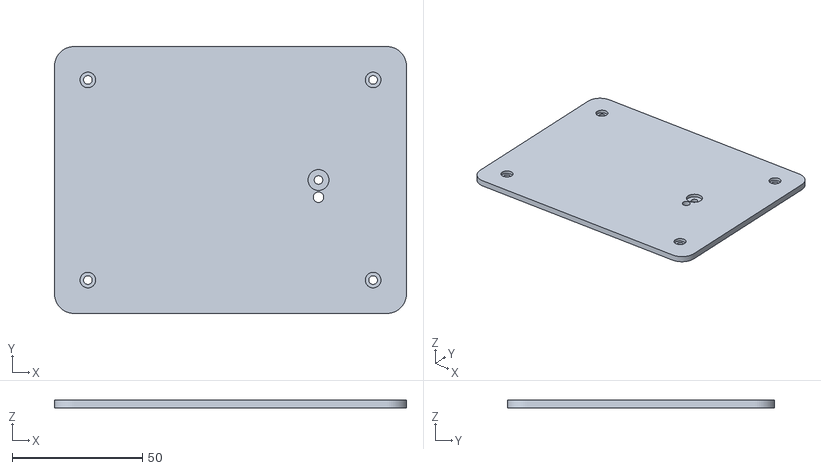
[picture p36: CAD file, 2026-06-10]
Proyecto/MóduloMecánico/vfinal/Oneshape/Partes/Archivos STL/Tapa de los sensores.stl
135.0 x 102.4 x 3.00

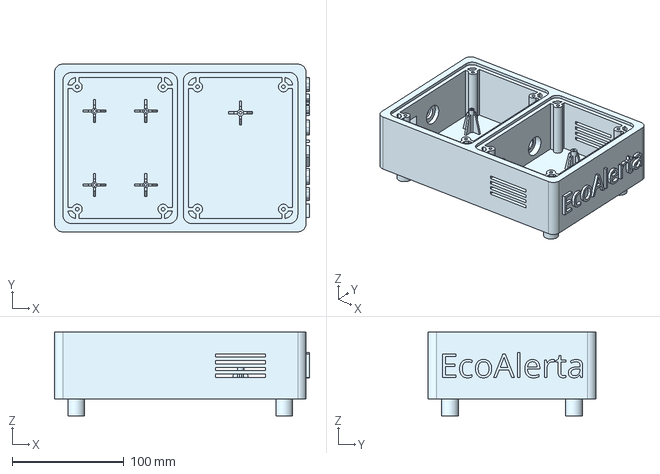
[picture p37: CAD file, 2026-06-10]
Proyecto/MóduloMecánico/vfinal/Oneshape/Partes/Contenedor.step
228.0 x 150.0 x 75.0 mm

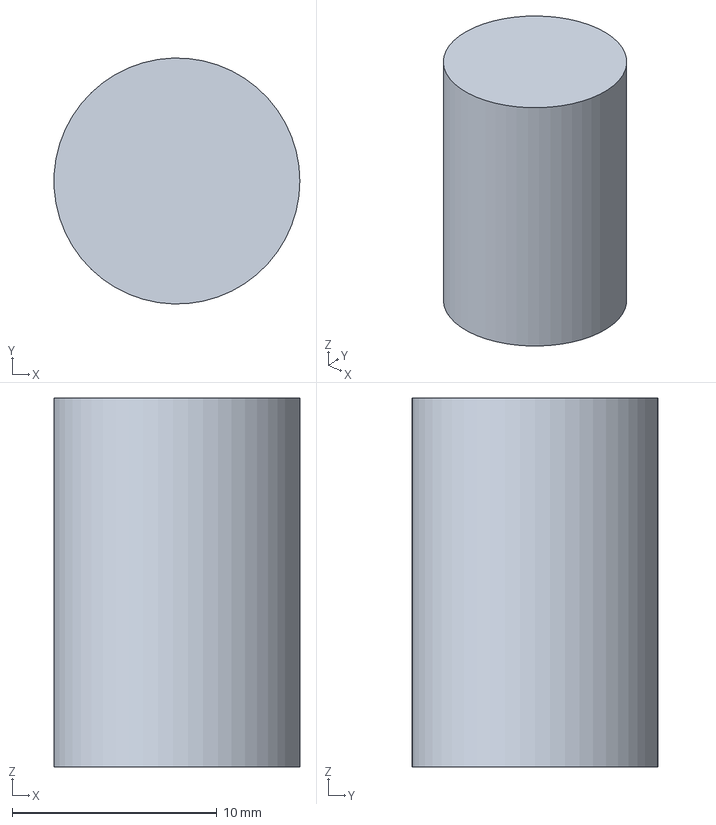
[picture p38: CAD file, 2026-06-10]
Proyecto/MóduloMecánico/vfinal/Oneshape/Ensamble/Importaciones/Chassis Connector.step
12.0 x 12.0 x 18.0 mm

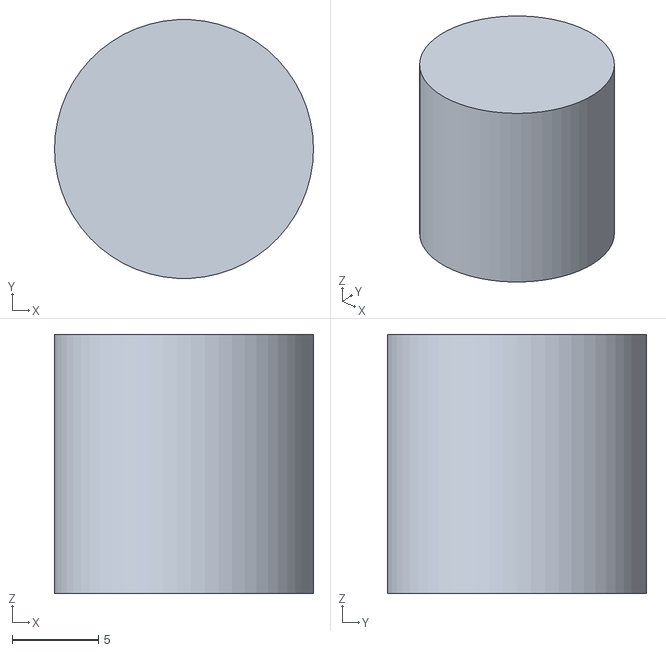
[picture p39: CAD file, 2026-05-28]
Proyecto/MóduloMecánico/v1/Onshape/Partes/Part Studio 3 - Part 8.stl
15.0 x 15.0 x 15.0

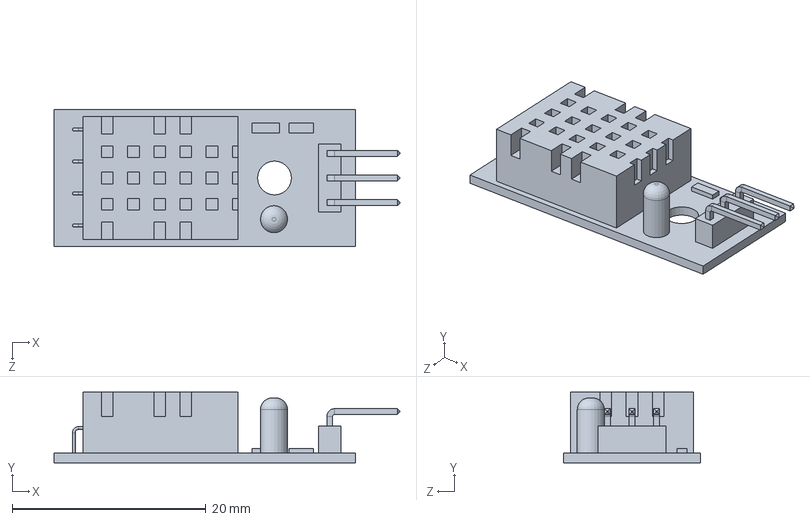
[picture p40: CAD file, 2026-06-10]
Proyecto/MóduloMecánico/vfinal/Oneshape/Ensamble/Importaciones/DHT11 sensor.SLDPRT
35.7 x 7.30 x 14.1 mm

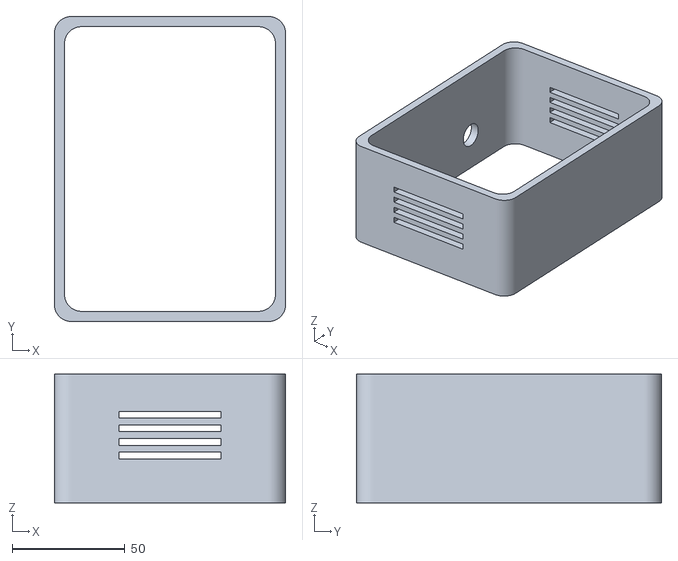
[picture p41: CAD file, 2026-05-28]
Proyecto/MóduloMecánico/v1/Onshape/Partes/Part Studio 3 - Part 3.stl
102.4 x 135.0 x 57.0

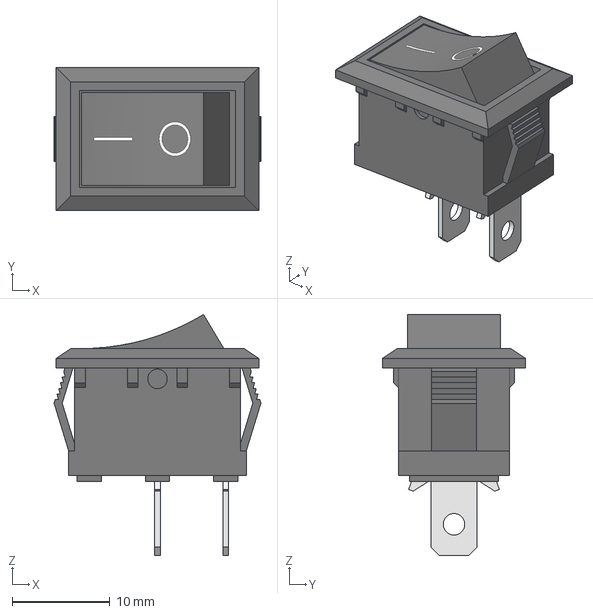
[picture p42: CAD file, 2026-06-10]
Proyecto/MóduloMecánico/vfinal/Oneshape/Ensamble/Importaciones/Rocker Switch On Off.step
21.2 x 14.7 x 24.7 mm

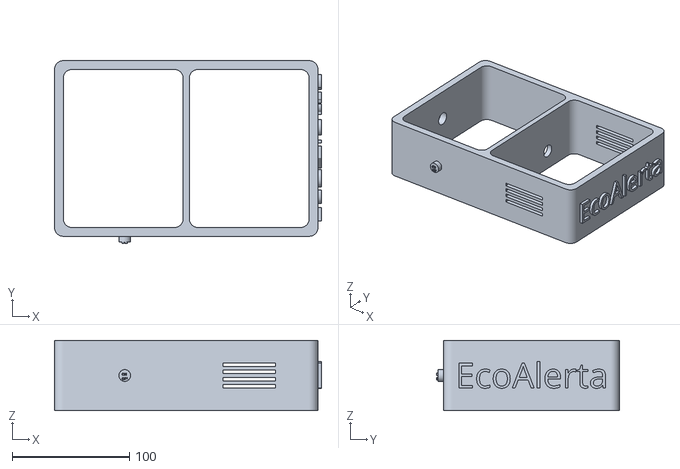
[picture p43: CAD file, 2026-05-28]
Proyecto/MóduloMecánico/v1/Onshape/Partes/Part Studio 3 - Part 1.stl
228.0 x 156.0 x 60.0

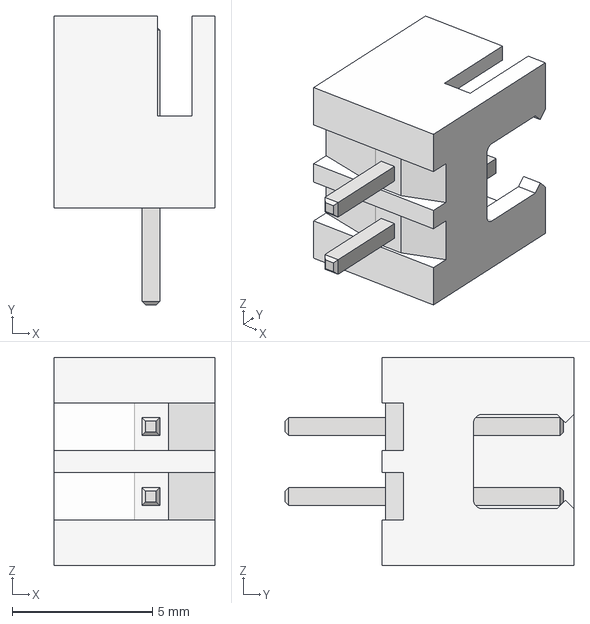
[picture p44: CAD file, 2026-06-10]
Proyecto/MóduloMecánico/vfinal/Oneshape/Ensamble/Importaciones/JST 2pin.stp
5.73 x 10.3 x 7.43 mm

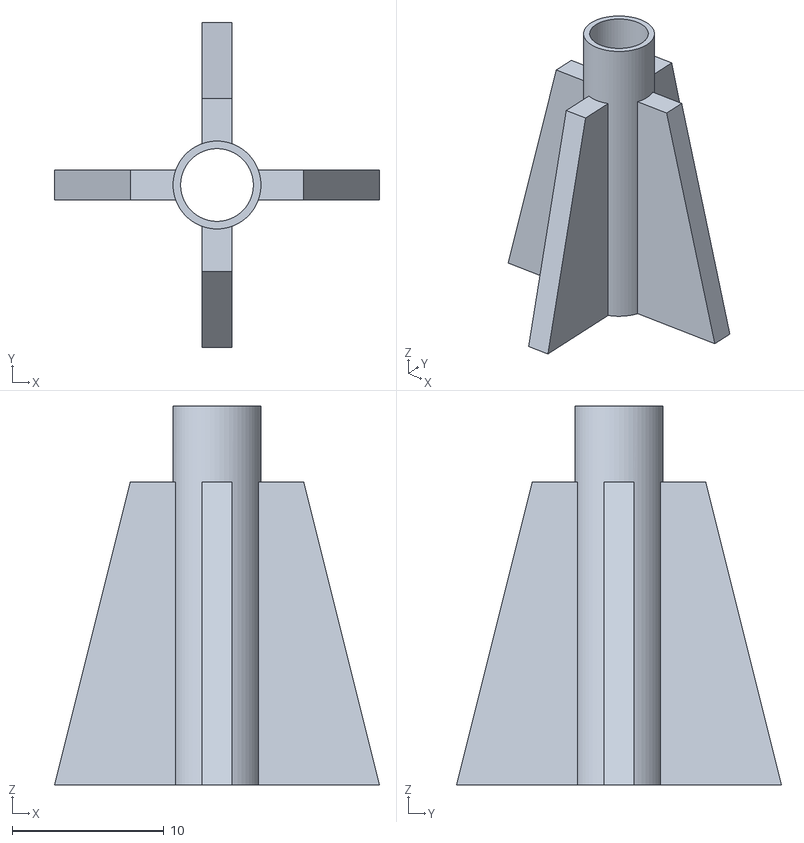
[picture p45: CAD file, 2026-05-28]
Proyecto/MóduloMecánico/v1/Onshape/Partes/Part Studio 3 - Part 22.stl
21.4 x 21.4 x 25.0

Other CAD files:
Proyecto/MóduloMecánico/v1/Onshape/Partes/Part Studio 3 - Part 21.stl
Proyecto/MóduloMecánico/vfinal/Oneshape/Partes/Archivos STL/Tapa del ESP32.stl
Proyecto/MóduloMecánico/vfinal/Oneshape/Partes/Tapa del ESP32.step
Proyecto/MóduloMecánico/vfinal/Oneshape/Partes/Archivos STL/Contenedor.stl
Proyecto/MóduloMecánico/vfinal/Oneshape/Partes/Tapa de los sensores.step
Proyecto/MóduloMecánico/v1/Onshape/Partes/Part Studio 3 - Part 10.stl
Proyecto/MóduloMecánico/v1/Onshape/Partes/Part Studio 3 - Part 11.stl
Proyecto/MóduloMecánico/v1/Onshape/Partes/Part Studio 3 - Part 12.stl
Proyecto/MóduloMecánico/v1/Onshape/Partes/Part Studio 3 - Part 13.stl
Proyecto/MóduloMecánico/v1/Onshape/Partes/Part Studio 3 - Part 14.stl
Proyecto/MóduloMecánico/v1/Onshape/Partes/Part Studio 3 - Part 15.stl
Proyecto/MóduloMecánico/v1/Onshape/Partes/Part Studio 3 - Part 16.stl
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

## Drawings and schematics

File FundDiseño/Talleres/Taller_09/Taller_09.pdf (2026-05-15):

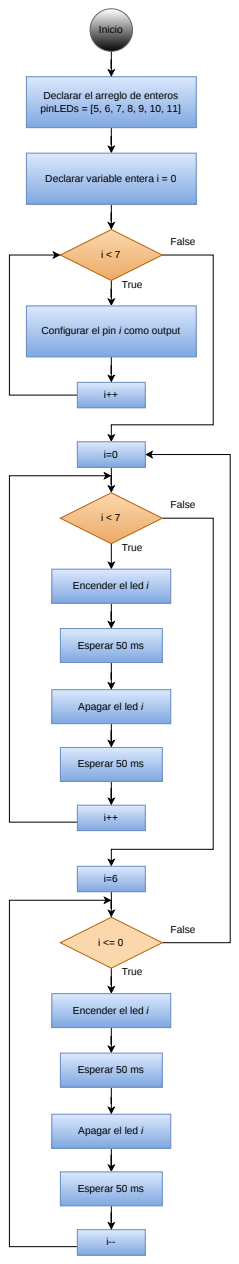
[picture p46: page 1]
Esperar 50 ms; Inicio; True; False

Declarar el arreglo de enteros
pinLEDs = [5, 6, 7, 8, 9, 10, 11]

Declarar variable entera i = 0

Configurar el pin i como output

True

Encender el led i

Apagar el led i

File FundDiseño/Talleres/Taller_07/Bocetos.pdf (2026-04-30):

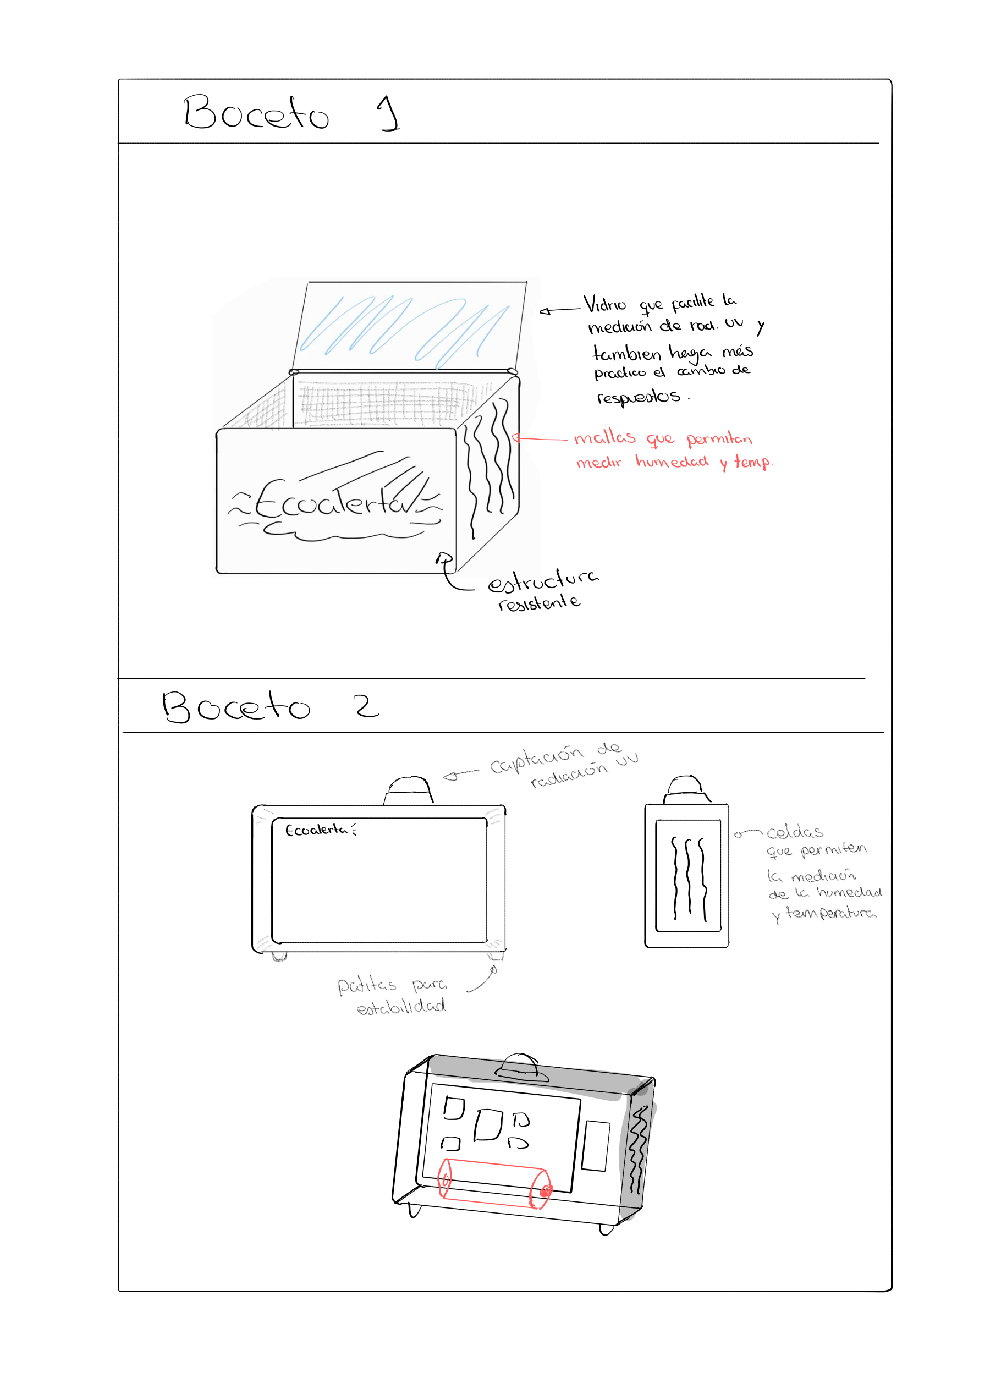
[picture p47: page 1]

∴∴i"

' | esive

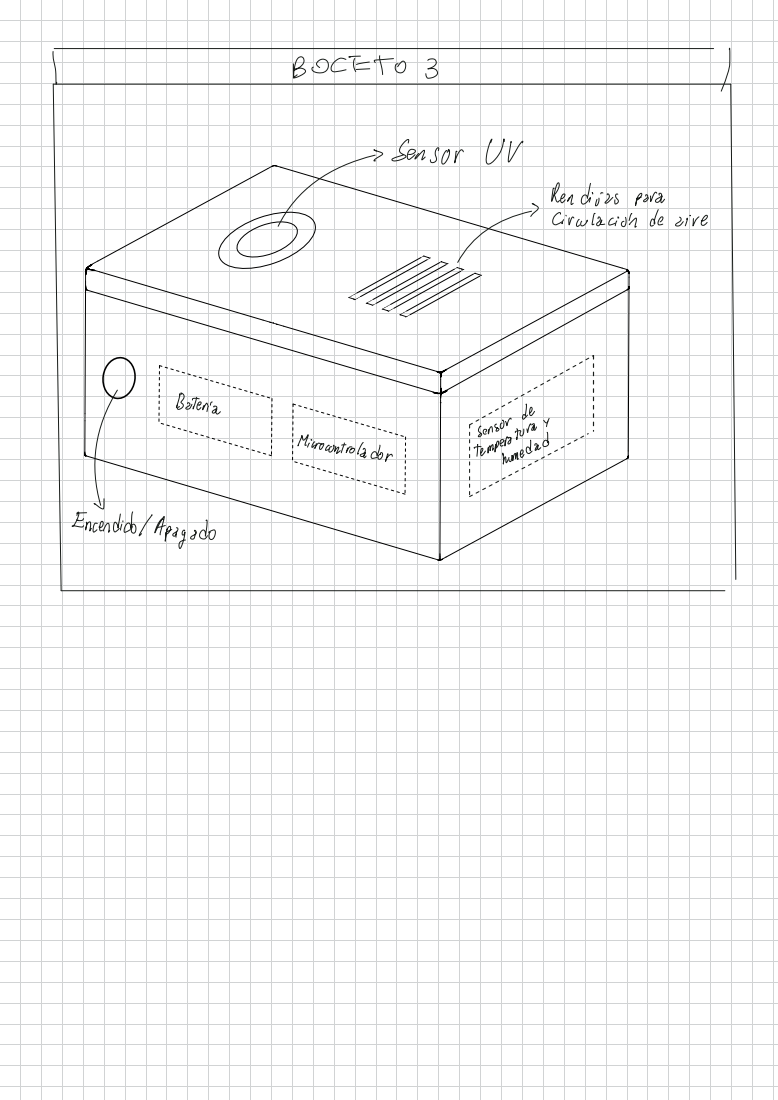
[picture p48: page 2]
BOCETO; > Sensor; Bateria; ziIx; Microcontrolador

Encendido/Apago do

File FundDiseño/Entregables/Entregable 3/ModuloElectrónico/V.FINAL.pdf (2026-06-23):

Alimentación | Microcontrolador

# Sensor de

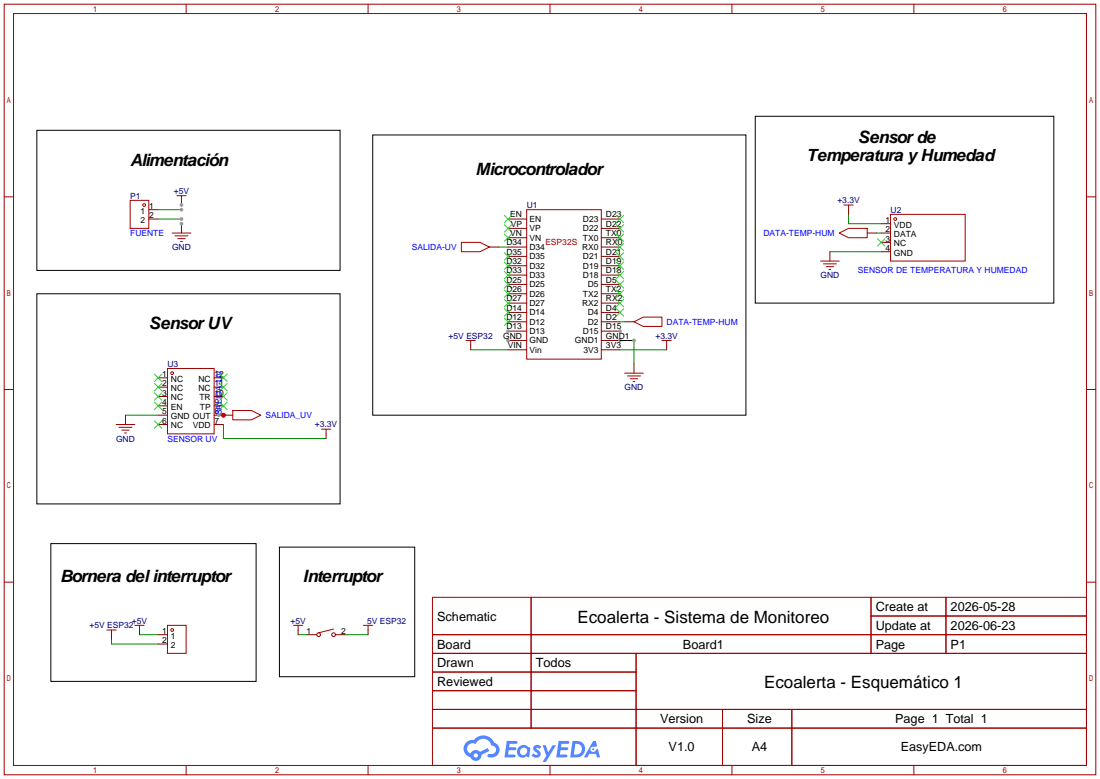
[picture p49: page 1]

SENSOR DE TEMPERATURA Y HUMEDAD

Schematic | Ecoalerta - Sistema de Monitoreo | Create at | 2026-05-28

Update at | 2026-06-23

Board | Board1 | Page | P1
Drawn | Todos | Ecoalerta - Esquemático 1
Reviewed

Version | Size | Page 1 Total 1
V1.0 | A4 | EasyEDA.com

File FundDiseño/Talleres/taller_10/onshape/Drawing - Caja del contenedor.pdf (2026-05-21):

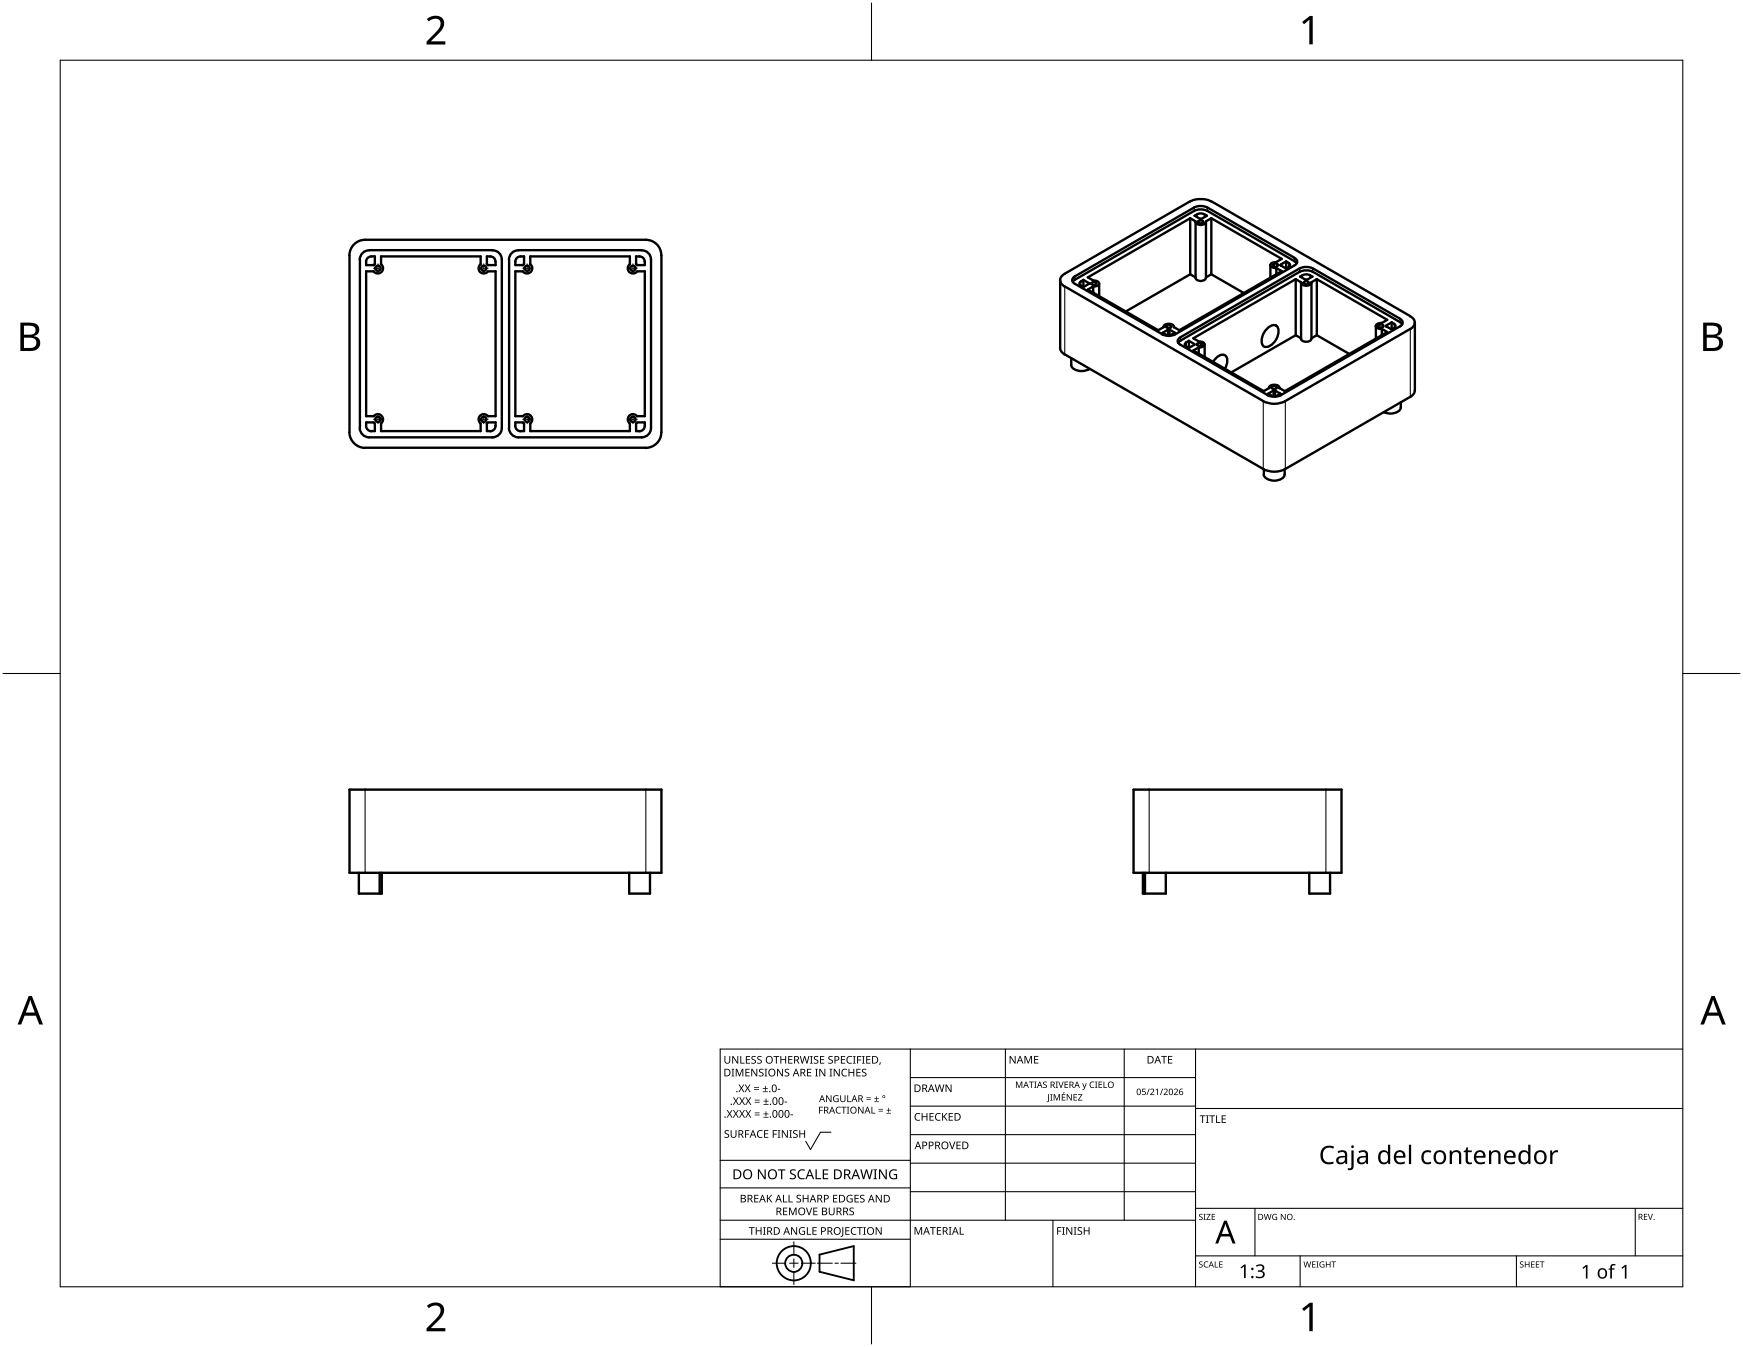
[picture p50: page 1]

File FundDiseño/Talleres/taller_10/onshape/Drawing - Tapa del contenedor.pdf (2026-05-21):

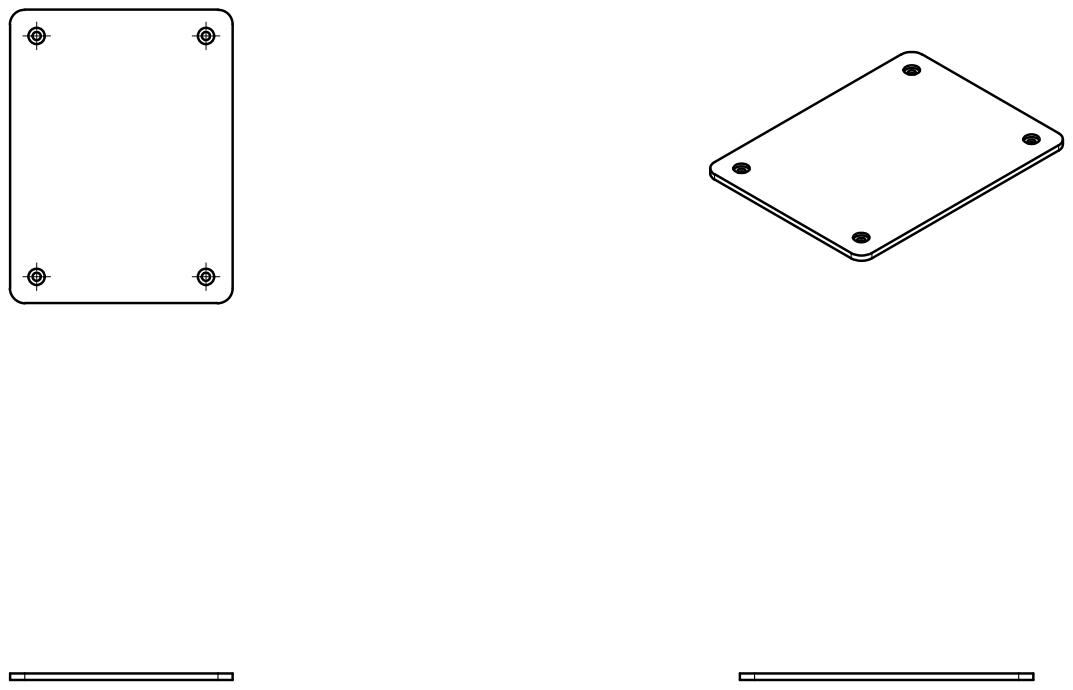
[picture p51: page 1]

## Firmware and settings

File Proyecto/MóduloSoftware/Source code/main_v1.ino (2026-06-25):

#include "DHT.h"
#include <WiFi.h>
#include <HTTPClient.h> // Cambiamos WebServer por HTTPClient

// --- Configuración de Red ---
const char* ssid = "GhostProtocol";
const char* password = "guel3645";

// --- Configuración del Backend (PocketBase) ---
// Reemplaza con la URL pública que generaste en Railway
const char* serverUrl = "https://usingpocketbasev1-production.up.railway.app/api/collections/environment_data/records";

// --- Configuración de Sensores ---
#define DHTPIN 15
#define DHTTYPE DHT11
DHT dht(DHTPIN, DHTTYPE);

const int UV_PIN = 34;

float leerVoltajeUV() {
  const int muestras = 100;
  long suma = 0;

  for (int i = 0; i < muestras; i++) {
    suma += analogRead(UV_PIN);
    delay(2);
  }

  float promedioADC = suma / (float)muestras;
  float voltaje = (promedioADC / 4095.0) * 3.3;

  return voltaje;
}

void enviarDatosAlBackend() {
  // 1. Verificar conexión WiFi antes de proceder
  if (WiFi.status() != WL_CONNECTED) {
    Serial.println("Sin conexión WiFi. Intentando reconectar...");
    WiFi.disconnect();
    WiFi.begin(ssid, password);
    return;
  }

  // 2. Leer las variables de los sensores
  float humedad = dht.readHumidity();
  float temperatura = dht.readTemperature();
  float voltajeUV = leerVoltajeUV();
  float uvIndex = voltajeUV / 0.1;

  if (uvIndex < 0) {
    uvIndex = 0;
  }

  Serial.println("\n=== Nuevas lecturas de EcoAlerta ===");
  if (isnan(humedad) || isnan(temperatura)) {
    Serial.println("¡Error crítico: No se pudo leer el sensor DHT11!");
    return; // Cancelamos el envío si no hay datos válidos del DHT
  }

  // Mostrar lecturas en el monitor serie
  Serial.print("Temperatura: ");
  Serial.print(temperatura, 1);
  Serial.println(" °C");
  
  Serial.print("Humedad: ");
  Serial.print(humedad, 1);
  Serial.println(" %");
  
  Serial.print("Voltaje UV: ");
  Serial.print(voltajeUV, 2);
  Serial.println(" V");
  
  Serial.print("Índice UV: ");
  Serial.println(uvIndex, 1);

  // 3. Construir el JSON con los campos exactos de PocketBase
  String json = "{";
  json += "\"temperature\":" + String(temperatura, 1) + ",";
  json += "\"humidity\":" + String(humedad, 1) + ",";
  json += "\"uv_radiation\":" + String(uvIndex, 1);
  json += "}";

  // 4. Inicializar el cliente HTTP y realizar el POST
  HTTPClient http;
  http.begin(serverUrl);
  http.addHeader("Content-Type", "application/json");

  Serial.println("Enviando datos a PocketBase...");
  int httpResponseCode = http.POST(json);

  // 5. Manejo de errores y respuestas del servidor
  if (httpResponseCode > 0) {
    Serial.print("Respuesta del servidor (Código HTTP): ");
    Serial.println(httpResponseCode);
    if (httpResponseCode == 200 || httpResponseCode == 201) {
      Serial.println("¡Datos guardados exitosamente!");
    } else {
      Serial.println("Error: Verifica que las API Rules de la colección sean públicas.");
    }
  } else {
    Serial.print("Fallo en la conexión HTTP. Código de error: ");
    Serial.println(http.errorToString(httpResponseCode).c_str());
  }

  http.end(); // Liberar recursos
  Serial.println("====================================");
}

void setup() {
  Serial.begin(115200);
  dht.begin();

  Serial.print("Conectando a WiFi");
  WiFi.begin(ssid, password);

  while (WiFi.status() != WL_CONNECTED) {
    delay(500);
    Serial.print(".");
  }

  Serial.println("\nWiFi conectado con éxito");
  Serial.print("IP asignada: ");
  Serial.println(WiFi.localIP());
  
  // Realizar un envío inicial inmediatamente al encender el dispositivo
  enviarDatosAlBackend();
}

void loop() {
  // Frecuencia de envío recomendada: Cada 5 minutos (300000 milisegundos)
  // Esto evita saturar el backend gratuito y es más que suficiente para monitoreo ambiental
  delay(10000);
  enviarDatosAlBackend();
}

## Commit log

2026-03-19 Plantilla de repositorio
    [WeatherStation_v2_Base_v2.stl, WeatherStation_v2_windmill_v4.stl]
2026-03-20 cambio de jessilin
2026-03-21 Create Entregables 📚
2026-03-26 Expand README with project details and requirements
    Added project description and requirements for a device that monitors temperature, humidity, and UV radiation.
2026-03-26 Revise cost details for ESP32 and sensors
    Updated cost estimates for ESP32 and sensors in the project description.
2026-05-03 Rename FundDiseño/Talleres/Taller_07/Matias Rivera - Introduction to Onshape Assemblies.pdf to FundDiseño/Talleres/Taller_07/Certificado Introduction to Onshape Assemblies/Matias Rivera - Introductio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
2026-06-10 Modelado 3D v4.0
    [Chassis Connector.step, Contenedor.step, Contenedor.stl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]
2026-06-11 Entregable 3
    [Chassis Connector.step, Contenedor.step, Contenedor.stl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]
2026-06-24 Revise and update README for UV monitoring devices
2026-06-25 Update and rename Proyecto/MóduloElectrónico/README.md to Proyecto/Descripción de versiones y mejoras por versión ecoalerta.md
2026-06-25 Rename README.md to Descripción y aporte de productos.md
2026-06-25 Rename README (2).md to Descripción y aporte de tesis.md
2026-06-25 Descripción de versiones y mejoras por versión.md
